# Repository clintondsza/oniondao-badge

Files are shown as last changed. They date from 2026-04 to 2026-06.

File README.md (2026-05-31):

# OnionDAO Badge

An open-source, hacker-conference-style electronic badge built around the
**ESP32-S3-WROOM-1-N8R8** (8 MB flash + 8 MB Octal PSRAM), with swappable
RF / audio / storage modules, an e-paper
(or TFT) display socket, a secure element, an I²C IO expander for the button
matrix, and dual side-mounted expansion ports for hardware mods.

Designed in **KiCad 9.0.3**. The hardware (schematics, PCB, BOM, fabrication
outputs, STEP model) lives in [`pcb/`](pcb). The software lives in
[`software/`](software) and is community-driven — PRs welcome.

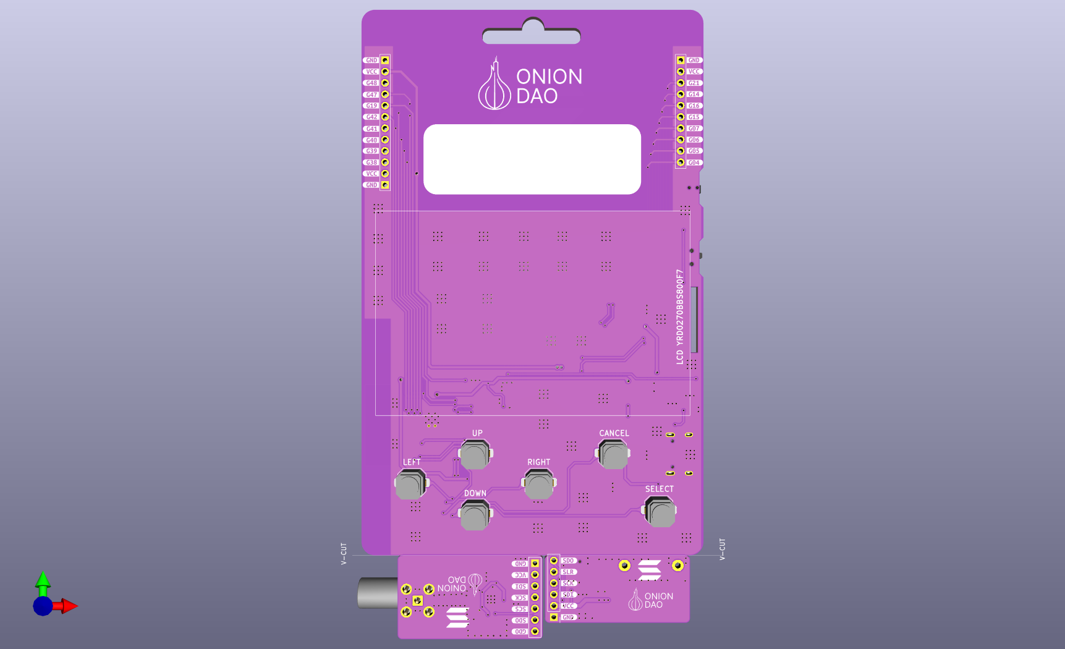
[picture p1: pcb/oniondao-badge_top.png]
Top

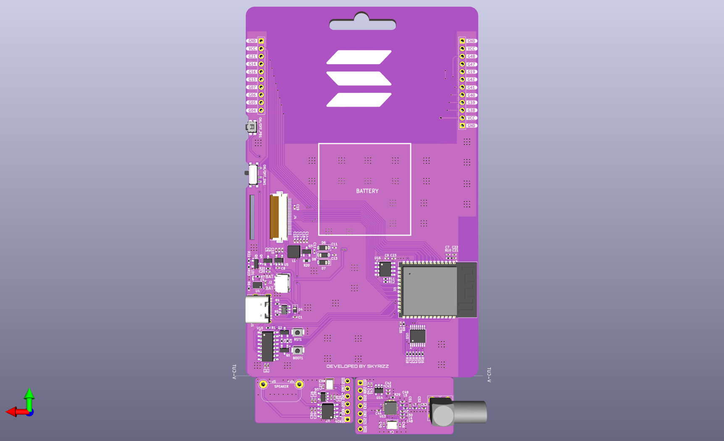
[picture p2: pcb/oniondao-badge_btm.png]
Bottom


---

## Table of Contents

- [At a Glance](#at-a-glance)
- [Block Diagram](#block-diagram)
- [Repository Layout](#repository-layout)
- [Hardware Documentation](#hardware-documentation)
- [Quick Start (Software)](#quick-start-software)
- [Pinout Cheat Sheet](#pinout-cheat-sheet)
- [Contributing Software Mods & Guides](#contributing-software-mods--guides)
- [License](#license)

---

## At a Glance

| | |
|---|---|
| **MCU** | Espressif **ESP32-S3-WROOM-1-N8R8** (Wi-Fi + BT 5.0 LE, dual-core Xtensa LX7) |
| **Memory** | 8 MB quad-SPI flash (`N8`) + 8 MB **Octal-SPI (OPI)** PSRAM (`R8`) |
| **USB / Serial** | WCH **CH340C** USB-UART bridge w/ DTR/RTS auto-reset |
| **Secure Element** | Microchip **ATECC608B-SSHDA** (I²C, power-gated) |
| **IO Expander** | TI **TCA9534** (I²C, addr `0x20`) driving the 6-button matrix (PB1–PB6) |
| **Display** | 24-pin socket (`J4`) — E-Ink / TFT SPI with `BUSY`, `RST`, `DC`, `CS`, `SCK`, `MOSI` |
| **Audio (mod)** | NS4168 I²S amplifier + SPH0641 PDM mic (Sound Module) |
| **Sub-GHz (mod)** | TI **CC1101** SPI radio (315/433/868/915 MHz) |
| **Expansion** | Left port `J8` (10 pin) + Right port `J10` (10 pin) — VCC / GND + GPIO |
| **GPIO Used** | 28 of the available ESP32-S3 GPIOs |
| **Power Gate** | Q5 (SS8050) on `GPIO18` enables the peripheral `PWR` rail |

## Block Diagram

```
                              ┌────────────────────────┐
        USB-C ── CH340C ──────│ UART0  GPIO43/44       │
                              │                        │
   ┌── BOOT btn ── GPIO0 ─────│ STRAP                  │
   │                          │                        │
   │   ATECC608B ──┬─ SCL G9 ─│ I²C0                   │
   │   TCA9534  ──┘  SDA G10  │   ◄── INT G1 (PBINT)   │
   │                          │                        │
   │   J4 Display ─SPI──── G11/12/13/14/17/21          │
   │                          │                        │
   │   J8 Left   ── G48/47/19/42/41/40                  │  ESP32-S3-WROOM-1
   │   J10 Right ── G38/39/16/15/7/6/5/4                │
   │                          │                        │
   │   GPIO18 ──── Q5 ────────│ PWR rail to gated peripherals
   │   GPIO8  ──── SE_EN  ────│ ATECC608B power gate
   │                          └────────────────────────┘
   │
   └── PB1..PB6 ── TCA9534 P0..P5 ──► INT line ── GPIO1
```

## Repository Layout

```
oniondao-badge/
├── README.md                   ← you are here
├── pcb/                        ← KiCad 9.0.3 hardware sources
│   ├── oniondao-badge.kicad_pro
│   ├── oniondao-badge.kicad_sch         (top-level schematic)
│   ├── oniondao-badge.kicad_pcb         (board layout)
│   ├── CC1101_MOD.kicad_sch              (Sub-GHz RF module)
│   ├── SOUND_MOD.kicad_sch               (I²S amp + PDM mic)
│   ├── oniondao-badge.step              (full 3D model)
│   ├── 3d/                               (additional STEP assets)
│   ├── production/                       (gerbers, BOMs, netlist)
│   ├── oniondao-badge_top.png           (board render — top)
│   ├── oniondao-badge_btm.png           (board render — bottom)
│   └── oniondao badge.html                   (interactive IO reference)
├── docs/
│   ├── HARDWARE.md             ← deep dive on every subsystem
│   ├── PINOUT.md               ← full GPIO ↔ net ↔ peripheral table
│   ├── MODULES.md              ← swappable modules & their pinmaps
│   └── CONTRIBUTING.md         ← how to PR a mod / guide / example
└── software/
    ├── README.md
    ├── examples/               ← minimal, single-feature firmware
    ├── guides/                 ← end-to-end how-tos
    └── mods/                   ← community firmware mods & forks
```

> **Tip:** open [`pcb/oniondao badge.html`](pcb/oniondao%20badge.html) in a browser for
> a colour-coded, searchable, filterable view of the IO table. It is the
> source of truth that [`docs/PINOUT.md`](docs/PINOUT.md) mirrors in markdown.

## Hardware Documentation

The docs are split so you can read just what you need:

- **[docs/HARDWARE.md](docs/HARDWARE.md)** — overview of every subsystem on
  the board: power, USB/UART, boot circuit, I²C bus, display socket, secure
  element, button matrix, expansion ports.
- **[docs/PINOUT.md](docs/PINOUT.md)** — the complete GPIO map: every used
  pin, its net, direction, interface, and the peripheral it connects to.
- **[docs/MODULES.md](docs/MODULES.md)** — the swappable modules
  (CC1101 / Sound) and the shared-GPIO assignments. Read
  this **first** if you are writing firmware that touches the side ports.

### Manufacturing

- Gerbers, drill files, and pick-and-place are zipped in
  [`pcb/production/oniondao-badge.zip`](pcb/production/oniondao-badge.zip).
- BOMs per variant: `bom-list_cc1101.xlsx`, `bom-list_sound.xlsx`,
  `bom-list_lanyard_new.xlsx`.
- IPC-D-356 netlist: `pcb/production/netlist.ipc`.

## Quick Start (Software)

The badge enumerates as a standard CH340 serial port, so any ESP32-S3 toolchain
works at the hardware level — **ESP-IDF**, **Arduino-ESP32**, **PlatformIO**,
**MicroPython**, **CircuitPython**.

> **Building the firmware in this repo?** The projects under `software/` are
> **ESP-IDF v5.5.x** projects (with the Arduino core as a component). Follow the
> step-by-step **[VS Code + ESP-IDF setup guide](software/guides/esp-idf-vscode-setup.md)**
> to install the toolchain and flash a badge.

### Memory configuration (N8R8)

The populated module is an **ESP32-S3-WROOM-1-N8R8**: 8 MB flash + 8 MB PSRAM
in **Octal (OPI)** mode. PSRAM will not initialise unless you select Octal
mode explicitly — quad-mode defaults silently disable it. Set per toolchain:

| Toolchain | Flash | PSRAM |
|---|---|---|
| **ESP-IDF** (`sdkconfig`) | `CONFIG_ESPTOOLPY_FLASHSIZE_8MB=y` | `CONFIG_SPIRAM=y`, `CONFIG_SPIRAM_MODE_OCT=y`, `CONFIG_SPIRAM_SPEED_80M=y` |
| **Arduino-ESP32** (boards menu) | `Flash Size = 8MB` | `PSRAM = OPI PSRAM` |
| **PlatformIO** | `board_build.flash_size = 8MB` | `board_build.arduino.memory_type = qio_opi` + `-DBOARD_HAS_PSRAM` |

The firmware projects under [`software/`](software) already carry these settings
in their `sdkconfig.defaults` — see the
[VS Code + ESP-IDF setup guide](software/guides/esp-idf-vscode-setup.md).

### Programming

1. Plug in USB-C. The CH340C + DTR/RTS auto-reset circuit (Q1/Q2 on
   `GPIO0`/`EN`) means **you do not need to hold BOOT** — the toolchain
   strobes it for you.
2. If auto-reset ever fails: hold **BOOT** (the SW button tied to `GPIO0`),
   tap **RESET**, release **BOOT**, then flash.

### Minimal Arduino example

```cpp
// Blink the peripheral power rail and read the BOOT button.
#define PWR_EN   18    // Q5 base — enables peripheral VCC
#define BOOT_BTN 0     // strapping pin, doubles as user button after boot

void setup() {
  Serial.begin(115200);          // CH340C on UART0 (GPIO43/44)
  pinMode(PWR_EN, OUTPUT);
  pinMode(BOOT_BTN, INPUT_PULLUP);
  digitalWrite(PWR_EN, HIGH);    // power-up peripherals
}

void loop() {
  Serial.printf("BOOT btn: %d\n", digitalRead(BOOT_BTN));
  delay(250);
}
```

### Reading the 6 user buttons

The PB1–PB6 buttons are wired to the **TCA9534** IO expander (I²C
addr `0x20`), not directly to the ESP32. A button press pulls `PBINT`
(`GPIO1`) low; read the expander register over I²C to find which one.

```cpp
#include <Wire.h>
#define SCL_PIN 9
#define SDA_PIN 10
#define PBINT   1
#define TCA9534 0x20

void buttonISR();

void setup() {
  Wire.begin(SDA_PIN, SCL_PIN, 400000);   // I²C Fast Mode
  pinMode(PBINT, INPUT_PULLUP);
  attachInterrupt(PBINT, buttonISR, FALLING);
}

void buttonISR() {
  Wire.beginTransmission(TCA9534);
  Wire.write(0x00);                       // Input port register
  Wire.endTransmission(false);
  Wire.requestFrom(TCA9534, 1);
  uint8_t state = Wire.read();            // bit N low = PB(N+1) pressed
  // ... dispatch on `state`
}
```

See [`software/examples/`](software/examples) for working firmware
covering display, audio, RF, and the secure element.

## Pinout Cheat Sheet

Source of truth: [`pcb/oniondao badge.html`](pcb/oniondao%20badge.html) — open it in
a browser for the filterable view. The markdown mirror is
[`docs/PINOUT.md`](docs/PINOUT.md).

### Core / UART / Boot

| GPIO | Net | Dir | Peripheral | Notes |
|---|-----|-----|---|---|
| `GPIO0`  | `IO0` | IN  | BOOT button + auto-reset Q1/Q2 | **Strapping** — LOW at power-on → download mode |
| `GPIO43` | `TX0` | OUT | CH340C RXD (via R1 220Ω) | UART0 TX |
| `GPIO44` | `RX0` | IN  | CH340C TXD | UART0 RX |
| `GPIO18` | `PWR` | OUT | Q5 SS8050 → peripheral VCC | HIGH = enable power gate |

### I²C Bus (Security Chip + IO Expander)

| GPIO | Net | Dir | Peripheral | Notes |
|---|-----|-----|---|---|
| `GPIO9`  | `SCL` | OUT | TCA9534 + ATECC608B | 400 kHz max (Fast Mode) |
| `GPIO10` | `SDA` | I/O | TCA9534 + ATECC608B | TCA9534 @ `0x20` |
| `GPIO1`  | `PBINT` | IN  | TCA9534 INT → PB1..PB6 | Active LOW, `attachInterrupt(FALLING)` |
| `GPIO8`  | `SE_EN` | OUT | ATECC608B enable | HIGH = active — power-gate when idle |

### Display Socket J4 (E-Ink / TFT SPI)

| GPIO | Net | Dir | J4 Pin | Function |
|---|-----|-----|---|---|
| `GPIO14` | `RS` | OUT | 3  | Display RESET — LOW ≥10 ms during init |
| `GPIO13` | `DC` | OUT | 11 | Data / Command select (HIGH = data) |
| `GPIO12` | `CS` | OUT | 12 | SPI Chip Select (active LOW) |
| `GPIO11` | `SCK`  | OUT | 13 | SPI Clock |
| `GPIO21` | `BUSY` | IN  | 9  | Busy — wait LOW before next refresh |
| `GPIO17` | `SDI`  | OUT | 23 | SPI MOSI |

### Expansion Ports

| Pin | Left (J8) | Right (J10) |
|-----|---|---|
| 1 | GND | GND |
| 2 | VCC | VCC |
| 3 | `GPIO48`  | `GPIO38` |
| 4 | `GPIO47`  | `GPIO39` |
| 5 | `GPIO19`  | `GPIO16` |
| 6 | `GPIO42`  | `GPIO15` |
| 7 | `GPIO41`  | `GPIO7`  |
| 8 | `GPIO40`  | `GPIO6`  |
| 9 | VCC | `GPIO5`  |
| 10  | GND | `GPIO4`  |

> **Heads-up:** the **Sound Module** and **CC1101 Module** both reuse the
> same set of side-port GPIOs. Only one module's firmware can drive those
> pins at a time. See [`docs/MODULES.md`](docs/MODULES.md) for the exact
> overlap and how to choose at compile time.

## Contributing Software Mods & Guides

We want this badge to be a **playground**. If you wrote a synth, a CC1101
replay tool, an OLED demo, a CTF challenge, a CircuitPython port — open a PR
into [`software/`](software).

1. Pick the right folder:
   - `software/examples/` — one feature, minimal code, no story.
   - `software/guides/` — step-by-step tutorials (markdown + code).
   - `software/mods/` — full firmware projects / forks / variants.
2. Add a folder named after your mod, with a `README.md` describing what it
   does, which GPIOs / modules it requires, and how to build & flash.
3. Open a PR. Use the template in `.github/PULL_REQUEST_TEMPLATE.md`.

Full guidelines: [`docs/CONTRIBUTING.md`](docs/CONTRIBUTING.md).

## License

Hardware sources (KiCad files under `pcb/`) are released under
**CERN-OHL-S v2** unless a file header states otherwise. Software in
`software/` defaults to **MIT** — individual mods may override in their own
folder's `LICENSE` file.

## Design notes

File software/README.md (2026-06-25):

# OnionDAO Badge — Pin Test 🔌

## What is this thing, in one sentence?

This is a little computer program that checks if someone **soldered the
metal pins on a circuit board correctly** — like a doctor giving a checkup
to a freshly-built electronic badge, before anything else gets plugged
into it.

## Wait, what's a "badge" and why does it need a checkup?

The [OnionDAO Badge](https://github.com/OnionDAO-git/oniondao-badge) is a
small electronic gadget (about the size of a name tag) built around a chip
called an **ESP32-S3** — basically a tiny computer brain. People build
these badges by hand, which means **soldering**: melting a bit of metal to
glue wires and pins onto the board so electricity can flow through them.

Soldering by hand is a bit like tying your shoelaces really, really
small — it's easy to do it slightly wrong without noticing. A "bad joint"
(a pin that isn't actually connected, or is touching its neighbor when it
shouldn't be) can make the whole badge act broken later, and it's hard to
tell *why* it's broken unless you check the soldering itself first.

So: **solder first → test with this project → THEN plug in the fun
add-on parts.** That way, if something doesn't work later, you already
know your soldering was fine, and the problem is somewhere else.

## A 30-second crash course on electricity (skip if you already get this)

- **Voltage** is basically "electrical pressure" — like water pressure in a
  pipe. This chip uses two voltage levels to mean something: **0 volts**
  means "off" / "logic 0", and **3.3 volts** means "on" / "logic 1". That's
  it — there's no in-between meaning, it's just a digital on/off switch
  made out of electricity instead of a mechanical lever.
- **GND** (ground) is the "0 volts" reference point that every other
  measurement compares against — like sea level on a map of mountain
  heights. You always put one multimeter probe on GND so the other probe's
  number means something.
- **A pin** is just one little metal leg of the chip (or the header it's
  soldered to) that can be told "be 3.3V" or "be 0V", or can be read to see
  which one it currently is.
- **GPIO** stands for "General Purpose Input/Output" — a fancy way of
  saying "a pin the program can freely turn on/off (output) or read
  (input)," as opposed to pins with one fixed special job.

## What does this program actually check? (3 tests)

Think of it like a 3-question quiz the badge has to pass:

### 1. "Can every pin turn on and off?" (the GPIO toggle test)
The badge has two little plastic connector strips called `J8` and `J10`
sticking out of its sides — each one has several metal pins. This test
makes the chip turn **each pin** on (3.3 volts of electricity) and off
(0 volts) three times in a row, one pin at a time, like flicking a light
switch on and off.

While it does that, **you** hold a multimeter (a tool that measures
electricity) against that same pin and watch the number jump between
`0V` and `3.3V`. If it jumps the way it's supposed to, that pin's solder
joint is good. If it's stuck, or doesn't move, that pin has a soldering
problem.

### 2. "Does the radio chip actually work?" (the CC1101 check)
A **CC1101** is a small radio chip — it can send and receive radio
signals, kind of like a tiny walkie-talkie part. If you've soldered one of
these onto the badge, this test talks to it over a digital connection
called **SPI** (think of SPI as a tiny, very fast, 4-wire conversation
between two chips: one wire to send data, one to receive data, one
"ticking" clock wire so both sides stay in sync, and one "are you
listening?" select wire) and asks it "what are you?" The chip answers back
with two ID numbers, called **PARTNUM** and **VERSION**.

Then, just to be extra sure, the program tells the chip "send me a
ticking clock signal" on one of its wires (called **GDO0**) and
**measures how fast it ticks** by counting how many times the wire
flips between 0V and 3.3V in a tiny 50-millisecond window. If the speed
matches what's expected (about 135,400 ticks per second — which comes
from the chip's internal crystal, divided by 192), that proves the wire
is connected correctly all the way from the chip to the badge — no
multimeter needed for this one, the program checks it automatically!

Why bother measuring a clock instead of just trusting the ID numbers?
Because, surprisingly, **a CC1101 reporting `VERSION = 0x00` is normal**
on plenty of genuine chips — so the ID alone can't tell you "good" from
"bad". A wire that's actually carrying a fast, correct-speed clock signal
is much harder to fake by accident, so it's the stronger proof.

### 3. "Can it actually make a sound?" (the speaker test)
If you've soldered on a **Sound module** (a tiny amplifier chip called an
**NS4168** paired with a microphone chip called an **SPH0641**), this test
sends digital audio data to it over a connection called **I2S** (a
standard way of streaming digital sound between chips — kind of like SPI,
but specialized for audio: it has a clock wire, a "left channel or right
channel right now?" wire, and a data wire) and plays a steady musical note
(440 Hz — the same note an orchestra tunes to before a concert) for
3 seconds.

There's no clever electronic way to "ask" a speaker if it's working — the
only test is **your own ears**. If you hear a clean, steady beep, it
passed. If you hear nothing, or something crackly, the wiring needs a
second look. (The microphone half of the module isn't tested here — only
the speaker/amplifier side.)

A small detail that trips people up: right after the tone finishes, the
program explicitly switches the audio channel off. Without that step, the
sound chip's hardware would keep looping its very last chunk of sound data
forever instead of going quiet — so a properly-finished test should end in
total silence, not a stuck buzzing noise.

### Bonus: it draws the results on the badge's little screen
The badge has a small black-and-white screen (an "e-paper" display — the
same kind of screen used in e-readers like a Kindle). E-paper is special
because, once it draws a picture, **it keeps showing that picture even
with zero power applied** — it only needs electricity for the brief
moment it's actually changing the image, not to keep displaying it. After
each test, the program writes the results right onto that screen, so you
don't even need a computer or Serial Monitor open to see how it went —
just look at the badge itself.

At the very end, the program tells the screen to "hibernate" (go into its
lowest power-use state) since there's nothing left to draw.

## What order does everything happen in? (the boot sequence)

When you plug the badge in and it powers up, here's exactly what happens,
in order — this matches the code in `firmware/main/main.cpp` top to
bottom:

1. **Serial port starts up** at 115200 baud (baud = "how many bits per
   second the text connection sends" — 115200 is just a commonly-used
   speed both sides agree on ahead of time) and waits 2 seconds so you
   have time to open the Serial Monitor before anything important prints.
2. **The screen turns on** and shows "Starting pin test... GPIO toggle
   pass running (watch multimeter now)" — your cue to grab the
   multimeter.
3. **The module power rail switches on** (`PIN_PWR_EN` goes HIGH). This
   badge deliberately routes power to the plug-in modules through a
   transistor controlled by one GPIO, instead of wiring them straight to
   the battery — that way the chip can cut power to modules it isn't
   using, to save battery. The program waits 5 milliseconds for the
   modules' own power supplies to settle before touching them.
4. **Test 1 runs**: all 14 candidate pins toggle HIGH/LOW/HIGH/LOW/HIGH/LOW
   (3 full cycles), one at a time, 1 second per half-cycle — this is your
   multimeter-watching window. The screen updates to "GPIO toggle: DONE".
5. **The CC1101 radio link is set up once** (SPI bus started) and
   **the Sound module is set up once** (I2S channel started, amplifier
   enabled) — both are initialized a single time here and reused, on
   purpose (see the pitfalls section below for why).
6. **Test 2 runs**: the CC1101 link check (ID registers + GDO0 clock
   frequency). Result goes to both the Serial Monitor and the screen.
7. **Test 3 runs**: the 3-second, 440 Hz tone plays through the Sound
   module. Result (well, the fact that it ran) goes to both Serial and
   the screen.
8. **A final summary screen** shows all three results at once, and the
   program settles into doing nothing forever (just an idle loop) — it
   will not repeat any test until you power-cycle or re-flash it.

All three tests run **once** per power-on, then the program just sits
there quietly — it won't keep re-triggering the tone or re-running the
SPI check on a loop.

## What's inside this folder? (a map)

```
oniondao-pin-test/
├── README.md                 ← you are here!
├── docs/
│   └── testing-guide.md      ← a full step-by-step guide, written for
│                                someone who has NEVER used a multimeter
│                                before. Start here if testing is new to you.
├── firmware/                  ← the "real" version of the program
│   ├── main/
│   │   └── main.cpp          ← all the actual test code lives here
│   ├── CMakeLists.txt        ← build instructions (tells the computer
│   │                            how to compile the program)
│   └── sdkconfig.defaults    ← chip configuration settings
├── arduino/
│   └── pin_test.ino          ← a simpler, beginner-friendly version of
│                                test #1 (the pin toggle test) only —
│                                no screen, no radio test, no sound test.
│                                Good if you just want to quickly check
│                                pins using the easier Arduino IDE.
└── components/                ← borrowed code other people wrote, that
                                  this project needs to draw on the
                                  e-paper screen. You don't need to read
                                  or touch these — they're just helper
                                  libraries, tucked in here so this project
                                  works completely on its own without
                                  needing the main badge repo too.
```

A bit more on that `components/` folder, since it's the biggest pile of
files in here and might look intimidating: it contains three popular,
open-source Arduino libraries, copied in as-is so the build doesn't have
to fetch them separately:

- **GxEPD2** — the library that actually knows how to talk to e-paper
  screens (there are hundreds of slightly different e-paper screen models
  in the world; this library supports a huge number of them, which is why
  there are so many similarly-named files in `components/GxEPD2/src/`).
  This badge only uses one of those screen drivers
  (`GxEPD2_270_GDEY027T91`), but the whole library comes along anyway.
- **Adafruit_GFX** — a generic "draw shapes and text" toolkit that GxEPD2
  builds on top of (so the same drawing code style works across all sorts
  of Adafruit displays, not just e-paper).
- **Adafruit_BusIO** — small helper code for talking over SPI/I2C, used
  internally by the other two libraries.

You will never need to edit anything inside `components/` — if you do
need to update one of these libraries, the normal way is to drop in a
newer copy of the whole library, not hand-edit files inside it.

## Which pins go where?

The badge's two connectors are wired to two add-on modules like this:

**CC1101 radio module → connector `J8`:**

| Radio module wire | Goes to badge pin | What it's for |
|---|---|---|
| SDI | G48 | data going INTO the radio chip |
| SCK | G47 | the shared clock "tick" wire |
| SCS | G19 | "are you listening?" select wire |
| SDO | G42 | data coming OUT of the radio chip |
| GDO | G41 | the chip's general-purpose signal pin (used here for the clock test) |

**Sound module → connector `J10`:**

| Sound module wire | Goes to badge pin | What it's for |
|---|---|---|
| SDI | G38 | data wire (despite the name, used as I2S clock input on this badge) |
| SCK | G39 | bit clock for the audio stream |
| SLR (WS) | G16 | word select — "is this sample for the left or right speaker?" |
| SDO | G15 | the actual digital audio data |
| CTR (CTRL) | G07 | turns the amplifier chip on/off |

(Plus a GND-to-GND wire and a VCC-to-VCC wire on each module, for power
and a shared ground reference.) If your own badge is wired differently,
you can change these pin numbers near the top of `firmware/main/main.cpp`.

Every pin the GPIO toggle test cycles through, in the exact order it runs,
straight from `firmware/main/main.cpp` (the Arduino sketch version checks
the same set, just labeled slightly differently since it has to cover
three possible wiring variants at once):

| Pin | Connector / slot | Used for |
|---|---|---|
| G48 | J8 pin 3 | CC1101 SDI |
| G47 | J8 pin 4 | CC1101 SCK |
| G19 | J8 pin 5 | CC1101 SCS |
| G42 | J8 pin 6 | CC1101 SDO |
| G41 | J8 pin 7 | CC1101 GDO |
| G40 | J8 pin 8 | spare (not used by this wiring) |
| G38 | J10 pin 3 | Sound SDI |
| G39 | J10 pin 4 | Sound SCK |
| G16 | J10 pin 5 | Sound SLR |
| G15 | J10 pin 6 | Sound SDO |
| G07 | J10 pin 7 | Sound CTR |
| G06 | J10 pin 8 | spare |
| G05 | J10 pin 9 | spare |
| G04 | J10 pin 10 | spare |

The "spare" pins still get toggled and tested even though no module wire
is currently planned for them — partly to check that header's solder
joint anyway, and partly so the same firmware keeps working if a future
module uses one of them.

There's also a separate set of pins, **not part of the toggle test**,
permanently wired to the badge's built-in e-paper screen (these don't
need testing the same way, since the screen either visibly works or it
visibly doesn't):

| Pin | Wire to the screen |
|---|---|
| G11 | SCK (clock) |
| G12 | CS (chip select) |
| G13 | DC (data/command select) |
| G14 | RST (reset) |
| G17 | MOSI (data) |
| G21 | BUSY (screen says "I'm still drawing, wait") |

And one more important pin: **G18** is `PIN_PWR_EN` — the single GPIO that
switches power to *both* plug-in modules on and off. If a module isn't
powering up at all, this is the first pin worth checking.

## How do I actually run it?

There are two ways, depending on how much you want to test:

### Option A — the full version (all 3 tests + screen)

This needs a tool called **ESP-IDF** (version 5.5.x) installed on your
computer — it's the official toolkit for programming ESP32 chips. Once
that's set up:

```powershell
cd firmware
idf.py set-target esp32s3
idf.py build
idf.py -p COM<N> flash monitor
```

(Swap `COM<N>` for whatever COM port your badge shows up as when you plug
it in via USB — on Windows you can find this in Device Manager.)

The first time you build, it automatically downloads one more helper
library (`arduino-esp32` — the Arduino-style programming layer for ESP32
chips, here used inside an ESP-IDF project) from the internet, based on
what's listed in `firmware/main/idf_component.yml`. Everything else
(the screen-drawing libraries) is already included in the `components/`
folder, so the project doesn't depend on anything outside this repo
except that one download.

A quick word on what each build-related file actually does, if you're
curious:
- `firmware/CMakeLists.txt` — the top-level "how to build this whole
  project" file. It also points the build at the `components/` folder so
  the vendored libraries get found.
- `firmware/main/CMakeLists.txt` — the same idea, scoped to just the
  `main` folder (the actual program code).
- `firmware/main/idf_component.yml` — a short list of which external
  libraries to automatically download (just `arduino-esp32` here) and
  which version to use.
- `firmware/sdkconfig.defaults` — chip-level settings (things like memory
  layout) that get baked in before the first build.

**Important version note:** this firmware is pinned to `arduino-esp32`
v3.3.8, which itself is built against ESP-IDF v5.5.4. If you have a
different ESP-IDF version installed (check with `idf.py --version`),
either switch to v5.5.x or expect possible build errors — these two
pieces need to stay in step with each other.

### Option B — the simple version (just the pin toggle test)

If you don't have ESP-IDF set up, or you just want the quickest possible
check of your soldering with no screen and no radio/sound checks, open
[`arduino/pin_test.ino`](arduino/pin_test.ino) in the **Arduino IDE**
instead. Pick "ESP32S3 Dev Module" as the board, upload it, and open the
Serial Monitor at 115200 baud. It covers every possible pin across all
the different wiring layouts, so it works no matter which exact module
wiring your badge uses.

## I don't even have a multimeter yet / I've never used one

No problem — that's exactly who [`docs/testing-guide.md`](docs/testing-guide.md)
was written for. It explains, completely from scratch:
- what a multimeter is and which buttons/dials to use,
- how to check your soldering is even connected at all, **before you ever
  turn the badge on** (this is called a "continuity test" and it can find
  a bad joint with no power needed),
- how to read the results from this program once the badge is powered on,
- a list of weird-looking readings that are actually totally normal
  (so you don't panic over nothing).

## Frequently asked questions

**Do I need both the CC1101 radio and the Sound module to use this?**
No. The GPIO toggle test (test 1) works on a bare board with nothing
plugged in. Tests 2 and 3 simply won't tell you anything useful about a
module you haven't soldered/wired yet — but they also won't crash or
break anything if you skip them.

**Can I test just one module and not the other?**
Yes — just don't wire up the one you're skipping, or ignore its result on
the screen. Each test is independent of the other two.

**What if my badge's wiring doesn't match the tables above?**
Edit the pin number constants near the top of `firmware/main/main.cpp`
(or `arduino/pin_test.ino` for the simple version) to match your actual
wiring, then rebuild and re-flash.

**Why does the program only run the tests once instead of looping?**
Because re-initializing SPI or I2S on every loop pass eventually starves
shared hardware resources (DMA channels / interrupts) and freezes the
next transfer — a real bug hit during development of this project. Doing
each setup step exactly once in `setup()` and reusing it avoids that
entirely.

**I plugged in the badge but see nothing on Serial / the screen — is it
broken?**
Give it the full 2-second startup delay, double-check the COM port and
baud rate (115200) in your Serial Monitor, and check the screen's own
wiring (G11/G12/G13/G14/G17/G21 above) — a screen wiring problem won't
stop the actual tests from running, it'll just stop you from seeing the
results that way (check the Serial Monitor instead in that case).

## Quick troubleshooting cheat-sheet

- **A pin's voltage doesn't move during the toggle test** → that pin's
  solder joint (or the wire to it) likely has a problem.
- **CC1101 `VERSION` reads as `0x00`** → that's actually fine, lots of
  real radio chips report that. Trust the GDO0 frequency check instead.
- **CC1101 readings are all `0xFF`** → that usually means nothing is
  responding at all (bad SDO wire, no power, or no chip).
- **No sound plays** → double check the speaker module's wiring and that
  its power is actually on.
- **A module's power pin reads 0 volts** → this badge deliberately turns
  module power on/off through software, so 0V is expected *before* the
  program tells it to turn on — not a fault by itself.

## Why was this built?

It came out of a real, hands-on soldering session for the OnionDAO
Badge — figuring out, in person, what actually goes wrong when an
ordinary person solders these tiny pins for the first time, and turning
those lessons into an automatic check anyone else can run.

## Glossary — every techy word in this README, explained simply

| Word | What it means here |
|---|---|
| **Solder / solder joint** | The blob of melted metal that physically and electrically connects a pin to the board. A "bad joint" means a weak, missing, or accidental connection. |
| **Firmware** | The program that runs directly on a chip (as opposed to an app on your phone or computer) — that's what everything in `firmware/` and `arduino/` is. |
| **GPIO** | A general-purpose pin the program can set to on/off or read from — see the crash-course section above. |
| **Voltage / Volts (V)** | "Electrical pressure." This chip uses 0V = off, 3.3V = on. |
| **GND (ground)** | The 0-volt reference point everything else is measured against. |
| **Multimeter** | A handheld tool for measuring voltage, continuity (is something connected?), and more. |
| **Continuity test** | Checking, with the power OFF, whether two points are physically connected through solder/wire — usually shown with a beep. |
| **SPI** | A fast 4-wire way for two chips to talk: data-out, data-in, clock, and select. Used here for the CC1101 radio. |
| **I2S** | A standard way to stream digital audio between chips. Used here for the Sound module. |
| **CC1101** | A specific brand/model of sub-GHz radio chip. |
| **NS4168 / SPH0641** | The specific amplifier chip and microphone chip that make up the "Sound module." |
| **GDO0** | One of the CC1101's general-purpose signal pins; this firmware uses it to output a test clock signal. |
| **PARTNUM / VERSION** | Two ID numbers a CC1101 chip reports back when asked "what are you?" |
| **e-paper / e-ink** | A type of screen that keeps showing its last image with no power, only using electricity while actually changing. |
| **Baud rate** | How fast a serial (text) connection sends data, measured in bits per second. This project uses 115200. |
| **Serial Monitor** | A window in your computer's IDE/tool that shows text the chip is printing over USB. |
| **ESP32-S3** | The specific computer chip this badge is built around. |
| **ESP-IDF** | Espressif's (the chip maker's) official software toolkit for programming ESP32 chips — the "full version" build path uses this. |
| **Arduino IDE** | A simpler, beginner-friendly programming tool that the "Option B" simple test uses instead of ESP-IDF. |
| **`idf.py`** | The command-line tool ESP-IDF gives you to build and flash (upload) firmware. |
| **Flash (verb)** | Uploading a compiled program onto the chip's permanent memory. |
| **DMA** | "Direct Memory Access" — a hardware shortcut that lets peripherals like SPI/I2S move data without constantly bothering the main chip; mentioned here because re-initializing it carelessly can freeze a transfer. |

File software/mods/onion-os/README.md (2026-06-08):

# Onion OS

Onion OS is the badge firmware target for linking a physical OnionDAO badge to
an attendee profile through the Onion server.

This is an ESP-IDF v5.5.x project with Arduino as a component, matching the
other badge firmware in this repo.

## Implemented

- Persistent per-badge hardware ID stored in NVS.
- Hardcoded WiFi for `CIC Guest` / `1nnovation`.
- Hardcoded Onion API server URL: `https://oniondao.dev`.
- Hardcoded MQTT broker URL: `mqtt://shortline.proxy.rlwy.net:20928`.
- Baked-in MQTT broker credentials for the `oniondao` user.
- HTTP badge handshake:
  - `POST /api/badge/handshake`
- MQTT badge bridge:
  - publishes `oniondao/badge/handshake`
  - subscribes to `oniondao/badge/{onionId}/handshake/accepted`
  - subscribes to `oniondao/badge/{onionId}/link/request`
  - subscribes to `oniondao/badge/{onionId}/transaction/request`
  - subscribes to `oniondao/badge/{onionId}/lua/request`
  - publishes link, transaction, and Lua responses.
- E-paper status and approval UI.
- Three-second boot splash generated from `main/logo.png`.
- Home menu showing linked username, Onion balance, script explorer, profile
  refresh, and settings actions.
- SELECT/CANCEL approval controls through the TCA9534 button expander.
- HTTP fallback for link and transaction responses.
- Script manifest download and SPIFFS storage.
- Lua script execution through Espressif's Lua component.
- Server-pushed Lua script approval popup, install, and run flow.
- Partial-refresh e-paper rendering: a retained `GFXcanvas1` framebuffer diffs
  against the previous frame and uses `setPartialWindow` for small changes
  (~300–500 ms, no flash) and `setFullWindow` only when >75 % of the panel
  changes or every 30 partial updates (ghost clearing). Lua canvas frames go
  through the same path via bit-invert copy.
- MQTT large-payload reassembly: fragmented payloads (e.g. large Lua scripts)
  are accumulated across `MQTT_EVENT_DATA` events before being parsed, fixing
  the "Bad MQTT JSON" error on server-pushed scripts.
- Badge-owned Solana Ed25519 wallet generation.
- ATECC608B-backed seed wrapping and approval attestation.
- Solana transaction signing for server-built burn/transfer transactions.
- PSRAM-backed Lua script loading (scripts up to 192 KB).
- Lua key/value store (NVS), SHA-256, and username APIs for script state and
  authenticated pairing.
- Per-peer ESP-NOW LMK encryption and a 128-deep RX queue for real-time
  streaming scripts.
- Lua WiFi disconnect/reconnect with the 802.11 LR PHY for fixed-channel
  ESP-NOW range.
- Streaming-capable Sound module APIs: deep mic DMA buffering, capture stats,
  startup-transient discard, and amp unmute/drain handling.

## Solana Key Custody

The badge signs Solana transactions with a software Ed25519 key because the
ATECC608B does not provide Ed25519 signing. The Ed25519 seed is generated on the
ESP32-S3 and is never stored plaintext. It is encrypted in NVS with
XChaCha20-Poly1305 using a wrapping key derived from an ATECC608B HMAC slot.

Production badges must provision `ATECC_HMAC_SLOT` (`10` in the firmware) with a
non-readable HMAC-capable secret. If that slot is empty, readable, locked with
incompatible config, or uses a different provisioning policy, wallet creation and
transaction approval will fail on the badge.

Link and transaction approvals include an `attestation` JSON object containing
the ATECC serial number, HMAC slot, purpose, nonce, subject, and HMAC. The
current `../landing-2026` server routes accept the extra fields but do not yet
verify them. Server-side verification needs the provisioning database or another
trusted record of the per-badge slot secret.

The CryptoAuthLib defaults are pinned for the badge hardware:

- SDA: GPIO 10
- SCL: GPIO 9
- ATECC address: `0xC0` 8-bit (`0x60` 7-bit)
- I2C speed: 100 kHz

## Updating Without Losing the Solana Key

The wrapped Solana wallet seed is stored in the `nvs` flash partition, not in
the Onion OS app partition. A normal firmware update preserves the key, cached
wallet address, hardware ID, link state, API key, MQTT settings, and script
manifest URL. A full flash erase deletes that state.

For normal updates, flash only the app:

```sh
idf.py -p /dev/cu.usbserial-10 flash
```

Or use the helper script, which does not erase flash:

```sh
scripts/build-flash.sh --port /dev/cu.usbserial-10
scripts/build-flash.sh --port /dev/cu.usbserial-10 --monitor
```

Do not run these commands on a badge whose wallet should be kept:

```sh
idf.py erase-flash
esptool.py erase_flash
```

Before a high-risk update, you can back up the NVS partition:

```sh
esptool.py --chip esp32s3 --port /dev/cu.usbserial-10 read_flash 0x9000 0x5000 onion-os-nvs-backup.bin
```

That backup is badge-specific because the wallet seed is wrapped with a key
derived from the badge's ATECC608B HMAC slot. Restoring it to another badge will
not make the wallet usable.

## Lua Scripts

The firmware downloads a JSON script manifest, stores scripts in SPIFFS, and can
execute Lua scripts through Espressif's `espressif/lua` ESP-IDF component.
The server can also push a registry script over MQTT on
`oniondao/badge/{onionId}/lua/request`; the badge shows an install approval
popup, stores approved code in SPIFFS, runs it, and responds on
`oniondao/badge/{onionId}/lua/response` plus the HTTP fallback
`POST /api/badge/lua-response`.

Installed scripts are stored as `/scripts_*.lua` and may be up to `192` KB;
they are loaded through a PSRAM buffer so large scripts do not depend on
contiguous internal heap. Downloaded image assets are
stored as `/images_*.pbm` or `/images_*.bmp`. The badge's home menu opens a
script explorer that lists both manifest-downloaded scripts and server-pushed
scripts from SPIFFS. In the script explorer, selecting `Update Scripts`
downloads the configured manifest; selecting a script runs it, `LEFT` deletes
the highlighted script from the badge, and `CANCEL` returns home.
Lua scripts and pushed Lua bundles may be up to 256 KB each. This is a firmware
guardrail for RAM during MQTT JSON parsing and Lua loading; total stored scripts
and assets are still limited by the 1.5 MB SPIFFS partition.

The handshake routes currently only return `onionId` and `status`. After a badge
is linked, the firmware refreshes its owner profile by Onion ID with
`GET /api/badge/profile/{onionId}` and falls back to the cached `username` with
`GET /api/public/profile/{username}` for `currentOnionPoints` or
`currentOnionTokens`. If the server has `BADGE_API_KEY` configured, provision the
same key on the badge with the serial command `api-key <badge_api_key>`.

Scripts receive a small global `onion` table:

- `onion.log(message)` writes to serial and the e-paper status line.
- `onion.hardware_id()` returns the badge hardware ID.
- `onion.onion_id()` returns the current Onion ID, or `0` before handshake.
- `onion.wallet()` returns the configured Solana public key, if any.
- `onion.username()` returns the linked profile username, or `""` before the
  badge is linked.
- `onion.secure_random(count)` returns `count` random bytes (binary string)
  from the ATECC608A hardware RNG. `count` is optional and defaults to `32`
  (max `256`). Returns `nil` plus an error string if the secure element is
  unavailable.
- `onion.sha256(data)` returns the 32-byte binary SHA-256 digest of `data`
  (binary-safe input).
- `onion.kv_set(key, value)` stores a binary-safe value (1-`240` bytes) in a
  script-shared NVS namespace separate from the protected badge config. Keys
  are 1-`15` chars. Passing `nil` as the value deletes the key. Returns `true`,
  or `nil` plus an error string.
- `onion.kv_get(key)` returns the stored value, or `nil` when missing.
- `onion.kv_del(key)` deletes the key and returns `true`, or `nil` plus an
  error string.
- `onion.display_size()` returns `{ width = 264, height = 176 }` for the badge
  e-paper panel in landscape orientation.
- `onion.clear_display()` clears the e-paper display with a full ghost-clearing
  refresh and leaves Lua in control of the screen until the next button press.
- `onion.release_display()` returns screen ownership to Onion OS after a Lua
  script has drawn to the display.
- `onion.display_text(text, x, y, clear_or_options, font)` draws one text line.
  `x` defaults to `6`, `y` defaults to `22`, and clear defaults to true.
- `onion.display_lines(lines, x, y, line_height, clear_or_options)` draws a
  Lua table or newline-delimited string in one e-paper refresh.
- `onion.display_line(x0, y0, x1, y1, clear_or_options)` draws a black or white
  line. Clear defaults to false.
- `onion.display_rect(x, y, w, h, clear_or_options)` draws a rectangle. Pass
  `{ fill = true }` to fill it. Clear defaults to false.
- `onion.display_bitmap(name, x, y, clear)` draws a downloaded PBM or BMP image
  asset. Pass `-1` for `x` or `y` to center that axis. `clear` defaults to true.
- `onion.display_buffer()` returns the current Lua canvas as a raw binary string
  (5808 bytes, 264×176 1-bpp bitmap, MSB first, bit=1=black). Use this to capture
  and upload the badge display state to a server after drawing with the display API.
- `onion.display_begin()` starts a deferred-flush frame. All subsequent
  `display_*` calls draw into the canvas but do **not** push to the e-paper panel.
- `onion.display_commit()` ends the deferred frame and pushes exactly one refresh
  (partial or full) to the panel. Use `display_begin` / `display_commit` to batch
  a whole screen into a single refresh, avoiding the per-call flash.
- `onion.display_flush()` pushes the current canvas without ending the deferred
  frame — useful for animation loops that keep redrawing the same open frame.
- `onion.display_circle(cx, cy, r, options)` draws or fills a circle. Options:
  `fill` (bool), `color` (`"black"`/`"white"`), `clear` (bool, default false).
- `onion.display_triangle(x0, y0, x1, y1, x2, y2, options)` draws or fills a
  triangle. Same options as `display_circle`.
- `onion.display_round_rect(x, y, w, h, r, options)` draws or fills a
  rounded rectangle with corner radius `r`. Same options.
- `onion.display_pixel(x, y, options)` sets a single pixel. Same options.
- `onion.kv_set(key, value)` stores a string value in persistent NVS (survives
  reboots and firmware updates). `key` must be ≤15 chars; `value` ≤1024 bytes.
  Returns `true`, or `nil` plus an error string.
- `onion.kv_get(key [, default])` retrieves a previously stored value. Returns
  the stored string, or `default` (or `nil`) if the key does not exist.
- `onion.kv_delete(key)` removes a key from persistent storage.
- `onion.kv_list()` returns a table of stored keys (debug helper).
- `onion.millis()` returns the badge uptime in milliseconds (wraps at ~49 days).
  Use this for reliable in-session timing without needing SNTP.
- `onion.time()` returns the current UNIX epoch in seconds (requires SNTP sync
  after WiFi connect). Returns `0` when the clock is not yet synced.
- `onion.time_synced()` returns `true` once SNTP has completed its first sync.
- `onion.images()` returns a table of downloaded PBM and BMP image asset names.
- `onion.buttons()` returns a table with the current badge button state:
  `left`, `down`, `up`, `right`, `select`, `cancel`, and integer `mask`.
- `onion.button_mask(name)` returns the integer mask for a badge button name.
- `onion.sleep(ms)` pauses the Lua script for up to 60 seconds.
- `onion.gpio_read(pin, mode)` reads an expansion GPIO and returns `0` or `1`.
- `onion.gpio_poll(pin, target, timeout_ms, interval_ms, mode)` polls an
  expansion GPIO until it equals `target`, returning `matched, value,
  elapsed_ms`.
- `onion.espnow_start(channel)` enables ESP-NOW. `channel` is optional; with
  WiFi connected, ESP-NOW uses the current AP channel.
- `onion.espnow_stop()` deinitializes ESP-NOW and clears queued packets.
- `onion.espnow_mac()` returns the badge WiFi station MAC address.
- `onion.espnow_info()` returns `{ started, mac, channel, sent, received,
  queued }`.
- `onion.espnow_send(payload, mac)` sends a 1-240 byte payload. `mac` is
  optional and defaults to broadcast (`ff:ff:ff:ff:ff:ff`).
- `onion.espnow_receive(timeout_ms)` returns a packet table or `nil` on
  timeout. Packet fields are `mac`, `payload`, `message`, `len`, `rssi`, and
  `received_at`. Up to `128` inbound packets are queued (oldest dropped on
  overflow), enough for a peer to keep streaming while this badge sits in an
  e-paper refresh.
- `onion.espnow_set_peer_key(mac, key)` enables radio-level AES-128 (LMK) for
  one unicast peer; `key` must be exactly `16` bytes, and `nil` reverts the
  peer to plaintext. Both sides must set the same key or unicast frames are
  silently dropped — confirm the encrypted path still answers and fall back if
  it goes quiet. Broadcast always stays plaintext. The firmware sets a fixed,
  public PMK so per-peer LMKs interoperate across badges; confidentiality
  rests entirely on the 16-byte LMK your script exchanges. Returns `true`, or
  `false` plus an error string.
- `onion.wifi_disconnect()` drops the AP association without turning the radio
  off (ESP-NOW keeps working) and switches the PHY to 802.11 LR for roughly
  2-4x badge-to-badge range. Use it before `espnow_start(channel)` to pin
  badges that roamed to different APs onto one agreed channel. Internet, MQTT,
  and script sync are unavailable until reconnect.
- `onion.wifi_reconnect()` restores the normal PHY and reconnects to the
  stored AP. The firmware also restores the PHY automatically on its own next
  connection attempt after the script exits.

### Room Check-ins

Onion OS listens for trusted room beacons while WiFi is connected. Beacons use
ESP-NOW on the room AP's channel and broadcast a compact `ONCHK1` advertisement
containing beacon ID, room, label, RSSI threshold, and nonce. When the received
RSSI is strong enough, the badge shows a native `CHECK IN?` prompt.

If the user presses SELECT, the badge sends an ESP-NOW approval packet back to
the beacon with hardware ID, Onion ID, username, wallet public key, RSSI, badge
MAC, and the advertisement nonce. The beacon relays that payload to
`POST /api/badge/checkin`; the server decides whether a workshop is active in
that room and awards attendance points idempotently. The beacon can send a
result packet back so the badge displays whether points were awarded.

Packet layout is shared with `software/mods/checkin-beacon`:

```c
magic = "ONCHK1", version = 1
type 1 advertise: header, beaconId[32], room[32], label[48], minRssi, nonce[8], sequence
type 2 approve:   header, beaconId[32], nonce[8], hardwareId[65], onionId,
                  username[32], wallet[48], rssi, approvedAt, badgeMac[6]
type 3 result:    header, beaconId[32], nonce[8], awarded, points, message[80]
```
- `onion.http_get(url, options)` performs an HTTPS GET (server certificates are
  verified against the bundled root CAs) and returns `{ status, body }`, or
  `nil` plus an error string. `options` is optional and may contain `headers`
  (a table of header name → value), `content_type`, and `timeout_ms` (default
  `10000`, max `30000`).
- `onion.http_post(url, body, options)` performs an HTTPS POST. `body` is the
  request body (defaults to `application/json`; override with
  `options.content_type`). Same return shape and `options` as `http_get`.
- `onion.mqtt_connected()` returns `true` when the badge's MQTT bridge is
  connected.
- `onion.mqtt_subscribe(topic, qos)` subscribes to a topic (with `+`/`#`
  wildcards) so matching messages are delivered to `mqtt_receive()`. `qos` is
  optional (default `1`). Returns `true`, or `nil` plus an error string.
  Subscriptions are cleared when the script finishes.
- `onion.mqtt_unsubscribe(topic)` removes a subscription.
- `onion.mqtt_publish(topic, payload, qos, retain)` publishes a message. `qos`
  (default `1`) and `retain` (default `false`) are optional. Returns `true`, or
  `nil` plus an error string.
- `onion.mqtt_receive(timeout_ms)` returns the next queued message table
  (`topic`, `payload`, `message`, `len`, `received_at`) or `nil` on timeout
  (max wait `30000` ms). Only messages matching an active `mqtt_subscribe()`
  filter are queued.
- `onion.mqtt_info()` returns `{ connected, uri, prefix, subscriptions,
  queued }`.

### Swappable modules (CC1101 Sub-GHz, Sound)

The badge has two side-port module slots (see
[`docs/MODULES.md`](../../../docs/MODULES.md)). The **CC1101 Sub-GHz radio** and
the **Sound module** (NS4168 amplifier + SPH0641 PDM mic) land on the same five
physical pins, so **only one may be active at a time** — call the matching
`*_end()` before starting another. Both modules are power-gated on `GPIO18`,
which `begin()` drives HIGH and `end()` releases.

The pins differ per board variant (**L1**, **L2**, **R** — they differ only in
which side port the module attaches to). Set the variant once over serial with
`module <L1|L2|R>` (stored in NVS, default `L1`); every `begin()` uses it as the
default. Individual pins can still be overridden in the `begin()` options table.

CC1101 Sub-GHz:

- `onion.subghz_begin(options)` powers and initialises the radio, returning
  `true` or `nil` plus an error string (it also fails detection if no CC1101 is
  present). `options` may set `freq` (MHz, default `433.92`), `modulation`
  (`"gfsk"` default, `"ook"`/`"ask"`, `"2fsk"`, `"msk"`), and pin overrides
  `sck`, `miso`, `mosi`, `cs`, `gdo0`, `power_pin`.
- `onion.subghz_transmit(payload)` sends a 1–61 byte packet. Returns `true` or
  `nil` plus an error string.
- `onion.subghz_receive(timeout_ms)` returns a packet table (`payload`,
  `message`, `len`, `rssi`, `rssi_dbm`) or `nil` on timeout (max `30000` ms).
- `onion.subghz_set_frequency(mhz)` retunes the radio while running.
- `onion.subghz_info()` returns `{ variant, active }`, plus `frequency`,
  `version`, and `partnum` when the radio is running.
- `onion.subghz_end()` powers the radio down.

Sound — speaker (NS4168) and mic (SPH0641) are also mutually exclusive:

- `onion.sound_speaker_begin(options)` starts I2S output. `options` may set
  `sample_rate` (default `44100`) and pin overrides `bclk`, `ws`, `dout`,
  `ctrl`, `power_pin`. The amp gets a ~`100` ms unmute soft-start and ~`31` ms
  of silence priming so the first real samples are not clipped.
- `onion.sound_play_tone(freq_hz, duration_ms, volume)` plays a sine tone.
  `duration_ms` defaults to `200` (max `10000`); `volume` is `0.0`–`1.0`
  (default `0.6`).
- `onion.sound_play(pcm)` plays raw signed 16-bit little-endian mono PCM (capped
  at 64 KB per call), blocking until written, and returns the number of bytes
  written.
- `onion.sound_speaker_end()` drains the pipeline (~`125` ms of silence so the
  tail plays out) and stops the amplifier.
- `onion.sound_mic_begin(options)` starts PDM capture. `options` may set
  `sample_rate` (default `16000`), `dma_desc`/`dma_frame` (max `64`/`2046`) to
  deepen the capture buffer (driver default is ~90 ms; streaming scripts that
  decode or encode between reads want e.g. `dma_desc = 16, dma_frame = 512` ≈
  512 ms at 16 kHz), `discard_ms` (default `0`, max `1000`) to drop the mic's
  startup transient, and pin overrides `clk`, `din`, `ws`, `ctrl`, `power_pin`.
- `onion.sound_mic_read(num_samples, timeout_ms)` returns up to `num_samples`
  (max `4096`) of raw signed 16-bit PCM as a binary string, plus a stats table
  (`samples`, `bytes`, `sample_rate`, `timeout`, `total_samples`,
  `total_bytes`, `timeouts`, `elapsed_ms`). `timeout_ms` is optional (default
  `1000`, max `5000`); a timed-out read still returns whatever arrived, with
  `timeout = true`.
- `onion.sound_mic_level(duration_ms)` samples for `duration_ms` (max `1000`)
  and returns `{ rms, peak, samples }` — handy for sound-activated scripts.
- `onion.sound_mic_end()` stops the microphone and returns `true` plus a
  totals table (`samples`, `bytes`, `duration_ms`, `timeouts`, `sample_rate`);
  the table is omitted if the mic was not running.

Modules left running are powered down automatically when the script finishes.

HTTP and MQTT both require WiFi; `http_get`/`http_post` connect automatically,
and the MQTT functions use the badge's shared MQTT bridge. Topics passed to the
`mqtt_*` functions are absolute — they are not prefixed with the badge topic
prefix. Queued MQTT payloads are capped at 512 bytes and topics at 128 bytes.

Display option tables support `clear`, `font`, `color`, and `background`.
Fonts are `"small"`, `"bold"`, and `"large"`. Colors are `"black"` and
`"white"`.

Lua draws go through the shared partial-refresh framebuffer: small changes (a
menu cursor) use a fast partial refresh of the dirty region, while the first
draw, large changes (>`75`% of the panel), and every 30th partial use a full
~`1.7` s ghost-clearing refresh. The panel is powered off after every partial
so the e-ink booster cannot glitch the Sound module's mic/speaker path.
`clear_display()` always does a full refresh.

GPIO `mode` is optional and may be `"input"`, `"floating"`, `"pullup"`, `"up"`,
`"pulldown"`, or `"down"`. Lua scripts can read the side-port GPIOs only:
`48, 47, 19, 42, 41, 40, 38, 39, 16, 15, 7, 6, 5, 4`.

ESP-NOW and the Onion OS WiFi/MQTT bridge share the ESP32-S3 station radio. If
the badge is already connected to WiFi, pass no channel to `espnow_start()` and
run nearby badges on the same AP channel. If WiFi is not connected, scripts may
pass a channel from `1` to `14`.

Expected manifest shape:

```json
{
  "scripts": [
    {
      "name": "hello.lua",
      "url": "https://example.com/hello.lua",
      "autorun": false
    }
  ],
  "images": [
    {
      "name": "poster.pbm",
      "url": "https://example.com/poster.pbm"
    },
    {
      "name": "sponsor.bmp",
      "url": "https://example.com/sponsor.bmp"
    }
  ]
}
```

Image assets should be sized for the 264x176 black-and-white e-paper panel.
PBM files may be binary `P4` or ascii `P1`; BMP files must be uncompressed
1/4/8/24/32-bit BMPs. Images larger than 192 KB or larger than the panel are
rejected.

Example Lua image script:

```lua
local ok, err = onion.display_bitmap("poster.pbm", -1, -1)
if not ok then onion.log(err) end
```

Example Lua e-paper script:

```lua
onion.display_lines({
  "Onion SDK",
  "E-paper ready",
  onion.espnow_mac()
}, 8, 28, 22, { font = "bold", clear = true })
onion.display_rect(4, 8, 256, 160, { clear = false })
```

Example Lua ESP-NOW script:

```lua
local ok, err = onion.espnow_start()
if not ok then
  onion.log(err)
  return
end

onion.espnow_send("hello from " .. onion.hardware_id())
local msg = onion.espnow_receive(5000)
if msg then
  onion.display_lines({
    "ESP-NOW RX",
    msg.mac,
    msg.message
  }, 8, 28, 20, true)
end
```

Local example scripts live in [`scripts/`](scripts/). `image-browser.lua`
enumerates downloaded PBM/BMP assets and lets the user move through them with
the badge buttons.

The inspected server currently does not expose a script manifest route, so set
the manifest URL explicitly.

## Configure

Optional compile-time defaults:

```sh
cp main/onion_config.h.example main/onion_config.h
```

Runtime serial commands are persisted in NVS:

```text
api-key <badge_api_key>
mqtt-auth [username] [password] [prefix]
scripts-url <manifest_url>
module <L1|L2|R>
wallet
keygen confirm
handshake
scripts
run <script_name.lua>
delete <script_name.lua>
state
help
```

Examples:

```text
api-key badge-api-secret
mqtt-auth badge badge-password oniondao
wallet
handshake
```

`keygen confirm` deletes any unlinked local wallet and creates a new wrapped key.
It refuses to rotate after the badge is linked, because the server may already
have migrated points to the previous Solana address.

## Build

From this directory:

```sh
idf.py set-target esp32s3
idf.py build
idf.py flash monitor
```

Or use the helper script to auto-detect the first attached ESP32-S3 badge:

```sh
scripts/build-flash.sh
scripts/build-flash.sh --monitor
```

Pass `--port /dev/cu.usbserial-10` if you want to flash a specific port.
The helper script refuses full flash erase so NVS-backed badge state is not
deleted accidentally.
Set `IDF_EXPORT=/path/to/esp-idf/export.sh` if your ESP-IDF install is not in a
common location.

To monitor logs without flashing, use the serial monitor helper. It scans common
USB serial ports, labels detected ESP board types, prompts for a device, and
then runs `idf.py monitor`:

```sh
scripts/monitor-serial.sh
scripts/monitor-serial.sh --port /dev/cu.usbserial-210
scripts/monitor-serial.sh --board any --list
```

The project uses the same 8 MB flash / OPI PSRAM defaults as the existing badge
mods.

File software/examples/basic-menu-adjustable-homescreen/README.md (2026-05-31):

# Basic Menu with Adjustable Homescreen

Ready-to-flash firmware for the OnionDAO badge. Flash it once and you get a navigable menu and a homescreen you can update from your computer anytime.

Built with [Claude Code](https://claude.ai/code). Use this as your base layer, then customize with your chosen AI.

---

> **Buttons will not respond on fresh hardware.** The badge ships without firmware — nothing happens when you press buttons until you complete Step 3.

---

## What You Need

- OnionDAO badge + USB-C cable
- LiPo battery *(optional — the badge runs on USB power alone)*
- **ESP-IDF v5.5.x** for building & flashing — see the
  [VS Code + ESP-IDF setup guide](../../guides/esp-idf-vscode-setup.md)
  (⚠️ use v5.5.x, *not* 6.0+)
- Python 3 + pip for the art tool

---

## Step 1 — Download

```bash
git clone https://github.com/OnionDAO-git/oniondao-badge.git
cd oniondao-badge/software/examples/basic-menu-adjustable-homescreen
```

No git? Download the ZIP from the repo page and extract it.

---

## Step 2 — Connect the Battery (optional)

Flip the board over. The LiPo connector is labeled **BAT / J2**.

- Plug the battery in for portable use — the badge also runs fine from USB alone
- Always unplug the battery before any soldering or rework
- Flip the **ON/OFF** slide switch on the back to power on

---

## Step 3 — Flash the Firmware

> First time? Install the toolchain via the
> [VS Code + ESP-IDF setup guide](../../guides/esp-idf-vscode-setup.md) — then
> you can just hit **Build, Flash and Monitor** (🔥) in VS Code instead of the
> commands below.

Connect the badge via USB-C, then, in an ESP-IDF terminal (VS Code
"ESP-IDF Terminal", or after `. $IDF_PATH/export.sh`):

```bash
cd firmware
idf.py build
idf.py -p /dev/tty.usbserial-10 flash monitor   # use your serial port
```

The S3 target, 8 MB flash and partition table are preconfigured in
`firmware/sdkconfig.defaults` — no `idf.py set-target` needed. The Arduino core
is fetched automatically on first build.

If the upload fails to connect:
1. Hold **BOOT** (back of board)
2. Press and release **RST**
3. Release **BOOT**
4. Run the upload command again

After a successful flash the screen flashes white and shows the home screen. **Buttons are now active.**

---

## Step 4 — Navigate the Menu

Press any button from the home screen to open the menu.

| Button | Action |
|---|---|
| UP / DOWN | Move the cursor |
| SELECT | Open the selected item |
| CANCEL | Go back |
| LEFT / RIGHT | Flip pages (inside guide screens) |

| # | Screen | What it shows |
|---|---|---|
| 1 | System Info | Chip model, clock speed, memory |
| 2 | Button Test | Watch button presses light up in real time |
| 3 | I2C Scanner | Every chip found on the internal bus |
| 4 | RNG / Crypto | 16 random bytes from the hardware crypto chip |
| 5 | Display Test | Four screen patterns to confirm the display works |
| 6 | Hardware Guide | 10 short lessons on the physical components |
| 7 | Software Guide | 10 short lessons on the C++ firmware |
| 8 | ESPNow Beacon | Send and receive badge-to-badge wireless messages |

After 60 seconds of no activity the badge sleeps automatically. The image stays on screen with no power — press any button to wake it.

---

## Step 5 — Set a Custom Homescreen

**Install dependencies (one time):**
```bash
pip install pillow pyserial
```

**Run the art tool:**
```bash
python3 badge-art/badge_art.py
```

- Draw with left-click, erase with right-click
- Import any photo or PNG with **Open Image** — auto-resized and converted
- Select the serial port and click **Send to Badge**

The image saves to internal flash and persists through sleep and power cycles.

> The badge must be awake to receive an image. If it slept, press any button first, then send within 60 seconds.

---

## ESPNow — Badge-to-Badge Wireless

Menu item 8 turns on ESPNow, Espressif's direct 2.4 GHz peer-to-peer protocol. No Wi-Fi router or access point required — badges talk directly to each other.

| Button | Action |
|---|---|
| SELECT | Broadcast a beacon (your MAC + a counter) to all nearby badges |
| CANCEL | Return to the menu |

The screen shows your own MAC address, how many beacons you have sent, and the name, MAC, and counter of the last badge that reached you. ESPNow only starts up when you enter this screen — it has no effect on boot time or battery when you are not using it.

Flash the same firmware to two badges and navigate both to **8. ESPNow Beacon** to see them communicate.

---

## Go Further

Drop `firmware/main/main.cpp` into your AI of choice and ask it to add new screens or menu items. This version was built using **[Claude Code](https://claude.ai/code)**.

| File | Purpose |
|---|---|
| `firmware/main/main.cpp` | All firmware — menus, buttons, image receiver |
| `firmware/main/badge_pins.h` | Every GPIO pin number in one place |
| `firmware/CMakeLists.txt` + `sdkconfig.defaults` | ESP-IDF build config (target, flash, PSRAM, partitions) |
| `firmware/main/idf_component.yml` | Arduino core + library dependencies |
| `badge-art/badge_art.py` | Art tool — draw, import, and send images |
| `docs/project.md` | Full firmware reference and extension patterns |
| `docs/guide.md` | Hardware and C++ concepts for beginners |
| `docs/hardware-reference.md` | Pinouts, connectors, soldering notes |

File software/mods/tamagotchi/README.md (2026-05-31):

# Tamagotchi

A virtual pet for the OnionDAO Badge. Keep your creature alive through five
evolution stages by feeding, playing, sleeping, and giving medicine.

**Module variant required:** None — base badge only (e-paper display + TCA9534
button expander). The ATECC608B and CC1101 are not used.

## Gameplay

| Stage  | Age (real time) | Notes |
|---|---|---|
| EGG | 0 – 1.5 h | Incubating; no interaction yet |
| BABY | 1.5 – 24 h | Basic needs |
| CHILD  | 1 – 3 days | Arms appear |
| TEEN | 3 – 7 days | Legs and more expression |
| ADULT  | 7 days+ | Confident stance, star eyes when happy |

**Stats** (all 0–10, shown as fill bars):

| Bar | Decays when … | Consequence of zero |
|-----|---|---|
| HUN (hunger) | Awake, every 30 min | Health −2 / tick |
| HAP (happiness) | Always, every 30 min | Health −1 / tick |
| NRG (energy) | Awake, every 30 min | — (pet just looks tired) |
| HLT (health) | Starvation / sadness / 5 % random sickness | Death at 0 |

**Actions** (navigate with LEFT / RIGHT or UP / DOWN, confirm with SELECT):

- **FEED** — hunger +4, happiness +1
- **PLAY** — happiness +4, hunger −1, energy −2
- **SLEEP** — starts sleep mode; badge deep-sleeps and restores energy over time (NRG +3 / 30 min). Press any button to wake early.
- **MED** — health +4, happiness −1

## Power / time model

The badge deep-sleeps between interactions. A 30-minute hardware timer
wakes it silently to tick stats, then it goes back to sleep — no display
refresh, minimal power draw. Button press wakes it for interaction.

If the pet dies, press SELECT to hatch a new egg.

## Build & flash

Built with **ESP-IDF v5.5.x** (using the Arduino core as a managed component).
**New to ESP-IDF?** Follow the
[VS Code + ESP-IDF setup guide](../../guides/esp-idf-vscode-setup.md) first to
install the toolchain. Then run these in an ESP-IDF terminal (VS Code
"ESP-IDF Terminal", or after `. $IDF_PATH/export.sh`):

```bash
cd software/mods/tamagotchi
idf.py build
idf.py -p /dev/tty.usbserial-10 flash monitor   # use your serial port
```

The S3 target, 8 MB flash, octal PSRAM and partition table are preconfigured in
`sdkconfig.defaults` + `partitions.csv` — no `idf.py set-target` needed. The
Arduino core (`arduino-esp32` 3.3.8) is fetched automatically on first build;
GxEPD2 / Adafruit GFX / BusIO live in `../../components/`.

Requires: ESP-IDF v5.5.x with the `esp32s3` toolchain installed.

## GPIOs used

| Signal | GPIO | Role |
|---|---|---|
| PWR | 18 | Peripheral power rail — held HIGH during setup, released on sleep |
| SCL | 9 | I²C clock (TCA9534 button expander @ 0x20) |
| SDA | 10 | I²C data |
| EPD_MOSI | 17 | E-paper SPI data |
| EPD_SCK | 11 | E-paper SPI clock |
| EPD_CS | 12 | E-paper chip select (active LOW) |
| EPD_DC | 13 | E-paper data/command |
| EPD_RST | 14 | E-paper reset (active LOW) |
| EPD_BUSY | 21 | E-paper busy flag |
| BTN_IRQ | 1 | Button interrupt (EXT0 wakeup source) |

Full reference: [`docs/PINOUT.md`](../../../../docs/PINOUT.md).

## Demo

The e-paper display shows an onion-shaped creature (onion bulb head with
sprouts) that evolves visually across five life stages. When actions are
confirmed the creature performs a 2-frame dancing animation using the SSD1680
partial-refresh window (~500 ms per frame, no full-panel flicker). Press the
CANCEL button at any time to advance the stage instantly for testing.

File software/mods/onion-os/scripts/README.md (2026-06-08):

# Onion OS Scripts

## Build and Flash Helper

`build-flash.sh` builds Onion OS and flashes the first attached ESP32-S3 board
it can find:

```sh
scripts/build-flash.sh
```

Run it from the Onion OS project directory. Use `--monitor` to open the serial
monitor after flashing, or `--port /dev/cu.usbserial-10` to choose a specific
serial port.

The helper auto-loads common ESP-IDF installs, including
`~/.espressif/v5.5.4/esp-idf/export.sh`. Set
`IDF_EXPORT=/path/to/esp-idf/export.sh` if your ESP-IDF install lives somewhere
else.

## Serial Monitor Helper

`monitor-serial.sh` searches common serial ports, detects ESP board types, lets
you select the matching device, and opens `idf.py monitor`:

```sh
scripts/monitor-serial.sh
```

It defaults to ESP32-S3 badges and 115200 baud. Use `--board any` to show every
connected serial port, `--list` to print detected ports without opening the
monitor, or `--port /dev/cu.usbserial-210` to skip selection. Press `Ctrl-C` to
stop the monitor and close any child monitor process.

## Lua Scripts

Example Lua scripts in this directory are meant to be copied into the Onion OS
script registry or served through the script manifest.

## E-paper Demo

`eink-demo.lua` exercises the Onion SDK e-paper helpers by drawing text, a
border, and a separator line.

## ESP-NOW Beacon

`espnow-beacon.lua` enables ESP-NOW, broadcasts a short badge identity packet,
and displays the first received packet if another badge replies.

## Check-In Range

`checkin-range.lua` listens for Onion check-in beacon advertise packets and
shows whether the current badge RSSI meets the beacon's advertised threshold.
This is useful for testing a tight beacon threshold, such as `-50 dBm`, before
using the normal check-in prompt. Press `CANCEL` to exit back to Onion OS.

## Tamagonion

`tamagonion.lua` is a Tamagotchi-style virtual pet that runs entirely as a Lua
script. The onion creature is drawn natively using `display_begin/commit` and the
vector drawing primitives (`display_circle`, `display_triangle`,
`display_round_rect`, `display_pixel`) — no sprite assets required.

The pet grows through five life stages (EGG → BABY → CHILD → TEEN → ADULT),
has hunger/happiness/energy/health stats that decay over time, can be fed, played
with, put to sleep, and medicated, and can get sick or die. State is saved to NVS
(survives reboots) via `onion.kv_set/kv_get`. Timing uses `onion.millis()` so
decay runs at a real rate regardless of SNTP availability.

Controls:

- `LEFT` / `RIGHT` (or `UP` / `DOWN`): cycle FEED / PLAY / SLEEP / MED action
- `SELECT`: perform the selected action
- `CANCEL`: save and return to Onion OS

On firmware without the vector-primitive additions, `tamagonion.lua` falls back
to a text-only ASCII-bar mode so the game logic still runs.

**Requires:** Path B firmware (`display_begin`, `display_commit`, `display_circle`,
`display_triangle`, `display_round_rect`, `display_pixel`, `kv_set`, `kv_get`,
`millis`). All additions are in `main/main.cpp` and documented in
`docs/03-api-improvement.md`.

## Image Browser

`image-browser.lua` browses every downloaded image stored in SPIFFS as
`/images_*.pbm` or `/images_*.bmp`.

Controls:

- `UP` / `LEFT`: previous image
- `DOWN` / `RIGHT`: next image
- `SELECT`: redraw current image
- `CANCEL`: return to Onion OS

To install it through a manifest, serve this script and the image assets:

```json
{
  "scripts": [
    {
      "name": "eink-demo.lua",
      "url": "https://example.com/eink-demo.lua"
    },
    {
      "name": "espnow-beacon.lua",
      "url": "https://example.com/espnow-beacon.lua"
    },
    {
      "name": "checkin-range.lua",
      "url": "https://example.com/checkin-range.lua"
    },
    {
      "name": "image-browser.lua",
      "url": "https://example.com/image-browser.lua"
    }
  ],
  "images": [
    {
      "name": "poster.pbm",
      "url": "https://example.com/poster.pbm"
    }
  ]
}
```

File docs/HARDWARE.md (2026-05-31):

# Hardware Overview

Deep dive on every subsystem on the OnionDAO Badge. Pair this with
[`PINOUT.md`](PINOUT.md) (where every GPIO lives) and
[`MODULES.md`](MODULES.md) (what the swappable RF / audio modules do).

---

## 1. Main MCU — ESP32-S3-WROOM-1-N8R8

- Espressif ESP32-S3 dual-core Xtensa LX7 @ up to 240 MHz
- 2.4 GHz Wi-Fi b/g/n + Bluetooth LE 5.0
- Native USB OTG (not exposed — USB-C goes through CH340C)
- Module integrates the PCB antenna, flash, and PSRAM
- **Memory:** `N8` = 8 MB quad-SPI flash, `R8` = 8 MB **Octal-SPI (OPI)** PSRAM

> **Firmware note:** the `R8` PSRAM is Octal, not quad. It stays disabled
> unless you select Octal mode explicitly — ESP-IDF `SPI RAM → Mode = Octal`
> (flash size 8 MB); Arduino-ESP32 `PSRAM = OPI PSRAM`; PlatformIO
> `board_build.arduino.memory_type = qio_opi` + `-DBOARD_HAS_PSRAM`. The
> KiCad schematic symbol value is the generic `ESP32-S3-WROOM-1`; the actual
> board is built with the N8R8 variant.

### Strapping pins to be careful with

| GPIO | Function | Notes |
|---|---|---|
| `GPIO0`  | BOOT mode select | LOW at power-on → download mode. Wired to the BOOT button + auto-reset transistor pair. |
| `GPIO3`  | JTAG signal source | not used on this board |
| `GPIO45` | VDD_SPI voltage | factory-set, do not drive |
| `GPIO46` | Boot ROM messages | factory-set, do not drive |

If you write firmware that reconfigures `GPIO0` as an output, **release it
to input before the next reset** or you'll brick the auto-flash workflow
until someone holds BOOT manually.

## 2. USB & Programming

The USB-C jack feeds a **WCH CH340C** USB ↔ UART bridge:

- `CH340C.RXD` ← `GPIO43` (`TX0`) via series resistor R1 = 220 Ω
- `CH340C.TXD` → `GPIO44` (`RX0`)
- `DTR` / `RTS` drive transistors **Q1** and **Q2** to toggle `EN` and
  `GPIO0` — this is the classic NodeMCU auto-reset circuit. esptool and
  Arduino-IDE handle this transparently.

If the host doesn't toggle DTR/RTS the way the chip expects (some USB
hubs, some serial monitors), the manual recipe is:

1. Hold **BOOT** (`GPIO0`)
2. Tap **RESET**
3. Release **BOOT**
4. Flash

## 3. Power

The board has two rails:

- **VCC** — always-on rail powering the ESP32 module and the CH340C.
- **PWR** — switched rail for peripherals (display, RF mod, audio mod,
  etc.) gated by **Q5 (SS8050)** driven through R22 = 1 kΩ from `GPIO18`.

`GPIO18` HIGH = peripherals on. Drop it LOW to deep-sleep-friendly states.
Always assert `GPIO18` HIGH **before** talking to power-gated peripherals,
and wait long enough for them to come up (most chips: a few milliseconds
plus their own POR delay).

## 4. I²C Bus

Single shared I²C bus at `GPIO9` (SCL) / `GPIO10` (SDA). External pull-ups
are on the board. Maximum advertised speed: **400 kHz** (Fast Mode).

Devices on the bus:

| Address | Chip | Purpose |
|---|---|---|
| `0x20`  | **TCA9534** | 8-bit IO expander — drives PB1..PB6 user buttons and exposes `INT` on `GPIO1` (`PBINT`). |
| (factory) | **ATECC608B-SSHDA** | Hardware secure element — ECC signing / key storage. Power-gated via `SE_EN` on `GPIO8`. The ATECC608B's I²C address is set in its config zone; default boards ship with `0xC0` (7-bit `0x60`). |

### TCA9534 register quick-ref

| Reg | Name | Notes |
|-----|---|---|
| `0x00` | Input port | Read to see current pin states. |
| `0x01` | Output port | Write to drive outputs. |
| `0x02` | Polarity inv. | Leave at `0x00` unless inverting reads. |
| `0x03` | Configuration | `1` = input, `0` = output. Buttons are inputs. |

### Recommended I²C pattern

```
Wire.begin(SDA=10, SCL=9, 400000);
pinMode(PBINT=1, INPUT_PULLUP);
attachInterrupt(PBINT, isr, FALLING);

// in isr() — read register 0x00, decode bits, clear by reading.
```

## 5. Boot / Reset Circuit

- **BOOT button** → `GPIO0` (strapping)
- **Auto-reset** Q1/Q2 → `EN` + `GPIO0`, driven by CH340C `DTR`/`RTS`

The same `GPIO0` button is reused as a **user button** once the firmware
is running. Don't drive `GPIO0` low from firmware at startup or you'll
trap yourself in bootloader mode after the next reset.

## 6. Display Socket — J4 (24-pin)

A 24-pin **Conn_01x24** socket for E-Ink or TFT display modules. Pinout
of the GPIO side:

| GPIO | Net | J4 Pin | Function |
|---|-----|---|---|
| `GPIO14` | `RS` | 3  | Display RESET (active LOW; pulse ≥ 10 ms during init) |
| `GPIO21` | `BUSY` | 9  | Display busy — HIGH while refreshing |
| `GPIO13` | `DC` | 11 | Data / Command (HIGH = data, LOW = command) |
| `GPIO12` | `CS` | 12 | SPI Chip Select (active LOW) |
| `GPIO11` | `SCK`  | 13 | SPI Clock |
| `GPIO17` | `SDI`  | 23 | SPI MOSI — data to display |

The remaining J4 pins carry VCC, GND, and module-specific signals (GDR,
RESE for e-paper booster, etc.) — see the schematic for the connector
breakout.

> For E-Ink modules, the typical flow is: pulse `RST` low → wait `BUSY`
> goes low → send command (DC=0) → send data bytes (DC=1) → trigger
> refresh → poll `BUSY` until it returns LOW.

## 7. Button Matrix — PB1..PB6

The six tactile buttons are **not** wired directly to the ESP32. They
sit on the TCA9534 IO expander's `P0..P5` and pull a shared `INT` line
that becomes `PBINT` on `GPIO1`.

Firmware pattern:

1. Configure TCA9534 reg `0x03` (config) so `P0..P5` are inputs.
2. Read reg `0x00` (input port) once at boot to clear any stale INT.
3. `attachInterrupt(PBINT, isr, FALLING)`.
4. Inside the ISR (or a deferred task), re-read reg `0x00` and decode.

## 8. Secure Element — ATECC608B

Microchip ECC-P256 chip. Useful for:

- Per-badge unique key pairs
- Signed-message attestations (CTF flags, identity proofs)
- Hardware RNG

The chip is **power-gated** by `GPIO8` (`SE_EN`). Drive HIGH, wait
≥ 1 ms (Tpu = power-up delay), then talk to it. Pull LOW when idle to
save current.

Use Microchip's CryptoAuthLib or the lightweight Arduino libraries.

## 9. Expansion Ports — J8 (Left), J10 (Right)

Two 10-pin headers along the sides of the board. Pin 1 of each is GND,
pin 2 is VCC, then GPIOs follow. These are how external modules,
lanyards, and the swappable RF / audio mods attach.

| Pin | J8 (Left) | J10 (Right) |
|-----|---|---|
| 1 | GND | GND |
| 2 | VCC | VCC |
| 3 | `GPIO48`  | `GPIO38` |
| 4 | `GPIO47`  | `GPIO39` |
| 5 | `GPIO19`  | `GPIO16` |
| 6 | `GPIO42`  | `GPIO15` |
| 7 | `GPIO41`  | `GPIO7`  |
| 8 | `GPIO40`  | `GPIO6`  |
| 9 | VCC | `GPIO5`  |
| 10  | GND | `GPIO4`  |

The **Sound Module** and the **CC1101 Module** both target this set of
pins. See [`MODULES.md`](MODULES.md) for the mapping and the rules about
mutual exclusion.

## 10. Mechanical / 3D

- Full board STEP: [`pcb/oniondao-badge.step`](../pcb/oniondao-badge.step)
- Lanyard / additional 3D assets: [`pcb/3d/`](../pcb/3d/)

## 11. Manufacturing Outputs

Already-generated fabrication outputs are in
[`pcb/production/`](../pcb/production/):

- `oniondao-badge.zip` — gerbers + drills + P&P
- `netlist.ipc` — IPC-D-356 netlist
- `bom-list_*.xlsx` — per-variant BOMs

To re-generate: open the `.kicad_pcb` in KiCad 9.0.3 → File → Fabrication
Outputs.

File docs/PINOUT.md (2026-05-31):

# Complete Pinout Reference

This is a markdown mirror of the interactive table in
[`pcb/oniondao badge.html`](../pcb/oniondao%20badge.html). Open the HTML in a
browser for filterable / searchable views — this document is here so PR
reviewers and search tools can read the pin map without rendering HTML.

**28 GPIO used** · **2 swappable modules** (see [`MODULES.md`](MODULES.md))

Legend: **IN** = input, **OUT** = output, **I/O** = bidirectional.

---

## Core · UART · Boot

CH340C USB-UART bridge, BOOT button, peripheral power gate.

| GPIO | Net | Dir | Interface | Peripheral | Notes |
|---|-----|-----|---|---|---|
| `GPIO0`  | `IO0` | IN  | BOOT | BOOT button (SW_Push) + auto-reset Q1/Q2 | **STRAPPING**. LOW @ power-on → download mode. HIGH → normal boot. |
| `GPIO43` | `TX0` | OUT | UART0 TX | U15 CH340C RXD (pin 6) | Debug / programming TX. Series R1 = 220 Ω. |
| `GPIO44` | `RX0` | IN  | UART0 RX | U15 CH340C TXD (pin 7) | Debug / programming RX. |
| `GPIO18` | `PWR` | OUT | GPIO | Q5 SS8050 (R22 1 kΩ) → peripheral VCC | HIGH = enable PWR rail. Assert before talking to gated peripherals. |

## I²C Bus — Security Chip + IO Expander

Single shared bus. Fast Mode (400 kHz) max.

| GPIO | Net | Dir | Interface | Peripheral | Notes |
|---|-----|-----|---|---|---|
| `GPIO9`  | `SCL` | OUT | I²C SCL | U10 TCA9534 pin 14 + U16 ATECC608B pin 6 | Clock. External pull-ups on board. |
| `GPIO10` | `SDA` | I/O | I²C SDA | U10 TCA9534 pin 13 + U16 ATECC608B pin 5 | Data. TCA9534 @ `0x20`. |
| `GPIO1`  | `PBINT` | IN  | GPIO IRQ | U10 TCA9534 INT → PB1..PB6 buttons | Active LOW. `attachInterrupt(FALLING)` then read TCA9534 reg `0x00`. |
| `GPIO8`  | `SE_EN` | OUT | GPIO | U16 ATECC608B-SSHDA enable | HIGH = active. Power-gate when idle for low-power modes. |

## Display SPI — J4 Socket (24-pin)

E-Ink or TFT display socket.

| GPIO | Net | Dir | Interface | J4 Pin | Notes |
|---|-----|-----|---|---|---|
| `GPIO14` | `RS` | OUT | DISP RST  | 3  | Hardware reset. Pulse LOW ≥ 10 ms during init. |
| `GPIO13` | `DC` | OUT | DISP D/C  | 11 | HIGH = Data, LOW = Command. Toggle per transfer. |
| `GPIO12` | `CS` | OUT | DISP CS | 12 | SPI Chip Select. Active LOW. |
| `GPIO11` | `SCK`  | OUT | DISP SCK  | 13 | SPI Clock. |
| `GPIO21` | `BUSY` | IN  | DISP BUSY | 9  | HIGH while refresh in flight. Poll or interrupt. |
| `GPIO17` | `SDI`  | OUT | DISP MOSI | 23 | SPI MOSI — data to display. |

J4 also carries VCC, GND, and module-specific lines (GDR booster
enable, RESE, etc.) — see the schematic for the full 24-pin breakout.

## Sound Module — PDM / I²S

`NS4168` Class-D amplifier + `SPH0641` PDM microphone. The Sound
Module shares its pins with the CC1101 Module — only one can be
active at a time. The three columns below are the alternative GPIO
selections depending on **which side port** the module is plugged
into / configured for.

| Signal | IO L1 | IO L2 | IO R | Dir | Interface | Notes |
|---|---|---|---|-----|---|---|
| Mic data | `G48` | `G40` | `G38` | IN  | PDM | SPH0641 DATA. |
| Bit clock | `G47` | `G41` | `G39` | OUT | I²S / PDM | BCLK to NS4168 + SPH0641. |
| Word select | `G19` | `G42` | `G16` | OUT | I²S WS/LR | LRCK to NS4168 + SPH0641 SELECT. |
| Audio data out | `G42` | `G19` | `G15` | OUT | I²S SDO | I²S data to NS4168 SD pin. |
| Control | `G41` | `G47` | `G07` | OUT | I²S CTRL  | NS4168 CTRL pin (mode / shutdown). |

## CC1101 Module — Sub-GHz SPI Radio

TI CC1101 (315 / 433 / 868 / 915 MHz ISM). Shares the same GPIOs as the
Sound Module above — pick one.

| Signal | IO L1 | IO L2 | IO R | Dir | Interface | Notes |
|---|---|---|---|-----|---|---|
| SPI MOSI | `G48` | `G40` | `G38` | I/O | SPI MOSI  | Data to CC1101. |
| SPI CLK | `G47` | `G41` | `G39` | OUT | SPI CLK | SPI clock. |
| SPI CS | `G19` | `G42` | `G16` | OUT | SPI CS | Active LOW. |
| SPI MISO | `G42` | `G19` | `G15` | OUT | SPI MISO  | CC1101 SO. |
| GDO0 IRQ | `G41` | `G47` | `G07` | IN  | GPIO IRQ  | CC1101 GDO0; behaviour set via register. |

## Expansion Ports

### Left Port — J8 (10-pin)

| Pin | Net  | GPIO |
|-----|---|---|
| 1 | GND  | — |
| 2 | VCC  | — |
| 3 | `G48` | `GPIO48` |
| 4 | `G47` | `GPIO47` |
| 5 | `G19` | `GPIO19` |
| 6 | `G42` | `GPIO42` |
| 7 | `G41` | `GPIO41` |
| 8 | `G40` | `GPIO40` |
| 9 | VCC  | — |
| 10  | GND  | — |

### Right Port — J10 (10-pin)

| Pin | Net  | GPIO |
|-----|---|---|
| 1 | GND  | — |
| 2 | VCC  | — |
| 3 | `G38` | `GPIO38` |
| 4 | `G39` | `GPIO39` |
| 5 | `G16` | `GPIO16` |
| 6 | `G15` | `GPIO15` |
| 7 | `G07` | `GPIO7`  |
| 8 | `G06` | `GPIO6`  |
| 9 | `G05` | `GPIO5`  |
| 10  | `G04` | `GPIO4`  |

---

## Cross-reference: GPIO → Function

Sorted by GPIO number. `*` = module-shared pin.

| GPIO | Primary use |
|---|---|
| 0 | BOOT / strapping / user button |
| 1 | TCA9534 INT (`PBINT`) |
| 4 | J10 right port |
| 5 | J10 right port |
| 6 | J10 right port |
| 7 | J10 right port (CC1101 GDO0 / I²S CTRL — variant R)* |
| 8 | ATECC608B enable (`SE_EN`) |
| 9 | I²C SCL |
| 10 | I²C SDA |
| 11 | Display SPI SCK |
| 12 | Display SPI CS |
| 13 | Display DC |
| 14 | Display RST |
| 15 | J10 right port (CC1101 MISO / I²S SDO — variant R)* |
| 16 | J10 right port (CC1101 CS / I²S WS — variant R)* |
| 17 | Display SPI MOSI (SDI) |
| 18 | Peripheral power-gate (`PWR` / Q5) |
| 19 | J8 left port (variant L1)* |
| 21 | Display BUSY |
| 38 | J10 right port (variant R)* |
| 39 | J10 right port (variant R)* |
| 40 | J8 left port (variant L2)* |
| 41 | J8 left port* |
| 42 | J8 left port* |
| 43 | UART0 TX (CH340C) |
| 44 | UART0 RX (CH340C) |
| 47 | J8 left port* |
| 48 | J8 left port* |

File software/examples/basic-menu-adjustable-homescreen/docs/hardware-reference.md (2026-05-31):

# OnionDAO Badge — Hardware Reference

Physical pin locations, connector pinouts, and component callouts captured
from the board photos. Use this as a soldering reference before any rework.

---

## Board Layout (Front)

```
┌─────────────────────────────────────────────────────────────────┐
│  [TOP GPIO HEADER]                                              │
│  GND VCC G38 G39 G16 G15 G07 G06 G05 G04                       │
│  ○   ○   ○   ○   ○   ○   ○   ○   ○   ○                         │
│                                                                 │
│  ┌──────────────────────┐    ┌────────────────┐  ┌──────────┐  │
│  │                      │    │   [SELECT]     │  │ CTR      │  │
│  │   2.7" E-PAPER       │    │   [CANCEL]     │  │ SDO      │  │
│  │   264 × 176 px       │    │   [RIGHT]      │  │ SLR      │  │
│  │   SSD1680            │    │   [UP] [DOWN]  │  │ SCK      │  │
│  │                      │    │   [LEFT]       │  │ SDL      │  │
│  └──────────────────────┘    └────────────────┘  │ VCC      │  │
│                                                  │ GND      │  │
│  ○   ○   ○   ○   ○   ○   ○   ○   ○   ○          ├──────────┤  │
│  [MODULE CONNECTOR — speaker / sub-GHz radio]   │ GND      │  │
│  (optional add-on modules attach here)           │ VCC      │  │
│                                                  │ TDD      │  │
│                                          [ANT]   │ SCK      │  │
│                                            ○     │ SCS      │  │
│                                                  │ SDO      │  │
│                                                  │ GDO      │  │
│                                                  └──────────┘  │
└─────────────────────────────────────────────────────────────────┘
```

---

## Board Layout (Back)

```
┌─────────────────────────────────────────────────────────────────┐
│  [ON/OFF_PB1]  [ON/OFF_SW1]   [Display FPC / J4]               │
│                                                                 │
│  ┌─────────────────┐    ┌────────────────────────┐             │
│  │                 │    │  ESP32-S3-WROOM-1  (U1)│             │
│  │   LiPo Battery  │    └────────────────────────┘             │
│  │   (BAT / J2)    │                                            │
│  │                 │         [RST1]  [BOOT1]                    │
│  └─────────────────┘                                            │
│         │                                                       │
│         └── Battery connector: BAT+/BAT-                        │
│                                                                 │
│                         [USB-C  J1]  ← programming + power     │
│                                                                 │
│                           "DEVELOPED BY SKYRIZZ"               │
└─────────────────────────────────────────────────────────────────┘
```

---

## GPIO Expansion Header

A single 10-pin header runs along the top edge of the front face. It exposes
unused ESP32-S3 GPIOs and is the primary solder point for adding new
peripherals. The connector along the bottom edge is a module port, not free
GPIO — see the next section.

### Top Header (10 pins, left → right)

| Pin | Label | Notes |
|-----|---|---|
| 1 | GND | Ground |
| 2 | VCC | 3.3 V rail |
| 3 | G38 | GPIO38 |
| 4 | G39 | GPIO39 |
| 5 | G16 | GPIO16 |
| 6 | G15 | GPIO15 |
| 7 | G07 | GPIO7 |
| 8 | G06 | GPIO6 |
| 9 | G05 | GPIO5 |
| 10 | G04 | GPIO4 |

### Bottom Connector — Optional Module Port

This is **not** a free GPIO header. It is the attachment point for optional
add-on modules that stack on top of the badge:

| Module | Schematic |
|---|---|
| CC1101 sub-GHz radio (433.92 MHz) | `pcb/CC1101_MOD.kicad_sch` |
| Speaker / audio mix | `pcb/SOUND_MOD.kicad_sch` |

Pin functions depend on which module is attached — refer to the relevant
KiCad schematic for the exact pinout. Without a module attached this
connector is unpopulated.

---

## Right-Side Expansion Connectors

Two 7-pin connectors on the right edge, used for plug-in modules
(CC1101 radio, LoRa, audio, SD card — schematics in `pcb/`).

### Top Connector (7 pins)

| Pin | Label | Likely function |
|-----|---|---|
| 1 | CTR | Control / chip enable |
| 2 | SDO | SPI MISO (data out from module) |
| 3 | SLR | SPI CLK |
| 4 | SCK | SPI SCK |
| 5 | SDL | SPI MOSI (data in to module) |
| 6 | VCC | 3.3 V |
| 7 | GND | Ground |

### Bottom Connector (7 pins)

| Pin | Label | Likely function |
|-----|---|---|
| 1 | GND | Ground |
| 2 | VCC | 3.3 V |
| 3 | TDD | Debug / JTAG TDI |
| 4 | SCK | SPI SCK |
| 5 | SCS | SPI CS (chip select) |
| 6 | SDO | SPI MISO |
| 7 | GDO | GDO (CC1101 interrupt / general data out) |

---

## Button Map

Physical silkscreen labels → firmware constants → TCA9534 bit positions.

| Silkscreen | Firmware constant | TCA9534 bit | PB number |
|---|---|---|---|
| SELECT | `BTN_SELECT` | bit 4 | PB5 |
| CANCEL | `BTN_CANCEL` | bit 5 | PB6 |
| RIGHT | `BTN_RIGHT` | bit 3 | PB4 |
| UP | `BTN_UP` | bit 2 | PB3 |
| DOWN | `BTN_DOWN` | bit 1 | PB2 |
| LEFT | `BTN_LEFT` | bit 0 | PB1 |

Physical layout (front face, right side):

```
        [SELECT]
        [CANCEL]
        [RIGHT]
  [UP]        [DOWN]
        [LEFT]
```

---

## Key Components (Back of Board)

| Ref | Part | Purpose |
|-----|---|---|
| U1 | ESP32-S3-WROOM-1-N8R8 | Main MCU — 240 MHz, 8 MB flash, 8 MB PSRAM |
| U5 | TCA9534 | I²C I/O expander — reads 6 buttons @ 0x20 |
| U15 | ATECC608B | Crypto secure element @ 0x60 |
| U16 | CH340C | USB-UART bridge — connects to `/dev/ttyUSB0` |
| J1 | USB-C | Programming port + power input |
| J2 | BAT | LiPo battery connector |
| J4 | FPC | E-paper display flat flex connector |
| RST1 | Tactile switch | Hard reset the ESP32 |
| BOOT1 | Tactile switch | Hold during reset to enter download mode |
| ON/OFF_PB1 | Push button | Power on/off |
| ON/OFF_SW1 | Slide switch | Power on/off (alternate) |
| Q5 | Transistor | GPIO18 HIGH = enables peripheral 3.3 V rail |
| ANT | SMA/U.FL | RF antenna connector for CC1101 radio |

---

## Soldering Notes

**Adding a peripheral to the GPIO header:**
- Use the top header GPIOs (G04–G38) — they are not assigned in the current
  firmware and are free to use
- The bottom connector is reserved for optional modules (speaker / CC1101) —
  do not treat it as free GPIO
- 3.3 V logic only — do not connect 5 V signals directly to any GPIO
- I²C peripherals: SCL = GPIO9, SDA = GPIO10 (already on the bus; just add
  your device with its own pull-up if the bus doesn't already have one)
- SPI peripherals: SCK = GPIO11, MOSI = GPIO17; pick any free GPIO for CS

**Attaching an optional module:**
- The CC1101 sub-GHz radio and speaker/audio modules plug into the bottom
  connector on the front face — they stack on top of the badge
- Schematics: `pcb/CC1101_MOD.kicad_sch`, `pcb/SOUND_MOD.kicad_sch`
- GDO pin on the CC1101 module wires to an ESP32 GPIO for interrupt-driven
  packet reception

**Before soldering:**
- Disconnect the LiPo battery (unplug J2)
- Double-check orientation on any IC — U5 (TCA9534) and U15 (ATECC608B)
  are small SMD packages; consult `pcb/oniondao-badge.kicad_sch` for
  pin 1 orientation
- The display FPC connector (J4) is ZIF (zero insertion force) — lift the
  locking tab before inserting or removing the ribbon cable

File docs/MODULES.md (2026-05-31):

# Swappable Modules

The OnionDAO Badge ships with **two flexible module slots** that share a
common set of GPIOs on the side expansion ports. The schematics for each
module live next to the main board:

| Module | Schematic | What it adds |
|---|---|---|
| **CC1101 Sub-GHz** | [`pcb/CC1101_MOD.kicad_sch`](../pcb/CC1101_MOD.kicad_sch) | 315 / 433 / 868 / 915 MHz SPI radio |
| **Sound (I²S + PDM)** | [`pcb/SOUND_MOD.kicad_sch`](../pcb/SOUND_MOD.kicad_sch) | NS4168 Class-D amp + SPH0641 PDM mic |

Per-variant BOMs are in [`pcb/production/`](../pcb/production/) (e.g.
`bom-list_cc1101.xlsx`, `bom-list_sound.xlsx`).

---

## Why mutual exclusion matters

The CC1101 and Sound modules **both** map their primary signals onto the
same physical pins on J8 / J10. The ESP32 cannot drive a single GPIO as
both an I²S BCLK and an SPI SCK simultaneously. So:

- Decide at build time (compile-time `#define`) or at boot (read a
  module-ID resistor, EEPROM tag, or NVS flag) which module is installed.
- Initialise **only** the matching peripheral.
- Leave the unused pins as inputs with no pull, or tri-state them, so
  the absent module doesn't fight the bus.

If you ship a single firmware image that supports both, gate the
initialisation behind a runtime detect — for example, attempt to read the
CC1101 `PARTNUM` register; if it returns `0x00` you're probably on the
Sound variant.

## Shared GPIO map

The "variants" column in [`PINOUT.md`](PINOUT.md) reflects the three
populations the schematic supports — **L1**, **L2**, and **R**. They
differ only in **which side port** the module physically attaches to.
Pick the column that matches the assembled board.

| Function on **CC1101** | Function on **Sound** | L1 GPIO | L2 GPIO | R GPIO |
|---|---|---|---|---|
| SPI MOSI | Mic PDM data | 48 | 40 | 38 |
| SPI CLK | I²S/PDM bit clock | 47 | 41 | 39 |
| SPI CS | I²S WS / LRCK | 19 | 42 | 16 |
| SPI MISO | I²S audio data out | 42 | 19 | 15 |
| GDO0 IRQ | I²S CTRL | 41 | 47 |  7 |

> Most production boards use the **L1** (left side, primary) wiring.
> Check your specific board's silkscreen or assembled module before
> picking a column.

## CC1101 — Sub-GHz SPI Radio

- ISM bands: 315 / 433 / 868 / 915 MHz (depends on installed matching
  network and antenna).
- Standard 4-wire SPI plus one IRQ line (GDO0).
- Power-gated via the main `PWR` rail — assert `GPIO18` HIGH before use.
- `CS` is active LOW. Hold it across whole register reads/writes.

Suggested libraries:
- C / Arduino: [`SmartRC-CC1101-Driver-Lib`](https://github.com/LSatan/SmartRC-CC1101-Driver-Lib)
- Rust: `cc1101`
- MicroPython: community `cc1101.py` ports

Example use cases: SubGHz scanning, ASK/OOK replay (with authorisation
on whatever you're testing — this is your responsibility), wireless
sensor links, low-power telemetry.

## Sound Module — NS4168 + SPH0641

- **NS4168** — I²S Class-D amplifier driving a small speaker pad on
  the board. Inputs: BCLK, LRCK, SD, CTRL (mode/shutdown).
- **SPH0641** — Knowles PDM digital microphone. Outputs PDM data
  clocked by BCLK; SELECT (= LRCK) picks left vs right channel.
- Same `PWR` rail gating via `GPIO18`.

Typical ESP32-S3 I²S configuration:

```cpp
i2s_chan_config_t chan_cfg = I2S_CHANNEL_DEFAULT_CONFIG(I2S_NUM_0,
                                                       I2S_ROLE_MASTER);
i2s_new_channel(&chan_cfg, &tx, &rx);

i2s_std_config_t std_cfg = {
  .clk_cfg  = I2S_STD_CLK_DEFAULT_CONFIG(44100),
  .slot_cfg = I2S_STD_PHILIPS_SLOT_DEFAULT_CONFIG(I2S_DATA_BIT_WIDTH_16BIT,
                                                  I2S_SLOT_MODE_STEREO),
  .gpio_cfg = {
    .mclk = I2S_GPIO_UNUSED,
    .bclk = GPIO_NUM_47,   // variant L1 — adjust per board
    .ws   = GPIO_NUM_19,
    .dout = GPIO_NUM_42,
    .din  = GPIO_NUM_48,
  },
};
```

For PDM-mic capture, swap the std_cfg for `i2s_pdm_rx_config_t`.

## Authoring a new module

Want to design your own (NFC reader, OLED, joystick, eInk variant)?

1. The mechanical / pin contract is the **J8 / J10 side port** —
   10 pins, GND/VCC on 1/2/9/10 (left) or 1/2 + GPIO (right). See
   [`HARDWARE.md`](HARDWARE.md) §9.
2. All your IO comes from the GPIO pins on that port. If you need more
   than one side, you'll consume both ports.
3. Avoid driving GPIOs that another (already-assembled) module might
   contend for. Document the conflict matrix in your module's README.
4. Open a PR with:
   - the new `*_MOD.kicad_sch` in `pcb/`,
   - a BOM under `pcb/production/`,
   - and a firmware example or guide under `software/`.

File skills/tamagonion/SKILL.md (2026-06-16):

---
name: tamagonion
description: Build, design, and flash a custom Tamagonion virtual pet for the OnionDAO badge
argument-hint: describe your pet — or "flash [file]" — or "char: description [in file]"
allowed-tools: [Read, Write, Edit, Bash, Glob]
version: 1.0.0
---

# Tamagonion

You are an expert developer for the OnionDAO badge. Your job is to build, modify, or flash a Tamagonion Lua script based on the user's request: **$ARGUMENTS**

## Decide what to do

- If `$ARGUMENTS` starts with `flash` → go to **[FLASH ONLY]**
- If `$ARGUMENTS` starts with `char:` → go to **[CHARACTER ONLY]**
- If `$ARGUMENTS` is a pet description (or empty) → go to **[NEW PET]** — if empty, ask the user what kind of pet they want before proceeding

---

# EMBEDDED KNOWLEDGE — Onion OS Lua API

Everything you need is in this section. Do not read any external files.

## Hardware

- **Display:** 264 × 176 px, 1-bit black-and-white e-ink
- **Full refresh:** ~1.5 s, solid black. Triggered by `clear_display()`.
- **Partial refresh:** ~0.5 s, only changed pixels. Used for action-bar-only updates.
- **Buttons:** `left`, `right`, `up`, `down`, `select`, `cancel`
- **MCU:** ESP32-S3, Lua 5.4, standard libs available (`math`, `string`, `table`, `os`)

## Screen layout constants

```lua
local W, H       = 264, 176   -- display size
local CHAR_W     = 11          -- FreeMono 9pt xAdvance (both "small" and "bold" fonts)
-- Zones:
-- Header:     y = 0..28      (black bg, white text)
-- Creature:   cx=132, cy=70  (spans roughly y=30..106)
-- HUN bar:    y = 108..117
-- HAP bar:    y = 119..128
-- NRG bar:    y = 130..139
-- HLT bar:    y = 141..150
-- Divider:    y = 153
-- Action bar: y = 154..175   (text baseline y=171)
local STATS_Y    = {108, 119, 130, 141}
local BAR_X      = 48
local BAR_W      = W - BAR_X - 8   -- 208 px
local BAR_H      = 10
local ACT_BY     = 154
local ACT_BH     = 22
local ACT_BW     = 66
local ACT_TEXT_Y = 171
```

## Drawing API

All drawing goes inside `display_begin()` / `display_commit()`. Nothing hits the screen until commit.

```lua
onion.display_begin()           -- start batch
onion.clear_display()           -- fill white + force full refresh on commit
onion.display_commit()          -- flush (one e-ink refresh)
onion.release_display()         -- return display to OS — call before script exits
onion.display_size()            -- returns {width=264, height=176}

-- Shapes — opts: {fill=true/false, color="black"/"white", clear=false}
onion.display_rect(x, y, w, h, opts)
onion.display_circle(cx, cy, r, opts)
onion.display_round_rect(x, y, w, h, radius, opts)
onion.display_triangle(x0,y0, x1,y1, x2,y2, opts)
onion.display_line(x0, y0, x1, y1)
onion.display_pixel(x, y, opts)

-- Text — baseline at y; color="black"/"white"; font="small"(default)/"bold"; clear=false
onion.display_text(str, x, baseline_y, opts)
onion.display_lines(tbl, x, y, line_height, opts)  -- tbl = array of strings

-- Bitmap from SPIFFS (optional, for sprite-based pets)
onion.display_bitmap(name, x, y, opts)
onion.images()   -- returns array of image filenames available in SPIFFS
```

**Centering text:**
```lua
local function cx_text(str, rx, rw)
    return rx + math.floor((rw - #str * CHAR_W) / 2)
end
```

## Input API

```lua
local btns = onion.buttons()
-- btns.left, btns.right, btns.up, btns.down, btns.select, btns.cancel  → boolean

onion.sleep(ms)       -- yield for ms milliseconds
onion.millis()        -- monotonic uptime in ms (integer)
onion.time()          -- SNTP wall clock seconds (0 if unsynced)
onion.time_synced()   -- true if SNTP succeeded
```

**Edge detection:**
```lua
local last = onion.buttons()
-- in loop:
local btns = onion.buttons()
if btns.left and not last.left then  -- fires once on press-down
    -- handle
end
last = btns
```

## Storage API (NVS)

```lua
onion.kv_set("key", "value")   -- key ≤ 15 chars, value = any string
onion.kv_get("key")            -- returns string or nil
onion.kv_del("key")            -- delete key
onion.kv_list()                -- returns array of key strings
```

## Badge identity

```lua
onion.hardware_id()   -- unique badge hardware ID string
onion.onion_id()      -- attendee Onion ID (0 if unlinked)
onion.wallet()        -- Solana wallet address
onion.username()      -- attendee username string
```

## Sound API

```lua
onion.sound_speaker_begin()
onion.sound_play_tone(hz, duration_ms, volume)  -- volume 0.0–1.0, blocks for duration
onion.sound_speaker_end()
```

## Network API

```lua
onion.http_get(url, headers)              -- returns {status=200, body="..."}
onion.http_post(url, body, headers)       -- returns {status=200, body="..."}
onion.mqtt_connected()                    -- bool
onion.mqtt_subscribe(topic)
onion.mqtt_publish(topic, payload, qos, retain)
onion.mqtt_receive(timeout_ms)            -- returns {topic, payload} or nil
onion.espnow_start(); onion.espnow_stop()
onion.espnow_send(mac, payload)
onion.espnow_receive(timeout_ms)          -- returns {mac, payload, rssi} or nil
```

## Misc

```lua
onion.log(msg)             -- print to serial monitor
onion.secure_random(n)     -- n cryptographic random bytes
onion.sha256(data)         -- hex SHA-256 string
onion.wifi_disconnect(); onion.wifi_reconnect()
```

---

## Game model

### Pet state

```lua
local MAX_STAT = 10
local pet = {
    hunger=MAX_STAT, happiness=MAX_STAT, energy=MAX_STAT, health=MAX_STAT,
    age_ticks=0, stage=0, alive=true, sleeping=false,
}
local function cstat(v) return math.max(0, math.min(MAX_STAT, v)) end
```

### Stage progression

```lua
local STAGE_TICKS = {[0]=0, [1]=3, [2]=20, [3]=60, [4]=120}  -- tune to taste
local function stage_for(t)
    for i = 4, 0, -1 do if t >= STAGE_TICKS[i] then return i end end
    return 0
end
```

### Tick logic

```lua
local TICK_MS = 120000   -- 2 real minutes per tick; use 10000 for fast testing

local function tick_stats()
    if not pet.alive then return pet.stage, pet.stage end
    local old = pet.stage
    pet.age_ticks = pet.age_ticks + 1
    pet.stage     = stage_for(pet.age_ticks)
    if old == 0 then return old, pet.stage end
    if pet.sleeping then
        pet.energy    = cstat(pet.energy + 3)
        pet.happiness = cstat(pet.happiness + 1)
        if pet.energy >= MAX_STAT then pet.sleeping = false end
    else
        pet.hunger = cstat(pet.hunger - 1)
        pet.energy = cstat(pet.energy - 1)
        if pet.age_ticks % 2 == 0 then pet.happiness = cstat(pet.happiness - 1) end
    end
    if pet.hunger    == 0 then pet.health = cstat(pet.health - 2) end
    if pet.happiness == 0 then pet.health = cstat(pet.health - 1) end
    if pet.hunger >= 7 and pet.happiness >= 5 and pet.energy >= 5 then
        pet.health = cstat(pet.health + 1)
    end
    if pet.health <= 6 and math.random(100) <= 2 then
        pet.health = cstat(pet.health - 1)
    end
    if pet.health == 0 then pet.alive = false end
    return old, pet.stage
end
```

### NVS save / load

```lua
local function save_pet()
    if not onion.kv_set then return end
    onion.kv_set("pet", string.format(
        '{"h":%d,"hp":%d,"e":%d,"hl":%d,"a":%d,"alive":%s,"sl":%s}',
        pet.hunger, pet.happiness, pet.energy, pet.health, pet.age_ticks,
        pet.alive and "true" or "false", pet.sleeping and "true" or "false"))
end

local function load_pet()
    if not onion.kv_get then return end
    local s = onion.kv_get("pet"); if not s or s == "" then return end
    local function n(k) return tonumber(s:match('"'..k..'":(%d+)')) end
    if n("h")  then pet.hunger    = cstat(n("h"))  end
    if n("hp") then pet.happiness = cstat(n("hp")) end
    if n("e")  then pet.energy    = cstat(n("e"))  end
    if n("hl") then pet.health    = cstat(n("hl")) end
    if n("a")  then pet.age_ticks = n("a")         end
    pet.alive    = (s:find('"alive":true') ~= nil)
    pet.sleeping = (s:find('"sl":true')    ~= nil)
    pet.stage    = stage_for(pet.age_ticks)
end
```

---

## Draw helpers (copy verbatim into every pet script)

```lua
local function draw_header(pet_name, stage_names)
    onion.display_rect(0, 0, W, 29, {fill=true, color="black"})
    onion.display_text(pet_name, 8, 21, {clear=false, color="white", font="bold"})
    onion.display_text(stage_names[pet.stage] or "?", 110, 21,
        {clear=false, color="white", font="bold"})
    local astr = "D" .. math.floor(pet.age_ticks / 12)
    onion.display_text(astr, W - 8 - #astr * CHAR_W, 21,
        {clear=false, color="white", font="bold"})
end

local function draw_stat_bar(label, y, val)
    onion.display_text(label, 8, y + BAR_H, {clear=false, color="black", font="small"})
    onion.display_rect(BAR_X, y, BAR_W, BAR_H, {clear=false, color="black"})
    local fill = math.floor(val * (BAR_W - 2) / MAX_STAT)
    if fill > 0 then
        onion.display_rect(BAR_X + 1, y + 1, fill, BAR_H - 2,
            {clear=false, fill=true, color="black"})
    end
end

local function draw_action_bar(sel, labels, feedback)
    if feedback and feedback ~= "" then
        onion.display_rect(0, ACT_BY, W, ACT_BH, {clear=false, fill=true, color="black"})
        onion.display_text(feedback, cx_text(feedback, 0, W), ACT_TEXT_Y,
            {clear=false, color="white", font="small"})
        return
    end
    for i = 0, 3 do
        local bx  = i * ACT_BW
        local lbl = labels[i]
        local lx  = bx + math.floor((ACT_BW - #lbl * CHAR_W) / 2)
        if i == sel then
            onion.display_rect(bx, ACT_BY, ACT_BW, ACT_BH, {clear=false, fill=true, color="black"})
            onion.display_text(lbl, lx, ACT_TEXT_Y, {clear=false, color="white", font="small"})
        else
            onion.display_rect(bx, ACT_BY, ACT_BW, ACT_BH, {clear=false, color="black"})
            onion.display_text(lbl, lx, ACT_TEXT_Y, {clear=false, color="black", font="small"})
        end
    end
end
```

---

## Character design guide

### Shapes approach

`draw_creature(stage, frame, happy, sick, sleeping)` centered at cx=132, cy=70.

- stage 0 (EGG): egg shape only, no face, `return` early
- stage 1–4: scale `r = 10 + stage * 4` → 14, 18, 22, 26
- frame 0 = idle, frame 1 = dance — only limb endpoints differ
- sick: X eyes; sleeping: line eyes + `"z"/"Z"` text; normal: filled circles
- happy mouth: upward V; sad: downward V
- `color="white"` fills to carve out shapes

```lua
local function draw_creature(stage, frame, happy, sick, sleeping)
    local cx, cy = 132, 70
    if stage == 0 then
        onion.display_round_rect(cx-14, cy-22, 28, 40, 12, {fill=true, color="black"})
        onion.display_round_rect(cx-11, cy-19, 22, 33,  9, {fill=true, color="white"})
        return
    end
    local r  = 10 + stage * 4
    local ey = cy - math.floor(r / 4)
    local ex = math.floor(r * 2 / 5)
    local my = cy + math.floor(r / 3)
    onion.display_circle(cx, cy, r+2, {fill=true, color="black"})
    onion.display_circle(cx, cy, r,   {fill=true, color="white"})
    if sick then
        onion.display_line(cx-ex-2,ey-2,cx-ex+2,ey+2); onion.display_line(cx-ex+2,ey-2,cx-ex-2,ey+2)
        onion.display_line(cx+ex-2,ey-2,cx+ex+2,ey+2); onion.display_line(cx+ex+2,ey-2,cx+ex-2,ey+2)
    elseif sleeping then
        onion.display_line(cx-ex-2,ey,cx-ex+2,ey); onion.display_line(cx+ex-2,ey,cx+ex+2,ey)
    else
        onion.display_circle(cx-ex,ey,2,{fill=true,color="black"})
        onion.display_circle(cx+ex,ey,2,{fill=true,color="black"})
    end
    if happy then
        onion.display_line(cx-4,my,cx,my+3); onion.display_line(cx,my+3,cx+4,my)
    else
        onion.display_line(cx-4,my+3,cx,my); onion.display_line(cx,my,cx+4,my+3)
    end
    if frame==0 then
        onion.display_line(cx-(r+2),cy+2,cx-(r+10),cy+8)
        onion.display_line(cx+(r+2),cy+2,cx+(r+10),cy+8)
    else
        onion.display_line(cx-(r+2),cy-2,cx-(r+10),cy-10)
        onion.display_line(cx+(r+2),cy-2,cx+(r+10),cy-10)
    end
    if sleeping then
        onion.display_text("z",cx+r+4, cy-8, {clear=false,font="small",color="black"})
        onion.display_text("Z",cx+r+10,cy-18,{clear=false,font="small",color="black"})
    end
end
```

### ASCII art approach

```lua
local ASCII = {
    idle  = {"  (o_o)  ","  [___]  ","  /| |\\  "},
    dance = {" \\(^_^)/ ","  [___]  ","   | |   "},
    sad   = {"  (;_;)  ","  [___]  ","  /| |\\  "},
    sick  = {"  (x_x)  ","  [___]  ","   | |   "},
    sleep = {"  (-_-)  ","  [___]  ","  /| |\\  "},
}
local function draw_creature(stage, frame, happy, sick, sleeping)
    local art = sick and ASCII.sick or sleeping and ASCII.sleep
        or (happy and (frame==1 and ASCII.dance or ASCII.idle) or ASCII.sad)
    onion.display_lines(art, 70+(4-stage)*2, 38, 16, {clear=false, font="small"})
end
```

### Play dance (partial update, creature zone only)

```lua
local function play_dance()
    if pet.stage == 0 then return end
    for _=1,4 do
        for f=0,1 do
            onion.display_begin()
            onion.display_rect(64,29,136,78,{fill=true,color="white"})
            draw_creature(pet.stage,f,true,false,false)
            onion.display_commit()
            onion.sleep(300)
        end
    end
end
```

---
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

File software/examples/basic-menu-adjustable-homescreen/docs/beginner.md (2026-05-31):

# OnionDAO Badge — Beginner Guide

No hardware experience needed. This guide gets you from box to badge in a few minutes.

---

## What is this?

The OnionDAO Badge is a wearable computer you can hold in your hand. It has a small
black-and-white screen, six buttons, and a chip that can store secret keys. You can
put your own artwork on the screen, navigate menus, and learn about the hardware and
code that makes it work — all from the badge itself.

---

## Powering on

1. Connect the USB-C cable to the badge and to your computer (or any USB power source).
2. Flip the **ON/OFF** slide switch on the back of the board to the ON position.
3. The screen will flash white, then show either your custom home image or the badge's
   name and chip specs.

If the badge goes dark after a minute, it went to sleep — press any button to wake it.

---

## The six buttons

                                             [ CANCEL ]
                             [ UP ]  
                    [ LEFT ]        [ RIGHT ]  
                            [ DOWN ]
                                                   [ SELECT ]
```

| Button | What it does |
|--------|-------------|
| UP / DOWN | Move the menu cursor up or down |
| SELECT | Open the highlighted menu item |
| CANCEL | Go back to the previous screen |
| LEFT / RIGHT | Flip pages in the Hardware or Software Guide |

---

## Navigating the menu

Press any button from the home screen to open the main menu. You will see seven items:

| Menu item | What it shows |
|-----------|---------------|
| 1. System Info | The chip model, clock speed, and memory |
| 2. Button Test | Watch which button you press light up in real time |
| 3. I2C Scanner | Lists every chip the badge found on its internal bus |
| 4. RNG / Crypto | 16 random bytes generated by the hardware crypto chip |
| 5. Display Test | Four graphics patterns to confirm the screen is working |
| 6. Hardware Guide | 10 short lessons about the physical components |
| 7. Software Guide | 10 short lessons about the C++ code that runs the badge |

Use UP / DOWN to move the cursor, SELECT to enter, and CANCEL to go back.

---

## Putting your own art on the badge

You will need Python 3 installed on your computer.

1. Install the dependencies (one time only):
   ```
   pip install pillow pyserial
   ```

2. Connect the badge via USB and make sure it is awake (press any button if the
   screen is dark).

3. Open the art tool:
   ```
   python3 badge-art/badge_art.py
   ```
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

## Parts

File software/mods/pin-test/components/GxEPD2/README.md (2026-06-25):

# GxEPD2
## Arduino Display Library for SPI E-Paper Displays

- With full Graphics and Text support using Adafruit_GFX

- For SPI e-paper displays from Dalian Good Display 
- and SPI e-paper boards from Waveshare

### important note:
- the display panels are for 3.3V supply and 3.3V data lines
- never connect data lines directly to 5V Arduino data pins, use e.g. 4k7/10k resistor divider
- series resistor only is not enough for reliable operation (back-feed effect through protection diodes)
- 4k7/10k resistor divider may not work with flat cable extensions or Waveshare 4.2 board, use level converter then
- do not forget to connect GND
- the actual Waveshare display boards now have level converters and series regulator, safe for 5V
- use 3k3 pull-down on SS for ESP8266 for boards with level converters
- note that 7.5" e-paper displays don't work reliable if fed from 3.3V Arduino pin
- note that Waveshare boards with "clever" reset circuit may need shortened reset pulse
- use `init(115200, true, 2, false)` for Waveshare boards with "clever" reset circuit
- note that Waveshare boards with "clever" reset circuit need 1k pull-up on RST on ESP8266, or different pin
- note that the new Waveshare Universal e-Paper Raw Panel Driver HAT Rev 2.3 needs PWR connected to VCC or driven HIGH
- see https://www.waveshare.com/wiki/E-Paper_Driver_HAT

### Paged Drawing, Picture Loop
 - This library uses paged drawing to limit RAM use and cope with missing single pixel update support
 - buffer size can be selected in the application by template parameter page_height, see GxEPD2_Example
 - Paged drawing is implemented as picture loop, like in U8G2 (Oliver Kraus)
 - see https://github.com/olikraus/u8glib/wiki/tpictureloop
 - Paged drawing is also available using drawPaged() and drawCallback(), like in GxEPD
- ` // GxEPD style paged drawing; drawCallback() is called as many times as needed `
- ` void drawPaged(void (*drawCallback)(const void*), const void* pv) `
- paged drawing is done using Adafruit_GFX methods inside picture loop or drawCallback

### Full Screen Buffer Support
 - full screen buffer is selected by setting template parameter page_height to display height
 - drawing to full screen buffer is done using Adafruit_GFX methods without picture loop or drawCallback
 - and then calling method display()

### Low Level Bitmap Drawing Support
 - bitmap drawing support to the controller memory and screen is available:
 - either through the template class instance methods that forward calls to the base display class
 - or directly using an instance of a base display class and calling its methods directly

### Supporting Arduino Forum Topics:

- Waveshare e-paper displays with SPI: http://forum.arduino.cc/index.php?topic=487007.0
- Good Display ePaper for Arduino : https://forum.arduino.cc/index.php?topic=436411.0
- Note that these topics are closed. Use only for reference.
- create a new topic for each question or issue in https://forum.arduino.cc/c/using-arduino/displays/23

### Note on documentation
- GxEPD2 uses Adafruit_GFX for Graphics and Text support, which is well documented there
- GxEPD2 uses meaningful method names, and has some comments in the header files
- consult the header files GxEPD2_BW.h, GxEPD2_3C.h and GxEPD2_GFX.h
- for the concept of paged drawing and picture loop see: 
- https://github.com/olikraus/u8glib/wiki/tpictureloop

### Note on issues and pull requests
- issues should be reported in the Arduino Forum Displays.
- issues on GitHub are disabled; there were too many false issues.
- pull requests are not welcome, will not be merged.
- pull requests can't be disabled, but will be closed.
- please place information about interesting fork additions in the Arduino Forum Displays.

### Supported SPI e-paper panels from Good Display:
- GDEW0102T4     1.02" b/w 80x128, UC8175
- DEPG0150BN     1.50" b/w 200x200, SSD1681, e.g. LILYGO® TTGO T5 V2.4.1 1.50 inch
- GDEP015OC1     1.54" b/w 200x200, IL3829, no longer available
- GDEH0154D67    1.54" b/w 200x200, SSD1681, replacement for GDEP015OC1
- GDEW0154T8     1.54" b/w 152x152, UC8151 (IL0373)
- GDEW0154M09    1.54" b/w 200x200, JD79653A
- GDEW0154M10    1.54" b/w 152x152, UC8151D, DES
- GDEY0154D67    1.54" b/w 200x200, SSD1681
- GDEW0154Z04    1.54" b/w/r 200x200, IL0376F, no longer available
- GDEH0154Z90    1.54" b/w/r 200x200, SSD1681, replacement for GDEW0154Z04
- GDE0213B1      2.13" b/w 122x250, IL3895, phased out
- GDEH0213B72    2.13" b/w 122x250, SSD1675A (IL3897), replacement for GDE0213B1
- GDEH0213B73    2.13" b/w 122x250, SSD1675B, new replacement for GDE0213B1, GDEH0213B72
- GDEM0213B74    2.13" b/w 122x250, SSD1680
- GDEW0213I5F    2.13" b/w 104x212, UC8151 (IL0373), flexible
- GDEW0213T5D    2.13" b/w 104x212, UC8151 (IL0373)
- GDEW0213M21    2.13" b/w 104x212, UC8151 (IL0373), DES
- GDEW0213Z16    2.13" b/w/r 104x212, UC8151 (IL0373)
- GDEW0213Z19    2.13" b/w/r 104x212, UC8151D
- GDEY0213Z98    2.13" b/w/r 122x250, SSD1680
- GDEY0213F51    2.13" 4-color 122x250, JD79661
- DEPG0213BN     2.13" b/w 122x250, SSD1680, e.g. LILYGO® TTGO T5 V2.3.1 2.13 inch
- GDEY0213B74    2.13" b/w 122x250, SSD1680
- GDEW026T0      2.6" b/w 152x296, UC8151 (IL0373)
- GDEW026M01     2.6" b/w 152x296, UC8151 (IL0373), DES
- DEPG0266BN     2.66" b/w 152x296, SSD1680, e.g. LILYGO® TTGO T5 2.66 inch
- GDEY0266Z90    2.66" b/w/r 152x296, SSD1680
- GDEY0266F51H   2.66" 4-color 184x460, JD79667
- GDEW027C44     2.7" b/w/r 176x264, IL91874
- GDEW027W3      2.7" b/w 176x264, EK79652 (IL91874)
- GDEY027T91     2.7" b/w 176x264, SSD1680
- GDEH029A1      2.9" b/w 128x296, SSD1608 (IL3820)
- GDEW029T5      2.9" b/w 128x296, UC8151 (IL0373)
- GDEW029T5D     2.9" b/w 128x296, UC8151D
- GDEW029I6FD    2.9" b/w 128x296, UC8151D, flexible
- GDEM029T94     2.9" b/w 128x296, SSD1680
- GDEW029M06     2.9" b/w 128x296, UC8151D, DES
- GDEW029Z10     2.9" b/w/r 128x296, UC8151 (IL0373)
- GDEH029Z13     2.9" b/w/r 128x296, UC8151D
- GDEM029C90     2.9" b/w/y 128x296, SSD1680
- DEPG0290BS     2.9" b/w 128x296, SSD1680, e.g. LILYGO® TTGO T5 V2.4.1 2.9"
- GDEY029T94     2.9" b/w 128x296, SSD1680
- GDEY029T71H    2.9" b/w 168x384, SSD1685
- GDEY029F51H    2.9" 4-color 168x384, JD79667
- Waveshare3inch4color 3.0" 4-color 168x400
- GDEQ031T10     3.1" b/w 240x320, UC8253
- ED037TC1       3.7" b/w 280x480, SSD1677, Waveshare 3.7"
- GDEW0371W7     3.7" b/w 240x416, UC8171 (IL0324)
- GDEW042T2      4.2" b/w 400x300, UC8176 (IL0398)
- GDEW042M01     4.2" b/w 400x300, UC8176 (IL0398), DES
- GDEW042Z15     4.2" b/w/r 400x300, UC8176 (IL0398)
- GDEQ042Z21     4.2" b/w/r 400x300, UC8276, (Waveshare V2)
- GDEY042Z98     4.2" b/w/r 400x300, SSD1683
- GDEY042T81     4.2" b/w 400x300, SSD1683
- GDEY0420F51    4.2" 4-color 400x300, HX8717
- GDEQ0426T82    4.26" b/w 800x480, SSD1677
- Waveshare437inch4color Waveshare 4.37" 4-color e-paper display 512x368 
- ACeP565        5.65" Waveshare 5.65" 7-color e-paper display 600x448
- GDEP0565D90    5.65" 7-color 600x448
- GDEY0579T93    5.79" b/w 792x272, SSD1683
- GDEY0579Z93    5.79" b/w/r 792x272, SSD1683
- GDEY0579F51    5.79" 4-color 792x272, HX8717
- GDEW0583T7     5.83" b/w 600x448, UC8159c (IL0371)
- GDEW0583T8     5.83" b/w 648x480, EK79655 (GD7965)
- GDEW0583Z83    5.83" b/w/r 648x480, EK79655 (GD7965)
- GDEQ0583T31    5.83" b/w 648x480, UC8179
- GDEQ0583Z31    5.83" b/w/r 648x480, UC8179C
- GDEY073D46     7.3" 800x480 7-color
- GDEP073E01     7.3" 800x480 7-color
- ACeP730        7.3" Waveshare 7-color e-paper display 800x480, PhotoPainter
- GDEW075T8      7.5" b/w 640x384, UC8159c (IL0371)
- GDEW075T7      7.5" b/w 800x480, EK79655 (GD7965)
- GDEY075T7      7.5" b/w 800x480, UC8179 (GD7965)
- GDEW075Z09     7.5" b/w/r 640x384, UC8159c (IL0371)
- GDEW075Z08     7.5" b/w/r 800x480, EK79655 (GD7965)
- GDEH075Z90     7.5" b/w/r 880x528, SSD1677
- GDEM102T91    10.2" b/w 960x640, SSD1677
- GDEM1085T51   10.85 b/w 1360x480, JD79686AB
- GDEH116T91    11.6" b/w 960x640, SSD1677
- GDEY116Z91    11.6" b/w/r 960x640, SSD1677
- GDEY116F51    11.6" 4-color 960x640, SSD2677
- GDEW1248T3    12.48" b/w 1304x984, UC8179
- GDEY1248Z51   12.48" b/w/r 1304x984, UC8179
- GDEM133T91    13.3" b/w 960x680, SSD1677
- GDEM133Z91    13.3" b/w/r 960x680, SSD1677
#### Supported SPI e-paper panels & boards from Waveshare: compare with Good Display, same panel
#### other supported panels
- GYE042A87     4.2" b/w 400x300, SSD1683 (HINK-E042-A07-FPC-A1)
- SE0420NQ04    4.2" b/w 400x300, UC8276C (OPM042A2_V1.0)
- ED060SCT        6" grey levels, on Waveshare e-Paper IT8951 Driver HAT
- ED060KC1        6" grey levels, 1448x1072, on Waveshare e-Paper IT8951 Driver HAT
- ED078KC2      7.8" grey levels, 1872x1404, on Waveshare e-Paper IT8951 Driver HAT
- ES103TC1     10.3" grey levels, 1872x1404, on Waveshare e-Paper IT8951 Driver HAT

### I can and will only support e-paper panels I have!
- I can accept panel donations to add support to GxEPD2.
- But only few panels at any time, and only panels from known sources. 
- Adding support will take as much time as needed.

### Version 1.5.9
- added Power Save command (PWS) to GDEY075T7 init (issue with dithered bitmaps)
- added support for GDEY0579T93 5.79" b/w 792x272, SSD1683
- added support for GDEY0579Z93 5.79" b/w/r 792x272, SSD1683
- added support for GDEY0579F51 5.79" 4-color 792x272, HX8717
- the GDEY0579F51 has partial window addressing capability, 
- but of little use, because the controller buffer is modified during refresh
- partial window refresh can't be used on GDEY0579F51, refresh is full screen
- added support for GDEY042Z98 4.2" b/w/r 400x300, SSD1683
- GDEY042Z98 has "fast" full refresh and supports fast b/w partial refresh
- added support for GDEP073E01 7.3" 800x480 7-color
#### Version 1.5.8
- added support for GDEP0565D90 5.65" 7-color 600x448
- added support for GDEY116F51 11.6"  4-color 960x640, SSD2677
- added support for GDEY029T71H 2.9" b/w 168x384, SSD1685
#### Version 1.5.7
- added support for GDEY0213F51 2.13" 4-color 122x250, JD79661
- added support for GDEM1085T51 10.85 b/w 1360x480, JD79686AB
#### Version 1.5.6
- version for ongoing fixes and additions
- added support for GYE042A87  4.2" b/w 400x300
- added support for SE0420NQ04 4.2" b/w 400x300
- added support for GDEQ0583Z31 5.83" b/w/r 648x480
- added support for GDEM102T91 10.2" b/w 960x640, SSD1677
- added support for GDEY116Z91 11.6" b/w/r 960x640, SSD1677
- added support for GDEM133T91 13.3" b/w 960x680, SSD1677
- added support for GDEM133Z91 13.3" b/w/r 960x680, SSD1677
- improved differential refresh for SE0420NQ04
- improved full refresh for SE0420NQ04
- fixed driver class GxEPD2_213.cpp
#### Version 1.5.5
- updated 7-color driver classes (design cleanup fixed)
- note: Waveshare PhotoPainter doesn't work with MBED Pico package
- note: use package https://github.com/earlephilhower/arduino-pico for PhotoPainter
#### Version 1.5.4
- added support for GDEQ031T10 3.1" b/w 240x320
- updated support for GDEY075T7 7.5" b/w 800x480
- renamed driver class GxEPD2_750_YT7 to GxEPD2_750_GDEY075T7
- the actual GDEY075T7 panels have fast full refresh capability
- added support for Waveshare 7.3" 7-color, driver class GxEPD2_730c_ACeP_730
- added support for Waveshare 7.3" 7-color PhotoPainter with RPi Pico RP2040
- updated b/w driver classes for SSD controllers
- updated 7-color driver classes (design cleanup)
#### Version 1.5.3
- added support for GDEQ0426T82 4.26" b/w 800x480
- added support for GDEY0266F51H 2.66" 4-color 184x460
- added support for GDEY029F51H 2.9" 4-color 168x384
- added support for GDEY0420F51 4.2" 4-color 400x300
- added support for Waveshare 3.00" 4-color e-paper display 168x400
- updated support for Waveshare 4.37" 4-color e-paper display 512x368
- the 4-color displays have partial window addressing and refresh
- renamed GDEY042T91 to its new official name GDEY042T81
#### Version 1.5.2
- added support for Waveshare 4.37" 4-color e-paper display 512x368
- fixed __has_include test (for packages that don't support __has_include)
- added WIDTH_VISIBLE for correct graphics width for 2.13" b/w 122x250
- added end() method, to release SPI and reset all pins to INPUT
#### Version 1.5.1
- added support for GDEY0154D67 1.54" b/w 200x200
- added support for GDEY0213B74 2.13" b/w 128x250
- updated support for GDEY027T91 2.7" b/w 176x264
- renamed driver class for GDEY027T91 to GxEPD2_270_GDEY027T91
- added support for GDEY029T94 2.9" b/w 128x296
- added support for GDEY042T91 4.2" b/w 400x300
- added support for GDEQ0583T31 5.83" b/w 648x480
- these panels have fast full refresh capability
- fast full refresh can be disabled in the class header for low temperature use
- added support for GDEY073D46 7.3" 800x480 7-color
- all these new panels have been donated by Good Display
- added __has_include test to GxEPD2_BW.h, GxEPD2_3C.h, GxEPD2_7C
- this allows to remove or put aside unused driver classes for faster compile
- several fixes and improvements
#### Version 1.5.0
- added support for GDEY075T7 7.5" b/w 800x480
- updated GxEPD2_Example, added HSPI use for Waveshare ESP32 Driver Board
- updated GxEPD2_SD_AVR_Example, fixes for BMP handling
- updated GxEPD2_SD_Example, fixes for BMP handling, added HSPI use for Waveshare ESP32 Driver Board
- updated GxEPD2_SerialFlash_Example, fixes for BMP handling
- updated GxEPD2_SerialFlash_Loader, updated https certificates and use
- updated GxEPD2_Spiffs_Example, fixes for BMP handling
- updated GxEPD2_Spiffs_Loader, updated https certificates and use
- added GxEPD2_WiFi_CertStore_Example, use of a BearSSL CertStore on ESP8266, like a browser
- added GxEPD2_WiFi_CertStore_Loader, download root certificates (from Mozilla) to ESP8266 flash
- updated GxEPD2_WiFi_Example, fixes for BMP handling, updated https certificates and use
- updated GxEPD2_WS_ESP32_Driver, added HSPI use for Waveshare ESP32 Driver Board
#### Version 1.4.9
- added missing constructor lines to GxEPD2_display_selection.h
- added panel details to comments in GxEPD2_display_selection.h
- added panel details to Supported SPI e-paper panels in README.md
#### Version 1.4.8
- added support for GDEY027T91 2.7" b/w 176x264
- added support for GDEY1248Z51 12.48" b/w/r 1304x984
- fixed name of panel DEPG0150BN
- updated certificate and fingerprint for GitHub download in GxEPD2_WiFi_Example
#### Version 1.4.7
- added support for DEPG0150BN 1.50" b/w 200x200, e.g. LILYGO® TTGO T5 V2.4.1 1.50 inch
- added support for DEPG0213BN 2.13" b/w 128x250, e.g. LILYGO® TTGO T5 V2.3.1 2.13 inch
- added support for DEPG0266BN 2.66" b/w 152x296, e.g. LILYGO® TTGO T5 2.66 inch
- added support for DEPG0290BS 2.9"  b/w 128x296, e.g. LILYGO® TTGO T5 V2.4.1 2.9"
- added support for ES103TC1 10.3" grey levels, 1872x1404, on Waveshare e-Paper IT8951 Driver HAT
#### Version 1.4.6
- added support for GDEY0266Z90 2.66" b/w/r 152x296
- added support for GDEW0583Z83 5.83" b/w/r 648x460
#### Version 1.4.5
- added support for GDEY0213Z98 2.13" b/w/r 122x250
- tested with LOLIN 2.13" Tri-Color eInk / ePaper 250x122 Display Shield
- https://www.aliexpress.com/item/1005003020667903.html
#### Version 1.4.4
- interim update to solve compiler warnings (ALL for GCC for AVR)
#### Version 1.4.3
- added option to select an alternate HW SPI channel and/or SPI settings
- by method selectSPI(SPIClass& spi, SPISettings spi_settings) of driver base class GxEPD2_EPD
- by calling selectSPI before calling init() of display class
- or by calling extended init() method that has these parameters added
- tested with RPi Pico RP2040 using Good Display DESPI-PICO connection shield
- updated GxEPD2_Example to show use with DESPI-PICO
- DESPI-PICO: see https://www.good-display.com/product/393.html
#### Version 1.4.2
- added support for Waveshare 3.7" b/w board and panel ED037TC1
- waveform tables for ED037TC1 are taken unmodified from Waveshare demo code
- refresh behavior with ED037TC1 with GxEPD2 is not perfect, could not be resolved
- ISSUE RESOLVED: RESE needs to be 3 ohms on DESPI-C02 for this panel, Waveshare schematics is wrong
- added differential refresh for GDEH116T91, waveform table taken from ED037TC1
- differential refresh for GDEH116T91 looks ok; can be disabled with hasFastPartialUpdate = false
- increased sustain phase for differential refresh on GDEW042T2
#### Version 1.4.1
- fix for Waveshare "clever" reset circuit: power controller before reset pulse
#### Version 1.4.0
- changed the default reset duration to 10ms instead of 20ms
- changed the delay after reset to 10ms or reset duration, whichever is higher, instead of 200ms
- added a busyCallback feature, to allow to service periodic actions during wait for BUSY termination
- ` // register a callback function to be called during _waitWhileBusy continuously. `
- ` void setBusyCallback(void (*busyCallback)(const void*), const void* busy_callback_parameter = 0); `
- added example GxEPD2_RotaryUsingBusyCallback.ino
#### Version 1.3.9
- fix for STM32 official package pin number range (int16_t)
- fix for refresh(int16_t x, int16_t y, int16_t w, int16_t h) methods screen intersection
#### Version 1.3.8
- added support for GDEQ042Z21 4.2" b/w/r 400x300 panel or Waveshare 4.2" V2 b/w/r board
- the Waveshare 4.2" V2 b/w/r board requires the shortened reset pulse
- added support for GDEW029I6FD 2.9" b/w 128x296 flexible board
- some fixes and improvement for the new style panel selection
#### Version 1.3.7
- added support for GDEW0102T4 1.02" b/w 80x128 panel or Waveshare 1.02" b/w board
- the GDEW0102T4 panel has a different connector than the other SPI panels
- the GDEW0102T4 panel can be used with the DESPI-C102 connection module
- https://buy-lcd.com/products/connection-board-demo-kit-for-102-inch-e-ink-display-despi-c102
- my test have been done with the Waveshare 1.02" b/w board
#### Version 1.3.6
- added support for Waveshare 2.9" b/w V2, driver class GxEPD2_290_T94_V2
- Waveshare 2.9" b/w V2 uses a GDEM029T94 variant without partial update wft in OTP
- driver class GxEPD2_290_T94_V2 uses partial update wft written to registers
- added NOTE for RST pull-up on ESP8266 with "clever" reset circuit, or alternate pin
#### Version 1.3.5
- added support for GDEM0213B74 122x250 b/w e-paper panel
- added support for ED078KC2, 7.8" grey levels, 1872x1404, on Waveshare e-Paper IT8951 Driver HAT
#### Version 1.3.4
- added support for GDEH116T91 960x640 b/w e-paper panel
- GDEH116T91 has only full screen refresh, no wavetable for differential refresh yet
- added support for processor Arduino Nano RP2040 Connect to the examples
- added general fast b/w refresh for capable 3-color displays GDEW0213Z19, GDEW029Z13
- added example GxEPD2x_FastBlackWhiteOnColor.ino for GDEW0213Z19, GDEW029Z13
- evaluation of other fast b/w capable 3-color panels may follow
#### Version 1.3.3
- added b/w differential refresh method to GDEW0213Z19
- added b/w differential refresh method to GDEW029Z13
- up to 100 b/w fast refreshes have been possible (resulting in slightly reddish background)
- added experimental example GxEPD2x_MixedTest for proof of concept
- GxEPD2x_MixedTest needs enough RAM for 2 GFXCanvas1 objects
- general 3-color mixed refresh in GxEPD2 is in evaluation, for capable panels
#### Version 1.3.2
- added support for GDEW0213T5D 104x212 b/w e-paper panel
- added support for GDEW029T5D  128x296 b/w e-paper panel
- added support for GDEW0213Z19 104x212 b/w/r e-paper panel
- added support for GDEW029Z13  128x296 b/w/r e-paper panel
- both GDEW0213Z19 and GDEW029Z13 support only full screen refresh (controller issue)
#### Version 1.3.1
- added support for GDEM029C90 128x296 b/w/y e-paper panel
- GDEM029C90 has a very long refresh time of about 27 seconds
- GDEM029C90 has partial update (window addressing) of controller memory
- GDEM029C90 supports only full refresh of screen
#### Version 1.3.0
- added support for GDEM029T94 128x296 b/w e-paper panel
- added support for GDEW026M01 152x296 b/w new DES e-paper panel
- the new GDEW026M01 DES b/w e-paper panel has higher contrast and wide temperature range
- differential refresh (fast partial update) is supported for normal temperature range
- disable differential refresh for extended temperatures by setting hasFastPartialUpdate = false;
- the differential waveform table for GDEW026M01 is experimental and may need improvement
- major update of display selection in the examples to make additions easier:
- old style selection is now in separate include files GxEPD2_display_selection.h 
- and GxEPD2_display_selection_added.h
- added new style display selection in include file GxEPD2_display_selection_new_style.h
- either selection style can be used. old style is intended for easy copying of constructor lines.
#### Version 1.2.16
- fix for GDEH0154D67, to work independent of OTP version (ping-pong issue)
#### Version 1.2.15
- added support for GDEW0213M21 2.13" 104x212 b/w new DES e-paper panel
- added support for GDEW029M06 2.9" 128x296 b/w new DES e-paper panel
- added support for GDEW042M01 4.2" 400x300 b/w new DES e-paper panel
- these new DES b/w e-paper panels have higher contrast and wide temperature range
- differential refresh (fast partial update) is supported for normal temperature range
- disable differential refresh for extended temperatures by setting hasFastPartialUpdate = false;
- the GDEW042M01 I have is a preliminary version, differential waveform may need update
#### Version 1.2.14
- added support for 6" 1448x1072 ED060KC1 on Waveshare e-Paper IT8951 Driver HAT
- fixed GxEPD2_WiFi_Example.ino: new GitHub fingerprint for ESP8266, certificate for ESP32
- fixed color discriminator for 7-color display in GxEPD2_7C.h
- added multicolor support for 7-color display in GxEPD2_WiFi_Example, GxEPD2_Spiffs_Example,
- and GxEPD2_SD_Example, GxEPD2_SerialFlash_Example
- fixed paged write to 7-color display controller (transaction and CS handling issue)
- some more fixes
#### Version 1.2.13
- added support for GDEH0154Z90 1.54" 200x200 b/w/r, replacement for GDEW0154Z04
- GDEH0154Z90 has partial window addressing, but no partial window refresh
- added some missing constructor examples, e.g. for IT8951 Driver HAT on Due
- cleaned-up wiring information in the examples
#### Version 1.2.12
- fixed GxEPD2_MinimumExample.ino to draw black on white (white on white was invisible)
- added example GxEPD2_HelloWorld.ino
- updated wiring info and constructor parameters for the actual Waveshare e-Paper ESP8266 Driver Board
- added some missing explicit initializers (nobody noticed as compilers usually initialize simple members)
#### Version 1.2.11
- added support for Waveshare 5.65" 7-color e-paper display 600x448
- the unknown controller of this display doesn't support partial update, as far as known
- 7-color graphics support is available with class GxEPD2_7C
- 7-color graphics support requires paging even on ESP32
- 7-color graphics support causes heavy paging on Arduino UNO, gets very slow
- refresh is quite fast for a color e-paper display: 12 seconds
#### Version 1.2.10
- added support for GDEH075Z90 7.5" b/w/r 880x528
- the controller of GDEH075Z90 supports partial update, but refesh is full screen
- the controller of GDEH075Z90 doesn't support differential update (not possible on 3-color anyway)
- note: the connector of  the GDEH075Z90 is mirrored; connects downward on DESPI-C02
- added optional init parameter "reset_duration" in ms, same default 20ms as before
- reset_duration = 2 may help with "clever" reset circuit of newer boards from Waveshare
#### Version 1.2.9
- added support for GDEW0154T8 1.54" b/w 152x152
- added support for GDEW0154M09 1.54" b/w 200x200
- added support for GDEW0154M10 1.54" b/w 152x152 DES
- added support for GDEW0583T8 5.83" b/w 648x460
- added option to use class GFX of library GFX_Root instead of Adafruit_GFX
- differential update on GDEW0154M10 is experimental, there is no partial update demo yet
#### Version 1.2.8
- improved transfer speed for the bigger displays (3.71" and up)
#### Version 1.2.7
- fix paged drawing of initial screen on GDEH029A1
- sometimes true is false, if applied the wrong way round
#### Version 1.2.6
- slightly improved differential refresh for GDEW1248T3
- minor fixes
#### Version 1.2.5
- added support for GDEW1248T3 12.84" b/w panel on Waveshare 12.48 e-paper display frame
- tested with Waveshare Epaper ESP32 Driver Board mounted on connection board
- tested with Arduino UNO mounted on connection board, is extremely slow
- doesn't work with Arduino MEGA on connection board with switch set to ICSP and pins bent out of way, reason unknown
- not tested with other processors
- caution: wiring connector is on 5V side of level converters!
#### Version 1.2.4
- added support for GDEH0154D67 1.54" b/w, replacement for GDEP015OC1
- added GxEPD2_SerialFlash_Loader, WiFi bitmap downloader for SPI-flash
- added GxEPD2_SerialFlash_Example, SPI-flash example, e.g. for Winbond 25Q16BVSIG
- minor fixes and comment cleanups
- fix refresh(false) in upper layer: add powerOff() after full refresh
#### Version 1.2.3
- fixed partial update for 2.13" 3-color and 2.9" 3-color e-paper
- partial update can be disabled with attribute usePartialUpdateWindow = false
- added GxEPD2_GFX_Example to show uses of GxEPD2_GFX base class
- replaced GxEPD2_MultiDisplayExample code, same code as GxEPD2_GFX_MultiDisplayExample
- added extras/examples/GxEPD2_T_MultiDisplayExample, alternate example using template functions
- major and minor fixes, such as typos that survived too long
#### Version 1.2.2
- fixed BMP handling, e.g. for BMPs created by ImageMagick
- see also Arduino Forum Topic https://forum.arduino.cc/index.php?topic=642343.0
#### Version 1.2.1
- added support for GDEW075T7 7.5" b/w 800x480
- GDEW075T7 has differential update (1.6s) using a charge balancing waveform
- added optional SW SPI support, see /extras/sw_spi/README
- added /extras/tests/GxEPD2_RefreshTests/GxEPD2_RefreshTests.ino, for waveform tuning
- minor fixes 
- note that 7.5" e-paper displays don't work reliable if fed from 3.3V Arduino pin
#### Version 1.2.0
- added "fast partial update" (differential update) for GDEW0371W7 3.7" b/w 240x416
- improved differential update waveform for GDEW026T0 2.6" b/w 152x256
- fixed init code & improved differential update for GDEW042T2 4.2" b/w 300x400
- note that all differential refresh waveforms are a compromise (ghosting, big font use)
- parameters for differential waveform for these display can easily be changed for experimenting
- GDEW042T2 would have greyed background without sustain phase
- GDEW042T2 needs multiple full refreshes after extended use of partial updates
#### Version 1.1.10
- added support for GDEH0213B73 2.13" b/w, replacement for GDE0213B1, GDEH0213B72
- added support for GDEW026T0 2.6" b/w 152x256
- added support for GDEW0371W7 3.7" b/w 240x416
- added support for GDEW075Z08 7.5" b/w/r 800x480
- GDEW075Z08 does allow (slow) partial update, set usePartialUpdate = false to disable for better image
- changed 4.2" b/w waveform table, for better result with actual panels
#### Version 1.1.9
- note for ESP8266 when using SS for CS: (wiring suggestion) 
- connect 4.7k pull-down from GPIO15 to GND if your board or shield has level converters
- fixes for large displays (use uint16_t for buffer index)
#### Version 1.1.8
- fix for incomplete download in GxEPD2_WiFi_Example
- added missing method displayWindow() to GxEPD2_GFX base class
- fix and clean up of initial refresh for panels with differential update
- initial refresh needs to be full update, not "fast partial update", for these panels,
- as the screen content may differ from the "previous buffer" content.
- add clean of controller buffer(s) on initial write to controller, for partial update.
#### Version 1.1.7
- enhanced support for full buffered, non-paged use, for processors with enough RAM
- use void display(bool partial_update_mode = false); corresponds to update() in  GxEPD
- use added void displayWindow(uint16_t x, uint16_t y, uint16_t w, uint16_t h);
- use added writeImagePart(...), drawImagePart(...), used by displayWindow()
- added example GxEPD2_NotPagedExample.ino
- several fixes, e.g. parameter range check in setPartialWindow()
#### Version 1.1.6
- added support for GDEH0213B72 2.13" b/w, replacement for GDE0213B1
- changed SPI speed for IT8951 Driver HAT to 24MHz for write, 10MHz for read
- minor fixes, e.g. centering of text bounding box in GxEPD2_Example
#### Version 1.1.5
- added support for 6" ED060SCT on Waveshare e-Paper IT8951 Driver HAT
- uses 3.3V data lines, but 5V supply (~80mA active, ~20mA stand-by, sleep doesn't work)
- note: 5V supply needs to be exact and strong; 5V over diode from USB (e.g. Wemos D1 mini) doesn't work!
- note that the IT8951 Driver HAT is panel specific, with flash parameterized by supplier
- this is an initial version
#### Version 1.1.4+
- added GxEPD2_WS_ESP32_Driver example for Waveshare ESP32 Driver Board
#### Version 1.1.4
- eliminated double refresh for "fast partial update"
- moved wavetables to the driver classes
- added one explicit drawImage(...) and writeImage(...) method (for removed default paramter values for 1.1.3)
- added init method with added parameter  initial, for re-init after processor deep sleep wakeup
- added init parameter pulldown_rst_mode, for special RST handling (not needed for waveshare shield)
#### Version 1.1.3
- fixed wavetables for GDEW029T5 and GDEW0213I5F
- fixed drawImage(...) overloaded methods signature matching ambiguity
#### Version 1.1.2
- added support for GDEW029T5
- fixed (added) clipping for partial window
- fixed (added) powerOff() after full update (partial update keeps power on)
- added hibernate() for minimum power use by displays that support it
#### Version 1.1.1
- 2.7" b/w GDEW027W3 with fast partial update support, based on new demo code wavetable
- mapping suggestion added for Arduino MEGA
- NOTE: use voltage divider resistors for 5V Arduinos, series resistor is not reliable enough
- ConnectingHardware.md updated
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

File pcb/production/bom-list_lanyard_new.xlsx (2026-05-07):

Id | Designator | Footprint | Quantity | Model | Value | Supplier and ref | Column1 | _1
1 | J8 | PinHeader_1x06_P2.54mm_Vertical | 1 |  | Conn_01x06_Pin
2 | PB3,PB5,PB2,PB1,PB4,PB6 | SW_Push_1TS009xxxx-xxxx-xxxx_6x6x5mm | 6 | TL9210AF180Q | SW_Push
3 | J3 | PinHeader_1x04_P2.54mm_Vertical | 1 |  | Conn_01x04_Pin
4 | R6,R3,R10,R13,R2,R15,R18,R16,R14,R17,R9 | R_0402_1005Metric | 11 | RC0402FR-0710KL | 10K
5 | C9,C6,C3,C16,C1,C11,C7,C15,C13,C12,C17,C14,C18,C19 | C_0402_1005Metric | 14 | CL05A105KP5NNNC | 1U
6 | R7,R22 | R_0402_1005Metric | 2 | 0402WGF1001TCE | 1K
7 | C23,C21,C10,C2,C35 | C_0402_1005Metric | 5 | CL05B104KO5NNNC | 100n
8 | C8,C4,C5 | C_0402_1005Metric | 3 | CL05A106MQ5NUNC | 10U
9 | ON/OFF_SW1 | SW_SPDT_PCM12 | 1 | SS-203-AGS7P-200 | SW_SPDT
10 | J2 | JST_GH_SM02B-GHS-TB_1x02-1MP_P1.25mm_Horizontal | 1 | S2B-PH-SM4-TB | Conn_01x02_Pin
11 | ON/OFF_PB1 | SW_SPST_EVQP7C | 1 | EVQP7C01P | SW_Push
12 | Q1,Q2,Q5 | SOT-23 | 3 | SS8050 | SS8050
13 | R1 | R_0402_1005Metric | 1 | 0402WGF2200TCE | 220
14 | J4 | Hirose_FH12A-24S-0.5SH_1x24-1MP_P0.50mm_Horizontal | 1 | FH12A-24S-0.5SH(55) | Conn_01x24_Socket
15 | RST1,BOOT1 | SW_SPST_B3U-1000P | 2 | HX-B3U-1000P-1.6N | SW_Push
16 | U4 | DFN-8-1EP_3x2mm_P0.5mm_EP1.7x1.4mm | 1 | MCP73831T-2ACI/MC | MCP73831-2-MC
17 | D4 | D_SOD-323 | 1 | BAT60A | BAT60A
18 | U1 | ESP32-S3-WROOM-1 | 1 | ESP32-S3-WROOM-1-N8R8 | ESP32-S3-WROOM-1
19 | U15 | SOIC-16_3.9x9.9mm_P1.27mm | 1 | CH340C | CH340C
20 | LD1 | LED_0402_1005Metric | 1 | RED | LED
21 | D6,D8,D7 | D_SOD-123 | 3 | MBR0540 | MBR0540
22 | L1 | L_APV_ANR4020 | 1 | FHD4020S-470MT | 47UH
23 | Q4 | Q_SOT-23 | 1 | AO3401A | AO3401A
24 | D1 | SOT-23-6_L2.9-W1.6-P0.95-LS2.8-BR | 1 | SRV05-4-P-T7 | SRV05-4-P-T7
25 | Q3 | SOT-23 | 1 | IRLML0030 | IRLML0030
26 | U16 | SOIC-8_3.9x4.9mm_P1.27mm | 1 | ATECC608B-SSHDA | ATECC608B-SSHDA
27 | R20 | R_0603_1608Metric | 1 | 0402WGF220KTCE | 2R2
28 | U10 | TSSOP-16_4.4x5mm_P0.65mm | 1 | TCA9534PWR | TCA9534
29 | C22,C20 | C_0402_1005Metric | 2 | CL05A225MQ5NSNC | 2U2
30 | R12,R11 | R_0402_1005Metric | 2 | 0402WGF2201TCE | 2K2
31 | R21,R23 | R_0402_1005Metric | 2 | 0402WGF2202TCE | 22K
32 | R4,R5 | R_0402_1005Metric | 2 | 0402WGF5101TCE | 5K1
33 | R8 | R_0402_1005Metric | 1 | 0402WGF5602TCE | 56K
34 | U5 | SOT-23-5 | 1 | ME6211C33M5G-N | ME6211C33M5
35 | J1 | USB_C_Receptacle_G-Switch_GT-USB-7010ASV | 1 | GT-USB-7010ASV | USB_C_Receptacle_USB2.0_16P
36 | J10 | PinHeader_1x10_P2.54mm_Vertical | 1 |  | Conn_01x10_Pin
37 | LCD |  | 1 | 2.7in | TWE0270NQ23-AO
38 | Battery |  | 1 | 50x30

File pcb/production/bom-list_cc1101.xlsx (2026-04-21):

Designator | Footprint | Quantity | Value | LCSC Part # | Model number | Manufacturer
C41, C43, C44 | 0402 | 3 | 100n |  | CL05B104KO5NNNC | SAMSUNG
C40, C42 | 0402 | 2 | 10U |  | CL05A106MQ5NUNC | SAMSUNG
C45, C46 | 0402 | 2 | 27p |  | CC0402FRNPO9BN270 | YAGEO
C48, C53 | 0402 | 2 | 220p |  | CC0402KRX7R9BB221 | YAGEO
C49, C50 | 0402 | 2 | 3.9p |  | CC0402CRNPO9BN3R9 | YAGEO
C51 | 0402 | 1 | 8.2p |  | 0402CG8R2C500NT | FH
C52 | 0402 | 1 | 5.6p |  | 0402CG5R6C500NT | FH
J11 | SMA_Amphenol_901-143_Horizontal | 1 | Conn_Coaxial_Small |  | 901-143 | Made in China
J12 | PinHeader_1x07_P2.54mm_Vertical | 1 | Conn_01x07_Pin |  | PZ254V-11-07P | XFCN | non soldered
L4 | 0402 | 1 | 22nH |  | LQG15HS22NJ02D | muRata
L5, L6, L7 | 0402 | 3 | 27nH |  | SDCL1005C27NJTDF | Sunlord
R29 | 0402 | 1 | 56K |  | 0402WGF5602TCE | UNI-ROYAL
U14 | SOT-23-5 | 1 | ME6211C33M5 |  | ME6211C33M5G-N | MICRONE(
U13 | QFN50P400X400X100-21N | 1 | CC1101RGP |  | CC1101RGPR | TI
Y2 | Crystal_SMD_3225-4Pin_3.2x2.5mm | 1 | 26Mhz |  | XL2EL89COI-111YLC-26M | YXC
Antenna |  | 1 | right angle antenna |  | 433mhz
 | pcb |  | FR-4 board, double-sided, 1.6mm thickness, green solder mask with white text, 1oz copper thickness, covered vias, lead-free spray tin
 | SMT Stenci

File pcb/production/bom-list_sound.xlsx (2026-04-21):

Designator | Footprint | Quantity | Value | LCSC Part # | Model number | Manufacturer
C24, C27, C28 | 0402 | 3 | 100n |  | CL05B104KO5NNNC | SAMSUNG
C25, C26, C30 | 0402 | 3 | 10U |  | CL05A106MQ5NUNC | SAMSUNG
C29 | 0402 | 1 | 22U |  | GRM155R60J226ME11D | muRata
J6 | PinHeader_1x06_P2.54mm_Vertical | 1 | Conn_01x07_Pin |  | PZ254V-11-07P | XFCN | non soldered
MK3 | InvenSense_ICS-43434-6_3.5x2.65mm | 1 | SPH0641LM4H-1 |  | SPH0641LM4H-1 | Knowles
R24 | 0402 | 1 | 1K |  | 0402WGF1001TCE | UNI-ROYAL
U6 | SOT-23-5 | 1 | ME6211C33M5 |  | ME6211C33M5G-N | MICRONE(
U7 | SOIC-8-1EP_3.9x4.9mm_P1.27mm_EP2.29x3mm | 1 | NS4168 |  | NS4168 | Nsiway
Speaker |  | 1 | 8ohm 1w |  | 1609
 | pcb |  | FR-4 board, double-sided, 1.6mm thickness, green solder mask with white text, 1oz copper thickness, covered vias, lead-free spray tin
 | SMT Stenci

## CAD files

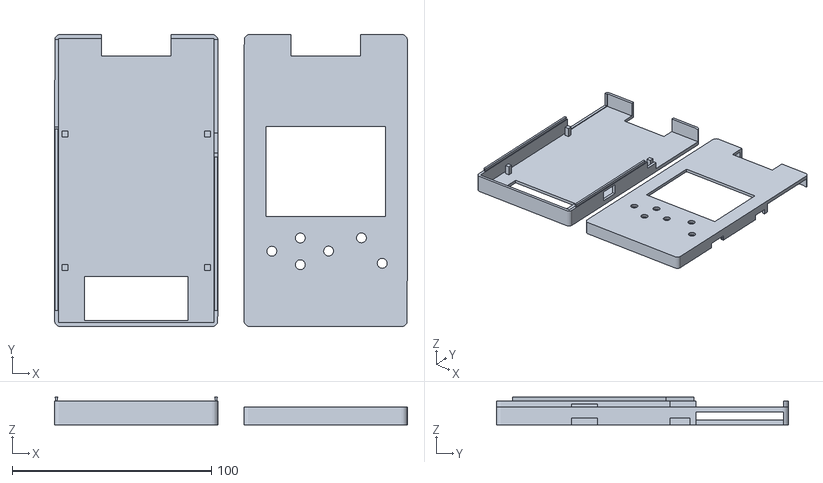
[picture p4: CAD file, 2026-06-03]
case/badge-v2.stl
177.0 x 146.5 x 14.0

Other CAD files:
case/badge-v2.skp
case/badge-v2~.skp

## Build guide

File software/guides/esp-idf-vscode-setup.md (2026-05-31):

# Setting Up VS Code + ESP-IDF to Build & Flash the Badge

This guide takes you from a fresh machine to flashing badge firmware over USB,
using **Visual Studio Code** and the official **ESP-IDF** extension. It applies
to every firmware project in this repo (`software/examples/…` and
`software/mods/…`).

> **At a glance**
> 1. Install VS Code + the **ESP-IDF** extension
> 2. Install the toolchain — **ESP-IDF v5.5.x** (⚠️ *not* 6.0 or newer)
> 3. Open a firmware **subfolder** (not the repo root)
> 4. Select your serial port → **Build → Flash → Monitor**

---

## ⚠️ Which version? ESP-IDF v5.5.x — not 6.0+

The firmware uses the Arduino core (GxEPD2 display library, etc.) compiled as an
ESP-IDF component. The Arduino core is **version-locked to the ESP-IDF it was
built against**:

| arduino-esp32 | requires ESP-IDF |
|---|---|
| **3.3.8** (used here) | **5.5.4** |
| 3.3.x | 5.5.x |

There is **no released Arduino core for ESP-IDF 6.0+**, so a 6.x toolchain will
fail to build this firmware. **Install ESP-IDF v5.5.4** (or the latest v5.5.x).
The Arduino core itself is downloaded automatically on the first build — you do
not install it separately.

---

## 1. Install VS Code and the ESP-IDF extension

1. Install [Visual Studio Code](https://code.visualstudio.com/).
2. Open the **Extensions** sidebar (`Cmd/Ctrl+Shift+X`), search for
   **`ESP-IDF`**, and install the one published by **Espressif Systems**
   (`espressif.esp-idf-extension`).

> **Drivers:** the badge talks to your computer through a **CH340** USB-serial
> chip. macOS 11+ and modern Linux include the driver; on Windows (or older
> macOS) install the [CH340 driver](https://www.wch-ic.com/products/CH340.html)
> if no serial port appears later. On Linux, add yourself to the `dialout`
> group so you can access the port without `sudo`:
> `sudo usermod -aG dialout $USER` (log out/in afterward).

---

## 2. Install the ESP-IDF toolchain (v5.5.x)

> **⚠️ macOS / Linux: install the QEMU runtime libraries *first*.** Before
> downloading v5.5.4, the installer checks for five QEMU dependency libraries.
> If even one is missing the whole install aborts — and on macOS the error is
> misleadingly shown as `Failed to check QEMU prerequisites: %{error}` (the real
> reason, e.g. *"libslirp not satisfied"*, is swallowed). Install all five up
> front so the check passes:
>
> **macOS (Homebrew):**
> ```bash
> brew install libgcrypt glib pixman sdl2 libslirp
> ```
>
> **Linux (Debian/Ubuntu):**
> ```bash
> sudo apt-get install -y libgcrypt20 libglib2.0-0 libpixman-1-0 libsdl2-2.0-0 libslirp0
> ```
>
> **Windows:** nothing to do — the installer handles its own dependencies.

1. Open the Command Palette (`Cmd/Ctrl+Shift+P`) → **`ESP-IDF: Configure ESP-IDF
   Extension`**.
2. Choose **EXPRESS** (the simplest path; it downloads ESP-IDF and all tools).
3. **Download server:** *GitHub* (or *Espressif* if GitHub is slow for you).
4. **ESP-IDF version:** select **`v5.5.4`** (or the newest `v5.5.x`).
   **Do not pick v6.0 or newer.**
5. Leave the install directories at their defaults
   (`~/.espressif` on macOS/Linux, `%USERPROFILE%\.espressif` on Windows).
6. Click **Install** and wait — it fetches the Xtensa toolchain and Python
   environment (a few minutes / ~1–2 GB). When it finishes you'll see
   *"All settings have been configured."*

> **Already have v5.5.x installed from the command line?** Choose **USE EXISTING
> SETUP** in the wizard instead and point it at your `…/esp-idf` folder
> (e.g. `~/.espressif/v5.5.4/esp-idf`).

---

## 3. Open a firmware project

> **Important:** open the **project subfolder**, *not* the repository root. The
> repo root has no `CMakeLists.txt`, so the extension will report
> *"CMakeLists.txt not found in project directory"* and target selection will
> fail. Each firmware app is its own ESP-IDF project.

**File → Open Folder…** and pick one of:

| Open this folder | Firmware |
|---|---|
| `software/examples/basic-menu-adjustable-homescreen/firmware` | Menu + adjustable homescreen |
| `software/mods/tamagotchi` | Virtual-pet mod |

Each project folder already contains `CMakeLists.txt`, `main/`,
`sdkconfig.defaults`, and `partitions.csv`.

### Target is preconfigured

The chip target (**ESP32-S3**), 8 MB flash, octal PSRAM (tamagotchi), and the
partition table are all set in `sdkconfig.defaults` — you **do not need to run
"Set Espressif device target."** If the extension ever prompts you, choose
**`esp32s3`**.

---

## 4. Connect the badge and select the serial port

1. Plug the badge into your computer with a **USB-C** cable and power it on.
2. Command Palette → **`ESP-IDF: Select port to use`** (or click the **plug**
   icon in the bottom status bar) and pick the badge's port:

   | OS | Looks like |
   |----|-----------|
   | macOS | `/dev/tty.usbserial-XXXX` (or `/dev/tty.wchusbserialXXXX`) |
   | Linux | `/dev/ttyUSB0` |
   | Windows | `COM3`, `COM4`, … |

   No port listed? Re-seat the cable (use a *data* cable, not charge-only) and
   confirm the CH340 driver is installed (see §1).

---

## 5. Build, Flash, and Monitor

All actions are on the **blue status bar** at the bottom of VS Code, and also in
the Command Palette. Left-to-right, the relevant status-bar icons are:

| Icon | Action | Command Palette equivalent |
|---|---|---|
| 🔌 plug | Select port | `ESP-IDF: Select port to use` |
| 🛠️ wrench/chip | Set target | `ESP-IDF: Set Espressif device target` |
| ⚙️ gear | SDK config editor (menuconfig) | `ESP-IDF: SDK Configuration Editor` |
| 🛢️ cylinder | **Build** | `ESP-IDF: Build your project` |
| ⚡ bolt | **Flash** | `ESP-IDF: Flash your project` |
| 🖥️ monitor | **Monitor** (serial output) | `ESP-IDF: Monitor your device` |
| 🔥 flame | **Build + Flash + Monitor** (do everything) | `ESP-IDF: Build, Flash and start a monitor` |

**Recommended first run:**

1. Click **Build** (🛢️). The **first build downloads the Arduino core**
   (`arduino-esp32`) and compiles it — this takes several minutes and a lot of
   output. Later builds are incremental and fast.
2. Make sure the **flash method** is **UART** (status-bar item; this badge
   flashes over the CH340 UART).
3. Click **Build, Flash and Monitor** (🔥). On success the badge reboots into
   the new firmware and the serial monitor shows its output.
   - *Exit the monitor* with `Ctrl+]`.

> **Auto-reset:** the badge's CH340 + DTR/RTS circuit puts the ESP32-S3 into
> download mode for you — you normally don't touch any buttons. If flashing
> can't connect, force download mode: **hold BOOT, tap RST, release BOOT**, then
> flash again.

---

## Command-line alternative

Prefer a terminal? Open the **ESP-IDF Terminal** (Command Palette →
`ESP-IDF: Open ESP-IDF Terminal`), which has the environment pre-loaded. Or load
it manually in any shell:

```bash
. $IDF_PATH/export.sh          # or run the alias the installer prints
cd software/mods/tamagotchi    # a project subfolder
idf.py build
idf.py -p /dev/tty.usbserial-10 flash monitor   # use your port
```

---

## Troubleshooting

| Symptom | Cause / Fix |
|---|---|
| **`Failed to check QEMU prerequisites: %{error}`** during v5.5.4 install (macOS/Linux) | A QEMU runtime lib is missing (often `libslirp`); `%{error}` hides the real one. Install all five prereqs (§2), then **Try Again**. |
| **`CMakeLists.txt not found in project directory`** / *Set target fails with exit code 2* | You opened the **repo root**. Open a firmware **subfolder** instead (§3). |
| Build fails with errors about **removed drivers** / Arduino core won't resolve | Wrong ESP-IDF version. You **must** use **v5.5.x**, not 6.0+ (see top). |
| First build hangs at "Solving dependencies" / downloading | It's fetching the Arduino core from the component registry. Needs internet; just wait. |
| No serial port in the list | Bad/charge-only cable, or missing **CH340 driver** (§1). Linux: join `dialout`. |
| `Failed to connect … No serial data received` while flashing | Force download mode: hold **BOOT**, tap **RST**, release **BOOT**, flash again. |
| PSRAM not detected (tamagotchi) | Already configured for **Octal (OPI)** mode in `sdkconfig.defaults`; ensure you didn't override it in the SDK config editor. |

---

*Once flashed, head back to the firmware's own README for what the app does and
how to use it.*

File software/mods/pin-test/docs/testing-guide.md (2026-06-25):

# Testing Guide — Verifying Solder Joints From Zero

This walks through the entire process used to verify hand-soldered header
pins on the OnionDAO Badge, written for someone who had never touched a
multimeter before. If you already know your way around a DMM, skip to
[Continuity test](#2-continuity-test-power-off) or
[GPIO toggle test](#3-powered-gpio-toggle-test).

## 0. Why test before wiring up modules

If you solder header pins to a board and then immediately wire jumpers to
a plug-in module, a bad joint (cold joint, solder bridge, missing
connection) shows up as a confusing module malfunction with no obvious
cause. Testing the bare board first isolates "is my soldering good" from
"does my module work" — two completely different failure domains.

## 1. Multimeter basics

**Parts of the meter:**
- **Screen** — shows the number.
- **Dial** — selects what you're measuring. Look for:
  - **Continuity mode** — a diode/sound-wave icon, beeps when connected.
    On meters with a shared dial position for resistance/continuity/diode
    (e.g. AstroAI AM33D), a yellow **SELECT** button cycles between them —
    press it until the screen shows the continuity icon, then confirm by
    touching the two probes together: you should hear a beep and see ~0.
  - **DC voltage (DCV)** — a `V` with a straight line (as opposed to `V`
    with a wavy line, which is AC). Auto-ranging meters need no further
    setup; manual-range meters need a range above 3.3V (e.g. "20V").
- **Probes** — black plugs into `COM`. Red plugs into `VΩ` (ignore any
  separate high-current `10A` jack — never needed for this).

**Taking a reading:** touch black probe to your reference point (usually
GND), red probe to the thing you're testing, read the screen (or listen
for the beep in continuity mode). That's the entire skill — everything
below is just "which two points, in which mode."

## 2. Continuity test (power OFF)

Unplug USB and any battery before this section — continuity testing
should always be done unpowered.

**Step 1 — visual check.** Magnifier + raking light. Look for solder
bridges between adjacent pins (the most common defect on small headers),
dull/cracked cold joints, and pins sitting crooked.

**Step 2 — GND-to-GND (expect a beep).** Touch black probe to one GND
pin, red probe to another GND pin (different header is fine — it's all
one ground plane). A beep confirms that joint has real continuity through
the board, not just looking soldered.

**Step 3 — adjacent-pin sweep (expect NO beep).** This is the one that
actually catches bridges. Walk down every header, checking each
*physically neighboring* pair of pins:

```
pin1 vs pin2, pin2 vs pin3, pin3 vs pin4, ... 
```

Any beep between two pins that shouldn't be connected means a solder
bridge — touch it up with the iron (don't just add more solder) and
re-test.

**Step 4 — repeat for every header** you soldered. On this project that
was 4 headers: the two side expansion ports (`J8`, `J10`) on the main
board, and the two module connectors (CC1101, Sound) on their own boards.

If you also have a VCC rail on the header, check it the same way — VCC
should NOT beep to GND or to neighboring signal pins, but two VCC pins on
the same header (e.g. both ends of a 10-pin header) SHOULD beep to each
other, confirming they're the same rail.

## 3. Powered GPIO toggle test

Continuity alone can miss a *cracked* joint that happens to still touch at
rest but opens under any flex. The fix: make the chip actually drive each
pin and watch it swing.

Flash the firmware in [`../firmware`](../firmware) (see the main
[README](../README.md) for build steps), then:

1. Multimeter on DC volts, black probe on any GND pin.
2. Open Serial Monitor (115200 baud) to see which pin is currently being
   driven.
3. Touch the red probe to that pin's solder joint.
4. Expect the reading to swing **0V → ~3.3V → 0V**, three times, in step
   with the printout.

A pin stuck at 0V, stuck at 3.3V, or not moving at all = bad joint, wrong
pin, or wrong wiring variant. A small flickering reading (e.g. 0.1–0.2V)
*after* a pin has been released back to floating/input is normal noise,
not a defect — floating pins always pick up tiny ambient noise.

## 4. Automated functional checks (after wiring up jumpers)

Once the bare board's GPIOs pass, wire the jumpers to your plug-in
modules and re-flash. The same firmware now runs two stronger,
fully-automated tests:

- **CC1101 link check** — reads the chip's `PARTNUM`/`VERSION` registers
  over real SPI, then forces a known clock frequency onto `GDO0` and
  measures it. A frequency match (within a few percent — software polling
  always undercounts a little) is a far stronger proof than continuity
  alone, because it requires the *entire* path (jumpers + solder + the
  actual silicon) to work correctly.
- **Sound module tone-out** — plays a tone over I2S. No chip ID exists to
  read back on a dumb amp/mic pair, so your ears are the test instrument
  here. Hearing a clean steady tone = pass.

Both results are also drawn to the badge's e-paper screen, so you don't
need to keep the Serial Monitor open.

## 5. Common pitfalls hit during this process

- **Re-initializing a peripheral (SPI/I2S) on every loop iteration**
  eventually starves a shared DMA/interrupt resource and hangs the next
  transfer, tripping the watchdog. Initialize once in `setup()`, reuse the
  handle.
- **I2S hardware keeps repeating its last DMA buffer** once you stop
  feeding it new data, instead of going silent — explicitly call
  `i2s_channel_disable()` when you're done playing audio.
- **A multimeter's continuity mode shows noisy fluctuating digits (not a
  beep) on an open/disconnected probe** — that's normal floating-pin
  noise, not a fault. No beep is the pass condition; ignore the wiggling
  number.
- **`VERSION=0x00` from a CC1101** is a known-normal reading on many real
  and clone chips — don't treat it alone as a failure. The frequency-match
  result on `GDO0` is the decisive test.
- **VCC on a module connector reads 0V even when wiring is correct** if
  it's fed from a switched/gated power rail (this badge gates peripheral
  power through a GPIO-controlled transistor) — 0V before firmware
  asserts that GPIO is expected, not a fault.

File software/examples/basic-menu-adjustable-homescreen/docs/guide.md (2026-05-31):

# Beginner's Guide — Hardware and C for the OnionDAO Badge

This guide explains what is actually happening when you build and run firmware
on the badge. No prior hardware or C experience assumed.

---

## 1. What Is a Microcontroller?

Your laptop runs an operating system (Linux), which manages memory, files,
networking, and hundreds of processes at once. It has gigabytes of RAM and a
CPU designed for general-purpose computing.

A **microcontroller** (MCU) is a completely different animal. It is a single
chip that contains a CPU, a small amount of RAM, and flash storage — all
integrated together, with no operating system. The ESP32-S3 on your badge has:

- **CPU:** two cores running at up to 240 MHz
- **RAM:** 512 KB on-chip + 8 MB external PSRAM
- **Flash:** 8 MB for storing your program
- **Peripherals:** SPI, I²C, UART, PWM, ADC — all built into the same chip

When the badge powers on, the CPU starts executing your program immediately
from address 0 in flash. There is no boot menu, no file system to load, no
kernel — just your code running directly on the hardware.

### Why C/C++ instead of Python?

MicroPython (which this badge started with) does run Python on the MCU, but
it has overhead: an interpreter, a garbage collector, and slower execution.

C and C++ compile directly to machine instructions. The resulting binary is
smaller, runs faster, and gives you precise control over every hardware
register. For a badge that needs to drive an e-paper display with specific
timing, talk to multiple SPI/I²C devices, and respond instantly to button
presses, C is the natural choice.

Arduino is not a language — it is a framework written in C++ that hides a lot
of the chip-specific setup (clock configuration, interrupt tables, peripheral
initialization) so you can focus on your application logic. The functions
`setup()` and `loop()` are Arduino conventions; the compiler wraps them in a
standard `main()` that the chip actually executes.

---

## 2. GPIO — General Purpose Input/Output

Every pin on the ESP32-S3 that isn't dedicated to power is a **GPIO pin**.
You control a GPIO pin entirely in software:

```cpp
// Set GPIO18 as an output, then drive it HIGH (3.3 V)
pinMode(18, OUTPUT);
digitalWrite(18, HIGH);

// Set GPIO21 as an input, then read its voltage
pinMode(21, INPUT);
int level = digitalRead(21);  // returns 0 or 1
```

On your badge, GPIO18 controls a transistor (Q5) that switches power to the
display and I²C devices. Before touching any peripheral, you must set GPIO18
HIGH — otherwise those circuits have no power and nothing responds.

### Voltage levels

The ESP32-S3 is a **3.3 V device**. HIGH = 3.3 V, LOW = 0 V. This is
important: connecting a 5 V signal directly to an ESP32 pin will damage it.
The CH340C USB chip on the badge handles the level translation between your
laptop's USB (5 V) and the ESP32 (3.3 V).

---

## 3. Communication Protocols — How Chips Talk to Each Other

A microcontroller rarely works alone. It needs to talk to sensors, displays,
and other ICs. Two protocols handle almost all of this on your badge: SPI and
I²C.

### SPI — Serial Peripheral Interface

SPI is fast. It uses four wires:

| Wire | Direction | Purpose |
|---|---|---|
| SCK | MCU → device | Clock — a square wave that times every bit |
| MOSI | MCU → device | Master Out Slave In — data going to the device |
| MISO | device → MCU | Master In Slave Out — data coming back (not used by display) |
| CS | MCU → device | Chip Select — pulled LOW to address this specific device |

Data is transferred one bit per clock pulse. At 4 MHz (the badge's SPI
speed), you can transfer 4 million bits per second. The 5808-byte display
image transfers in about 12 milliseconds.

The e-paper display uses SPI with an extra wire: **DC** (Data/Command).
When DC is LOW, the MCU is sending a command (an instruction like "start
a refresh"). When DC is HIGH, the MCU is sending data (pixel values).
The display controller uses this to know how to interpret each byte.

```
Sending the "write RAM" command (0x24), then pixel data:

CS  ────┐                         ┌────
        │_________________________│
DC  ────┐   ┌────────────────────────
        │___│
MOSI ═══╪═══╪════════════════════════
        0x24  0xFF 0xFF 0x00 0xFF ...
             (pixel data bytes)
```

### I²C — Inter-Integrated Circuit

I²C is slower than SPI but uses only **two wires** for potentially dozens of
devices:

| Wire | Purpose |
|---|---|
| SCL | Clock |
| SDA | Data (bidirectional) |

Every device on I²C has a 7-bit **address** baked into its silicon. The MCU
calls out an address at the start of every transaction, and only the device
with that address responds. Your badge has two I²C devices:

- **TCA9534** — 8-bit I/O expander for the 6 buttons, address `0x20`
- **ATECC608B** — cryptographic secure element, address `0x60`

```cpp
// Read one byte from the TCA9534 input register (register 0x00)
Wire.beginTransmission(0x20);   // address the TCA9534
Wire.write(0x00);               // tell it we want register 0x00
Wire.endTransmission();
Wire.requestFrom(0x20, 1);      // ask for 1 byte back
uint8_t buttons = Wire.read();  // that byte has one bit per button
```

The reason I²C runs at 100 kHz instead of the possible 400 kHz is the
ATECC608B — it requires the slower speed during its startup sequence.

---

## 4. How the Buttons Work

The six buttons (PB1–PB6) are not wired directly to GPIO pins. Instead they
connect to the TCA9534 I/O expander. This is common in hardware design to
save GPIO pins — one I²C device handles all six buttons using just SCL and
SDA.

Each button connects one TCA9534 pin to ground. The TCA9534 has internal
pull-up resistors that hold each pin at HIGH (1) when no button is pressed.
When you press a button, it pulls the pin to LOW (0).

This is called **active LOW**: the signal that means "button pressed" is a 0,
not a 1. The firmware inverts this:

```cpp
uint8_t raw = Wire.read();          // e.g. 0b11111011 = button 3 pressed
return (~raw) & 0x3F;               // invert + mask to 6 bits
                                    // result: 0b00000100 = bit 2 set = PB3
```

`~raw` flips all bits (1→0, 0→1). `& 0x3F` masks off the top two bits
since we only have 6 buttons. The result is a bitmask where a **1** means
"this button is pressed."

---

## 5. How E-Paper Displays Work

An e-paper (electronic paper) display is fundamentally different from an LCD
or OLED screen.

**LCD/OLED:** requires constant power to maintain the image. Turn off power,
image disappears immediately.

**E-paper:** tiny capsules of electrically charged black and white particles
are embedded in the display. An electric field pushes particles to the front
or back of each cell. Once positioned, the particles stay there with **zero
power**. The image persists indefinitely without electricity.

This is why your badge display kept showing its old image even after you
switched from MicroPython to Arduino — the physical particles were still in
position.

### The refresh process

Refreshing an e-paper display is slow (~1.5 seconds) and involves several
steps:

1. **Power on** the display's internal voltage booster
2. **Write pixel data** to the controller's RAM (the SSD1680 chip)
3. **Trigger a refresh** — the controller drives high-voltage waveforms through
   every row and column to move the particles
4. **Wait for BUSY** — GPIO21 stays HIGH while the refresh is happening;
   the firmware must wait until it goes LOW before sending more commands
5. **Power off** the voltage booster
6. **Hibernate** — the controller enters deep sleep, drawing microamps

The BUSY pin is critical. The SSD1680 is physically moving charged particles
through a viscous medium. If you send another command before it finishes,
you corrupt the display state and it may show garbage or nothing.

```cpp
// GxEPD2 handles all of this internally, but this is the concept:
display.firstPage();
do {
    display.fillScreen(GxEPD_WHITE);     // fill internal page buffer
    display.print("Hello");              // draw into buffer
} while (display.nextPage());            // triggers refresh, waits for BUSY
display.hibernate();                     // sleep
```

### Why 1 bit per pixel?

E-paper displays are black and white — each pixel is either fully black or
fully white (unlike a grey LCD). So each pixel needs only **1 bit** of
storage: 0 or 1. For a 264×176 display:

```
264 × 176 = 46,464 pixels
46,464 ÷ 8 = 5,808 bytes
```

5808 bytes is the exact size of the image the art tool sends. Each byte holds
8 pixels, packed MSB (most significant bit) first — the leftmost pixel is
stored in bit 7 of each byte.

---

## 6. C Fundamentals for This Firmware

### Variables and types

C requires you to declare the exact type of every variable. The types you
see most in embedded code:

```cpp
uint8_t   // unsigned 8-bit integer:  0 to 255
uint16_t  // unsigned 16-bit integer: 0 to 65535
uint32_t  // unsigned 32-bit integer: 0 to 4,294,967,295
int       // signed integer (size depends on platform, usually 32-bit)
bool      // true or false
```

The `uint` prefix means unsigned (no negative numbers). The number is the bit
width. On an MCU, you often care about exact sizes because you are mapping
values directly to hardware registers that are a specific number of bits wide.

### Pointers and arrays

A **pointer** is a variable that holds a memory address. In embedded code,
pointers let you pass large buffers around without copying them, and let you
work directly with hardware memory addresses.

```cpp
uint8_t img_buf[5808];          // array of 5808 bytes in RAM

// display.drawBitmap expects a pointer to the first byte
display.drawBitmap(0, 0, img_buf, 264, 176, GxEPD_BLACK, GxEPD_WHITE);
//                          ^^^^^
//                          img_buf decays to a pointer to its first element
```

When you write `img_buf` without brackets, C automatically treats it as a
pointer to the first element. This is called "array decay."

### Bit manipulation

The badge firmware uses bit operations constantly because hardware registers
are controlled bit by bit.

```cpp
uint8_t raw = 0b11111011;   // TCA9534 reading: button 3 pressed (bit 2 = 0)

// Test if bit 2 is set:
if (raw & (1 << 2)) { ... }     // (1 << 2) = 0b00000100

// Invert all bits:
uint8_t inverted = ~raw;        // 0b00000100 — now 1 means "pressed"

// Mask to the lower 6 bits:
uint8_t result = inverted & 0x3F;   // 0x3F = 0b00111111
```

`<<` shifts bits left. `1 << 2` shifts the value 1 two positions left,
producing a mask with only bit 2 set. `&` (AND) tests bits. `|` (OR) sets
bits. `~` inverts all bits.

### Static variables

In the firmware, `check_serial_image()` uses a `static` local variable:

```cpp
void check_serial_image() {
    static uint8_t hdr[4] = {0};
    ...
}
```

A normal local variable is destroyed when the function returns. A `static`
local variable persists between calls — the array keeps its value from one
call to the next. This is how the function remembers the last few bytes it
saw, so it can detect the `IMG:` magic header across multiple loop iterations.

### `#define` constants

```cpp
#define IMG_SIZE (264 * 176 / 8)   // 5808
```

`#define` is a **preprocessor directive** — before compilation, the
preprocessor replaces every occurrence of `IMG_SIZE` in the source with the
literal text `(264 * 176 / 8)`. The compiler then evaluates this as a
constant expression. No memory is used; it is purely a compile-time
substitution.

### NVS — Non-Volatile Storage

Flash memory is fast to read but designed to be written in large blocks (sectors
of 4096 bytes). Writing arbitrary key-value data directly to flash is tricky
and would wear out sectors quickly. ESP32 solves this with **NVS** (Non-Volatile
Storage): a driver that manages wear-levelling, atomic writes, and a simple
key-value API.

The Arduino wrapper is `Preferences`:

```cpp
#include <Preferences.h>

Preferences prefs;
prefs.begin("badge", false);              // open namespace "badge", read-write
prefs.putBytes("homescreen", buf, 5808);  // store 5808 bytes under key "homescreen"
prefs.end();

prefs.begin("badge", true);              // open read-only
size_t len = prefs.getBytesLength("homescreen");
prefs.getBytes("homescreen", buf, len);
prefs.end();
```

The badge uses NVS to persist the custom home screen image across power cycles.
The NVS partition lives in a dedicated area of flash and survives firmware
uploads (it is not erased by `idf.py flash`).

---

## 7. The Arduino Execution Model

Arduino firmware has two required functions:

```cpp
void setup() {
    // Runs once, at power-on or after reset.
    // Initialize everything here.
}

void loop() {
    // Runs repeatedly, forever, after setup() finishes.
    // This is your main program.
}
```

Under the hood, the Arduino framework generates a `main()` function that
looks like this:

```cpp
int main() {
    initArduino();    // chip-level setup (clocks, interrupts, etc.)
    setup();          // your setup
    while (true) {
        loop();       // your loop, called over and over
    }
}
```

There is no scheduler, no sleep between calls — `loop()` is called as fast as
the CPU can execute it. If `loop()` takes 2 seconds (e.g., waiting for a
display refresh), nothing else runs during those 2 seconds. This is called
**cooperative / bare-metal** execution, as opposed to an RTOS (real-time
operating system) where multiple tasks can run concurrently.

### Implications for the badge

In `loop()`, `check_serial_image()` runs first. When it receives an image,
it calls `display.firstPage()` / `nextPage()` which blocks for ~1.5 seconds.
During that time, `read_buttons()` does not run — button presses during a
display refresh are missed. For a badge application this is acceptable, but
in a more complex system you would use an RTOS or interrupts to handle this.

---

## 8. Libraries and Abstraction

Writing a display driver from scratch means reading a 100-page datasheet,
implementing every SPI command sequence, and getting the timing exactly right.
Libraries save this work.

**GxEPD2** is a C++ library written for Arduino that implements drivers for
dozens of e-paper panels. When you write:

```cpp
#include <GxEPD2_BW.h>
#include <gdey/GxEPD2_270_GDEY027T91.h>

GxEPD2_BW<GxEPD2_270_GDEY027T91, GxEPD2_270_GDEY027T91::HEIGHT> display(
    GxEPD2_270_GDEY027T91(PIN_EPD_CS, PIN_EPD_DC, PIN_EPD_RST, PIN_EPD_BUSY)
);
```

You are declaring a `display` object backed by the `GxEPD2_270_GDEY027T91`
driver. The `<...>` is C++ **template** syntax — it tells the compiler to
specialize the `GxEPD2_BW` class for this specific panel type, so the
internal page buffer is sized correctly at compile time without any runtime
overhead.

**Adafruit GFX** is the drawing layer. GxEPD2 inherits from it, giving you:

```cpp
display.fillScreen(GxEPD_WHITE);       // fill background
display.setFont(&FreeMonoBold9pt7b);   // choose a font
display.setCursor(8, 22);              // move text cursor (x, y in pixels)
display.print("ONIONDAO BADGE");      // draw text
display.drawFastHLine(0, 30, 264, GxEPD_BLACK);  // horizontal line
display.drawBitmap(0, 0, data, 264, 176, GxEPD_BLACK, GxEPD_WHITE);
```

These functions transform your drawing commands into SPI transfers to the
SSD1680's RAM, handling the rotation transform, page boundaries, and bit
packing internally.

---

## 9. What Happens When You Flash

`idf.py flash` does the following:

1. **Compiles** all `.cpp` files in `main/` and the libraries into object
   files (`.o`), then **links** them into a single ELF binary
2. **Packages** the binary into an ESP32 flash image (adding bootloader,
   partition table, and app segments at their correct flash addresses)
3. **Runs esptool** which connects to the CH340C over `/dev/ttyUSB0`,
   resets the ESP32 into download mode via the DTR/RTS pins, erases the
   relevant flash sectors, and writes the new image
4. **Hard resets** the ESP32 via RTS, which causes it to boot and run
   your new firmware

The partition table tells the bootloader where in flash your app lives.
The default 8 MB layout leaves room for OTA (over-the-air) updates,
non-volatile storage (NVS), and the app itself:

```
0x000000  Bootloader    (16 KB)
0x008000  Partition table
0x00E000  OTA data
0x010000  App partition  ← your firmware goes here
```

---

## 10. Where to Go Next

The current firmware already has several of these in place. Items marked ✓
are done; the rest are natural extensions.

**✓ Button-driven UI** — seven-item menu with UP/DOWN/SELECT/CANCEL navigation,
six sub-screens (system info, button test, I²C scanner, RNG, display test), and
pageable Hardware/Software guide lessons.

**✓ Deep sleep** — the badge enters deep sleep (< 10 µA) after 60 seconds of
inactivity, waking on a button press via GPIO1 edge wakeup. The e-paper holds
its image without power.

**✓ NVS — persistent custom home screen** — the art tool sends a 5808-byte
1-bit bitmap over serial; the badge saves it to flash using the ESP32
`Preferences` library. The image survives power cycles and deep sleep.

**Interrupt-driven buttons** — instead of polling TCA9534 every loop, wire
GPIO1 (the IRQ line) to an interrupt handler that fires only when a button
is pressed. This saves power and improves response time during display refreshes.

**CC1101 radio** — a CC1101 sub-GHz radio module attaches via the bottom
module connector on the front face, stacking on top of the badge. It operates
at 433.92 MHz. You can transmit and receive short packets between badges.

**Custom fonts** — Adafruit GFX supports fonts generated by
[fontconvert](https://github.com/adafruit/Adafruit-GFX-Library/tree/master/fontconvert).
You can convert any TTF font to a C header and use it with `setFont()`.

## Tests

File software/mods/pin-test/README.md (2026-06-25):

# Pin Test

Firmware mod for verifying hand-soldered header pins on the badge
**before** wiring up plug-in modules with jumper wires. Built out of a
real soldering session — see [`docs/testing-guide.md`](docs/testing-guide.md)
for a from-scratch multimeter walkthrough.

## 1. Functionality

On boot, the firmware runs three checks once, then goes idle:

1. **GPIO toggle pass** — cycles every signal pin on the two side
   expansion ports (`J8` left, `J10` right), driving each HIGH/LOW 3x so
   you can confirm the solder joint with a multimeter (DC volts, pin to
   GND — expect a clean 0V↔3.3V swing).
2. **CC1101 link check** — talks real SPI to a CC1101 sub-GHz radio
   module on `J8`, reads back its `PARTNUM`/`VERSION` ID registers, then
   forces a free-running test clock onto `GDO0` and measures its
   frequency. A match against the expected ~135.4 kHz (`crystal/192`)
   proves the entire path — solder joints, jumper wires, and the chip
   itself — end to end. No multimeter needed for this part.
3. **Sound module tone-out** — drives a Sound module (NS4168 amp +
   SPH0641 mic) on `J10` over I2S and plays a 3-second 440 Hz tone. No ID
   register exists on a dumb amp/mic pair, so hearing the tone is the
   pass condition.

Each phase's result is also drawn to the badge's e-paper display, so a
Serial Monitor isn't required to read results.

A simpler Arduino-IDE-only sketch ([`arduino/pin_test.ino`](arduino/pin_test.ino))
covers just the GPIO toggle test, with no display/CC1101/Sound checks —
useful before you know your module wiring variant, since it covers the
union of pins across all three wiring variants (L1/L2/R).

## 2. Module compatibility

- **CC1101** — yes, tested (SPI link + GDO0 clock check)
- **Sound (NS4168/SPH0641)** — yes, tested (I2S tone-out)
- Works with **no modules attached** too — the GPIO toggle pass needs
  only the bare board.

## 3. GPIO usage

| Pinout label | Used as |
|---|---|
| G48 | CC1101 SDI (J8) |
| G47 | CC1101 SCK (J8) |
| G19 | CC1101 SCS (J8) |
| G42 | CC1101 SDO (J8) |
| G41 | CC1101 GDO0 (J8) |
| G40 | J8 spare |
| G38 | Sound SDI (J10) |
| G39 | Sound SCK (J10) |
| G16 | Sound SLR/WS (J10) |
| G15 | Sound SDO (J10) |
| G07 | Sound CTR/CTRL (J10) |
| G06, G05, G04 | J10 spares |
| G18 | Module power rail enable (asserted HIGH in `setup()`) |
| G11, G12, G13, G14, G17, G21 | On-board e-paper SCK/CS/DC/RST/MOSI/BUSY (not part of the toggle test) |

All names match `docs/PINOUT.md`. If your wiring differs, edit the pin
constants at the top of `firmware/main/main.cpp` (or `arduino/pin_test.ino`).

**BOOT pin / power-management conventions followed:**
- No GPIO0 (BOOT) usage in this mod.
- GPIO18 is asserted HIGH during `setup()` to power the module rail,
  matching the documented convention; this mod doesn't implement deep
  sleep, so there's no corresponding drop.

## 4. Build & flash

Requires ESP-IDF **v5.5.x** (pins `arduino-esp32` v3.3.8, built against
v5.5.4 — keep these in lockstep).

```sh
cd firmware
idf.py set-target esp32s3
idf.py build
idf.py -p <PORT> flash monitor
```

First build fetches `arduino-esp32` from the ESP Component Registry
automatically. `GxEPD2`, `Adafruit_GFX`, and `Adafruit_BusIO` are
vendored locally under `components/` so this mod builds standalone.

**Arduino IDE alternative:** open [`arduino/pin_test.ino`](arduino/pin_test.ino),
board "ESP32S3 Dev Module", 115200 baud Serial Monitor. GPIO-toggle-only,
no extra dependencies.

## 5. Visual evidence

The e-paper display shows a live `PIN TEST` status screen at each phase
(toggle pass complete, CC1101 PARTNUM/VERSION + GDO0 Hz + PASS/FAIL, sound
tone played) — see [`docs/testing-guide.md`](docs/testing-guide.md) for
what a passing vs. failing reading looks like on both the display and a
multimeter.

## Continuity testing (before powering anything on)

The GPIO toggle test only catches problems once the board is powered. Do
a cold continuity sweep with a multimeter first — full procedure in
[`docs/testing-guide.md`](docs/testing-guide.md).

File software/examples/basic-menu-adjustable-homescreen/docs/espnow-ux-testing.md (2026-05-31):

# ESPNow UX Testing Guide — Two Badges

This document walks through every ESPNow feature with two badges and describes
exactly what you should see at each step. Use it to confirm a build is working
correctly before shipping or merging.

---

## Setup

- Two badges flashed with the same firmware
- Both powered on (USB or LiPo)
- Both showing the home screen or menu
- Badges placed within 1–2 metres of each other for initial testing

---

## 1. Entering ESPNow

**On both badges:**
1. Press any button from the home screen to open the menu
2. Navigate to **8. ESPNow Beacon** and press SELECT

**Expected:**
- Screen refreshes (~1.5s) and shows the BEACON tab
- The top line reads `Me: NCB-XXXXXX` where `XXXXXX` is the last 3 bytes of that badge's MAC address in hex
- The two badges show **different** callsigns — this confirms hardware-derived identity is working
- Below the callsign, the full MAC address is displayed (e.g. `34:CD:B0:0E:12:4C`)
- `Sent: 0    Peers: 0` is shown — no activity yet

---

## 2. Tab Navigation

**On either badge:**
1. Press RIGHT — screen switches to PEERS tab
2. Press RIGHT again — screen switches to INBOX tab
3. Press LEFT — returns to PEERS, then LEFT again to BEACON

**Expected:**
- The active tab label at the top is shown with a filled (inverted) background
- Inactive tabs have an outlined box
- PEERS shows "No peers seen yet."
- INBOX shows "No messages yet."
- Navigation is instant on button press (triggers a full e-paper refresh, ~1.5s)

---

## 3. Sending a Beacon

**On Badge A:**
1. Make sure you are on the BEACON tab
2. Press SELECT

**Expected on Badge A:**
- `Sent:` count increments by 1
- Serial monitor (if connected) prints: `[espnow] sent beacon #1 as NCB-XXXXXX`

**Expected on Badge B:**
- Switch to the PEERS tab — Badge A's callsign appears in the list with an RSSI bar and proximity tier
- Switch to the INBOX tab — a new entry appears: `From: NCB-XXXXXX #1` with `[beacon]` as the message
- Back on the BEACON tab, `Peers: 1` is now shown and "Last recv:" shows Badge A's name and MAC

**Repeat from Badge B:**
- Press SELECT on Badge B — Badge B's callsign now appears in Badge A's PEERS tab
- Both badges should show `Peers: 1` and see each other in INBOX

---

## 4. RSSI Proximity

**Prerequisites:** Both badges have exchanged at least one beacon (Peers list is populated)

**Test A — Close range:**
1. Hold both badges 2–3 cm apart
2. Press SELECT on either badge to send a beacon
3. Switch to the PEERS tab on the receiving badge

**Expected:**
- RSSI reading: approximately **−30 to −45 dBm**
- Signal bar: **6–8 blocks** filled
- Tier label: **CLOSE**

**Test B — Mid range:**
1. Place badges ~3 metres apart
2. Send a beacon and check PEERS tab

**Expected:**
- RSSI reading: approximately **−55 to −65 dBm**
- Signal bar: **3–5 blocks** filled
- Tier label: **NEAR**

**Test C — Far range:**
1. Place badges at opposite ends of a room (10+ metres)
2. Send a beacon and check PEERS tab

**Expected:**
- RSSI reading: approximately **−70 to −85 dBm**
- Signal bar: **0–2 blocks** filled
- Tier label: **FAR**

> **Note:** RSSI only refreshes when a new beacon is received. After moving
> the badges, press SELECT to send a fresh beacon before reading the new value.
> The reading will not change on its own between sends.

---

## 5. Callsign Editor

**On Badge A:**
1. From the BEACON tab, press UP
2. The EDIT CALLSIGN screen opens showing the current callsign character by character
3. Press UP/DOWN to scroll through characters (A–Z, 0–9, space, -)
4. Press RIGHT to move to the next character position
5. Press LEFT to move back
6. Press SELECT to save

**Expected during editing:**
- The current cursor position is highlighted
- The character above and below the current selection are shown as context
- Other characters in the callsign remain unchanged as you scroll

**Expected after saving:**
- Returns to BEACON tab
- The `Me:` line shows the new callsign immediately
- The next beacon sent from Badge A will show the new callsign on Badge B's PEERS and INBOX tabs
- Power-cycling Badge A and re-entering ESPNow shows the same callsign (NVS persistence confirmed)

**Cancel test:**
1. Open the editor, make a change
2. Press CANCEL instead of SELECT

**Expected:**
- Returns to BEACON tab with the original callsign unchanged

---

## 6. Ping and Round-Trip Time (RTT)

**Prerequisites:** Both badges are on the ESPNow screen and have exchanged at least one beacon

> **Important:** Both badges must be in the ESPNow screen before pinging.
> If Badge B is on a different screen or powered off, Badge A's ping will
> display "RTT: waiting..." indefinitely until Badge B enters ESPNow and
> its auto-reply fires.

**On Badge A:**
1. Navigate to the PEERS tab
2. Scroll to Badge B using UP/DOWN
3. Press SELECT — a targeting menu appears with two options: PING and MESSAGE
4. Navigate to PING and press SELECT

**Expected on Badge A:**
- Returns to BEACON tab
- Shows `RTT: waiting...`
- Within 1–2 seconds, updates to `RTT: N ms` (typically 10–50 ms)

**Expected on Badge B:**
- A new INBOX entry appears from Badge A (the ping is also logged)
- No action required — the pong reply is automatic

**Verify RTT is live:**
- Send a second ping — RTT should update with a fresh measurement each time

---

## 7. Direct Messaging

**Prerequisites:** Both badges are on the ESPNow screen and have exchanged at least one beacon

**On Badge A:**
1. Navigate to the PEERS tab
2. Select Badge B and press SELECT → choose MESSAGE
3. The message composer opens — use UP/DOWN to select characters, RIGHT to advance, SELECT to send

**Expected on Badge A:**
- Returns to BEACON tab after sending
- Serial monitor prints: `[espnow] sent beacon ... TEXT`

**Expected on Badge B:**
- INBOX tab shows a new entry with Badge A's callsign and the message text
- The message is distinct from `[beacon]` entries — it shows the typed text

---

## 8. Encryption Indicator

**Prerequisites:** A ping or message has been sent between the two badges (unicast link established)

**On the sending badge:**
1. Navigate to the PEERS tab

**Expected:**
- The target badge shows a `[E]` label on the right side of its row
- This confirms the unicast link was established with AES-128 encryption (LMK set)
- Broadcast beacons do **not** show `[E]` — encryption is only for unicast

> **Full encryption verification requires a third badge** flashed with a
> different PMK value. Change `"NullCity-Badge-1"` in the firmware to any
> other 16-character string, flash Badge C, and confirm that Badge C's INBOX
> does not receive unicast messages between Badges A and B. Broadcast beacons
> will still appear on Badge C since broadcasts are unencrypted.

---

## 9. Exiting ESPNow

**On either badge:**
1. Press CANCEL from any ESPNow tab

**Expected:**
- Returns to the main menu
- ESPNow radio shuts down immediately (`esp_now_deinit()` + `WiFi.mode(WIFI_OFF)`)
- Serial monitor prints: `[espnow] shut down`
- Re-entering menu item 8 starts fresh — peer table cleared, counts reset to 0
- No background radio activity while on other screens

---

## Quick Pass/Fail Checklist

| Feature | Pass condition |
|---|---|
| Hardware identity | Both badges show different `NCB-XXXXXX` callsigns |
| Tab navigation | LEFT/RIGHT cycles BEACON → PEERS → INBOX |
| Beacon exchange | Pressing SELECT populates the other badge's PEERS and INBOX |
| RSSI at 1 inch | −30 to −45 dBm, 6–8 bars, CLOSE |
| RSSI at 3 metres | −55 to −65 dBm, 3–5 bars, NEAR |
| Callsign edit | Full callsign saves correctly; change persists after power cycle |
| Callsign cancel | Original callsign unchanged after pressing CANCEL |
| Ping RTT | Numeric ms value appears within 2 seconds |
| RTT waiting | Ping shows "waiting..." if second badge is not on ESPNow screen |
| Messaging | Typed text appears in recipient's INBOX |
| Encryption `[E]` | Appears next to peer after first unicast exchange |
| Clean exit | CANCEL returns to menu; re-entry starts with zeroed state |

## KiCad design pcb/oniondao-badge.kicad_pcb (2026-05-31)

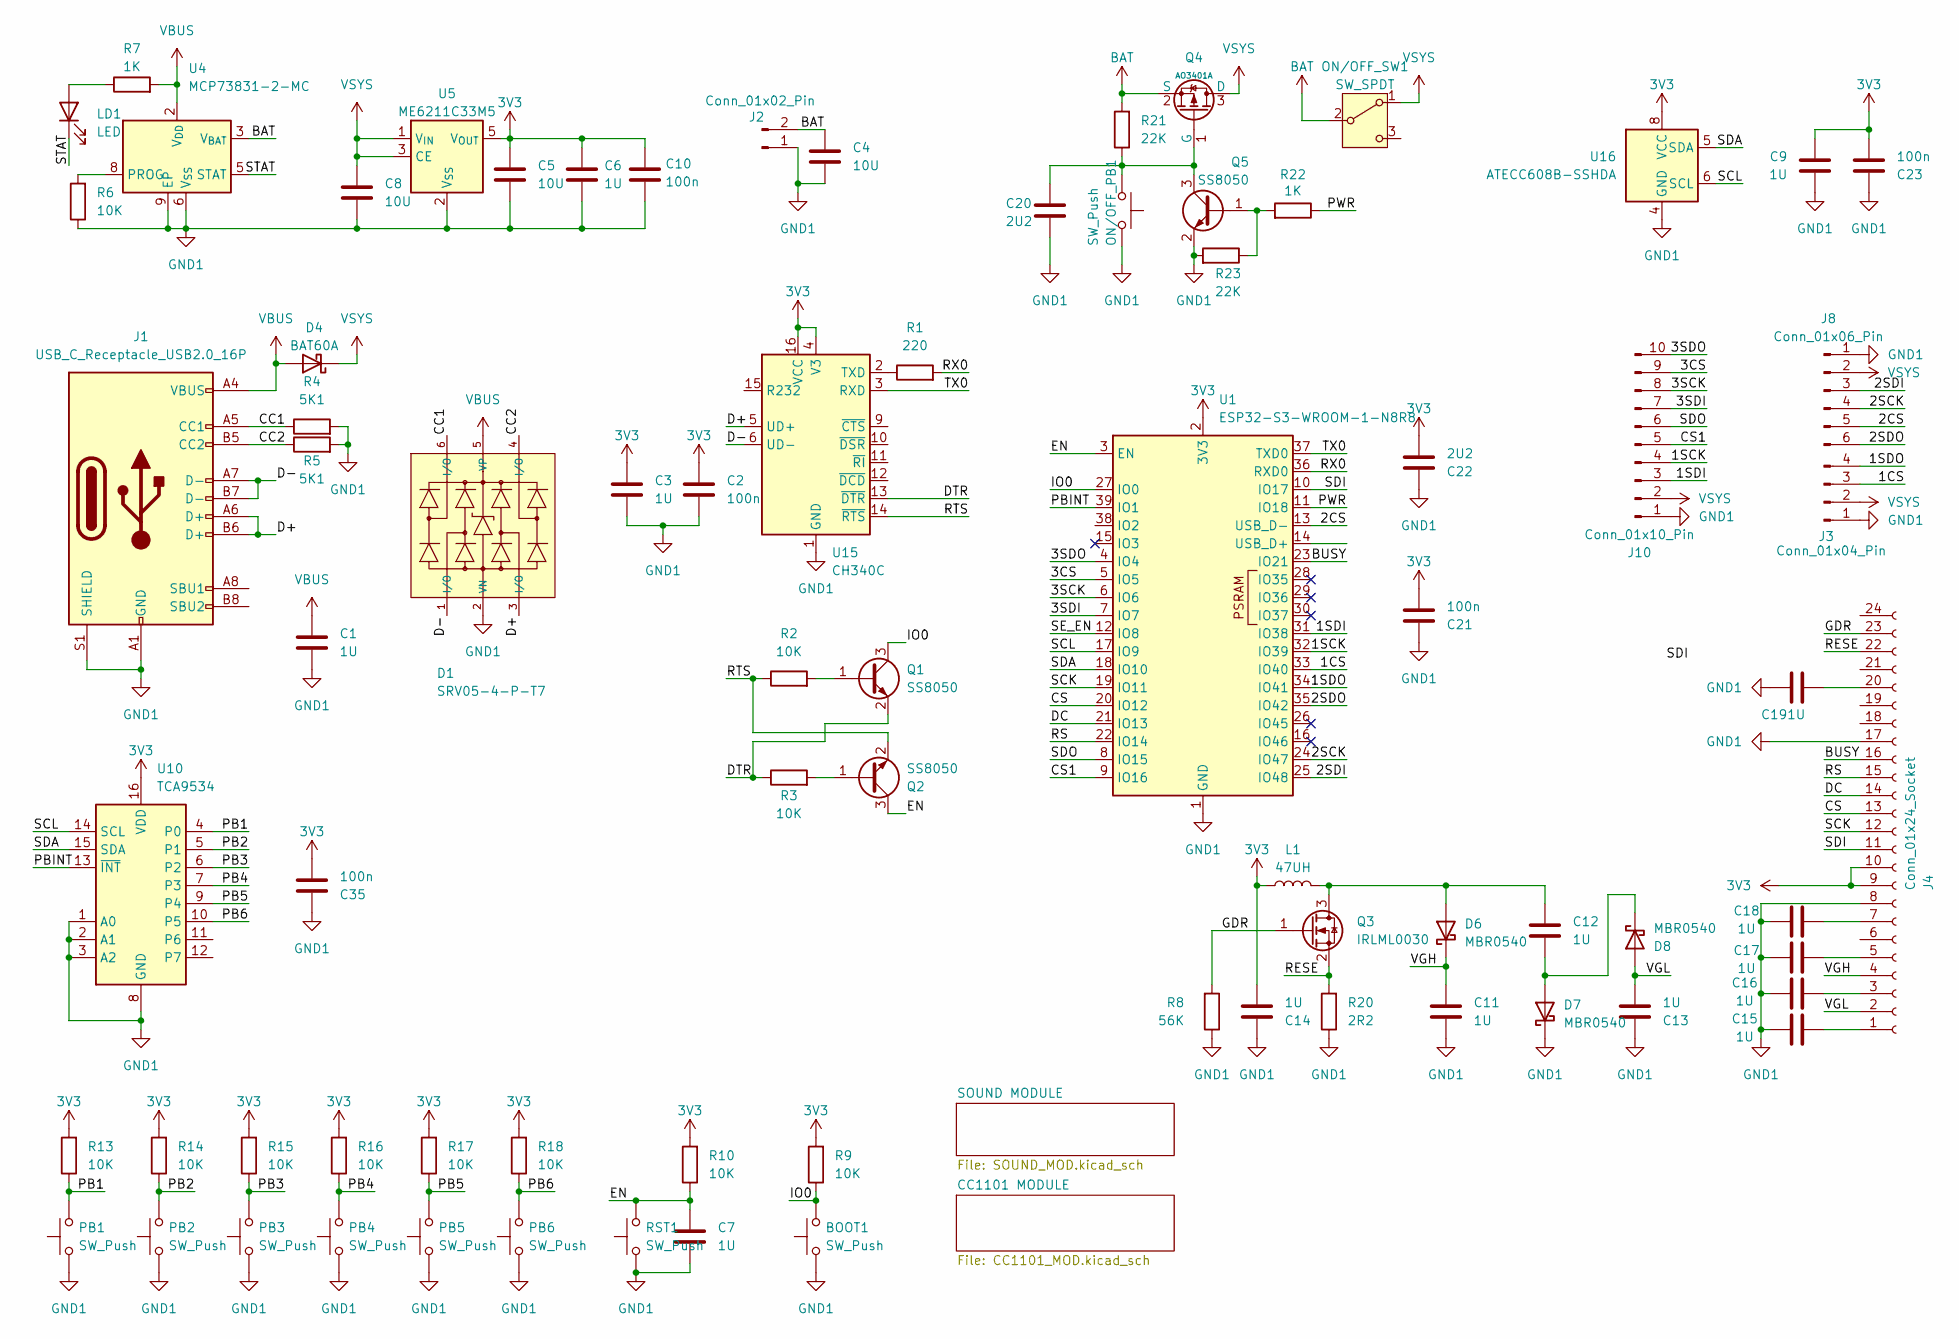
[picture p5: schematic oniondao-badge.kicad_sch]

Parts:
BOOT1: SW_Push; SW_SPST_B3U-1000P
C1, C3, C6, C7, C9, C11, C12, C13, C14, C15, C16, C17, C18, C19: 1U; C_0402_1005Metric
C2, C10, C21, C23, C35: 100n; C_0402_1005Metric
C4, C5, C8: 10U; C_0402_1005Metric
C20, C22: 2U2; C_0402_1005Metric
D1: SRV05-4-P-T7; SOT-23-6_L2.9-W1.6-P0.95-LS2.8-BR; Breakdown Voltage 6V; Part SRV05-4-P-T7; LCSC C85364
D4: BAT60A; D_SOD-323
D6, D7, D8: MBR0540; D_SOD-123
J1: USB_C_Receptacle_USB2.0_16P; USB_C_Receptacle_G-Switch_GT-USB-7010ASV
J2: Conn_01x02_Pin; JST_GH_SM02B-GHS-TB_1x02-1MP_P1.25mm_Horizontal
J3: Conn_01x04_Pin; PinHeader_1x04_P2.54mm_Vertical
J4: Conn_01x24_Socket; Hirose_FH12-24S-0.5SH_1x24-1MP_P0.50mm_Horizontal
J8: Conn_01x06_Pin; PinHeader_1x06_P2.54mm_Vertical
J10: Conn_01x10_Pin; PinHeader_1x10_P2.54mm_Vertical
L1: 47UH; L_APV_ANR4020
LD1: LED; LED_0402_1005Metric
ON/OFF_PB1: SW_Push; SW_SPST_EVQP7C
ON/OFF_SW1: SW_SPDT; SW_SPDT_PCM12
PB1, PB2, PB3, PB4, PB5, PB6: SW_Push; SW_Push_1TS009xxxx-xxxx-xxxx_6x6x5mm
Q1, Q2, Q5: SS8050; SOT-23
Q3: IRLML0030; SOT-23
Q4: AO3401A; Q_SOT-23; Part AO3401A; LCSC C15127
R1: 220; R_0402_1005Metric
R2, R3, R6, R9, R10, R13, R14, R15, R16, R17, R18: 10K; R_0402_1005Metric
R4, R5: 5K1; R_0402_1005Metric
R7, R22: 1K; R_0402_1005Metric
R8: 56K; R_0402_1005Metric
R20: 2R2; R_0603_1608Metric
R21, R23: 22K; R_0402_1005Metric
RST1: SW_Push; SW_SPST_B3U-1000P
U1: ESP32-S3-WROOM-1-N8R8; ESP32-S3-WROOM-1
U4: MCP73831-2-MC; DFN-8-1EP_3x2mm_P0.5mm_EP1.7x1.4mm
U5: ME6211C33M5; SOT-23-5
U10: TCA9534; TSSOP-16_4.4x5mm_P0.65mm
U15: CH340C; SOIC-16_3.9x9.9mm_P1.27mm
U16: ATECC608B-SSHDA; SOIC-8_3.9x4.9mm_P1.27mm

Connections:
3V3: C2.1, C3.1, C5.1, C6.1, C9.1, C10.1, C14.2, C21.2, C22.2, C23.2, C35.2, J4.9, J4.10, L1.1, R9.2, R10.2, R13.2, R14.2, R15.2, R16.2, R17.2, R18.2, U1.2 (3V3), U5.5 (V_{OUT}), U10.16 (VDD), U15.4 (V3), U15.16 (VCC), U16.8 (VCC)
/1CS: J3.3, U1.33 (IO40)
/1SCK: J10.4, U1.32 (IO39)
/1SDI: J10.3, U1.31 (IO38)
/1SDO: J3.4, U1.34 (IO41)
/2CS: J8.5, U1.13 (USB_D-)
/2SCK: J8.4, U1.24 (IO47)
/2SDI: J8.3, U1.25 (IO48)
/2SDO: J8.6, U1.35 (IO42)
/3CS: J10.9, U1.5 (IO5)
/3SCK: J10.8, U1.6 (IO6)
/3SDI: J10.7, U1.7 (IO7)
/3SDO: J10.10, U1.4 (IO4)
/BUSY: J4.16, U1.23 (IO21)
/CC1: D1.6 (I/O), J1.A5 (CC1), R4.1
/CC2: D1.4 (I/O), J1.B5 (CC2), R5.1
/CS: J4.13, U1.20 (IO12)
/CS1: J10.5, U1.9 (IO16)
/D+: D1.3 (I/O), J1.A6 (D+), J1.B6 (D+), U15.5 (UD+)
/D-: D1.1 (I/O), J1.A7 (D-), J1.B7 (D-), U15.6 (UD-)
/DC: J4.14, U1.21 (IO13)
/DTR: Q1.2 (E), R3.1, U15.13 (~DTR)
/EN: C7.1, Q2.3 (C), R10.1, RST1.2, U1.3 (EN)
/GDR: J4.23, Q3.1 (G), R8.2
/IO0: BOOT1.2, Q1.3 (C), R9.1, U1.27 (IO0)
/PB1: PB1.2, R13.1, U10.4 (P0)
/PB2: PB2.2, R14.1, U10.5 (P1)
/PB3: PB3.2, R15.1, U10.6 (P2)
/PB4: PB4.2, R16.1, U10.7 (P3)
/PB5: PB5.2, R17.1, U10.9 (P4)
/PB6: PB6.2, R18.1, U10.10 (P5)
/PBINT: U1.39 (IO1), U10.13 (~INT)
/PWR: R22.1, U1.11 (IO18)
/RESE: J4.22, Q3.2 (S), R20.2
/RS: J4.15, U1.22 (IO14)
/RTS: Q2.2 (E), R2.1, U15.14 (~RTS)
/RX0: R1.2, U1.36 (RXD0)
/SCK: J4.12, U1.19 (IO11)
/SCL: U1.17 (IO9), U10.14 (SCL), U16.6 (SCL)
/SDA: U1.18 (IO10), U10.15 (SDA), U16.5 (SDA)
/SDI: J4.11, U1.10 (IO17)
/SDO: J10.6, U1.8 (IO15)
/SE_EN: U1.12 (IO8)
/STAT: LD1.1 (K), U4.5 (STAT)
/TX0: U1.37 (TXD0), U15.3 (RXD)
/VGH: C11.1, D6.1 (K), J4.4
/VGL: C13.2, D8.2 (A), J4.2
BAT: C4.1, J2.2, ON/OFF_SW1.2 (B), Q4.2 (S), R21.2, U4.3 (V_{BAT}), U4.4 (V_{BAT})
GND1: BOOT1.1, C1.2, C2.2, C3.2, C4.2, C5.2, C6.2, C7.2, C8.2, C9.2, C10.2, C11.2, C13.1, C14.1, C15.1, C16.1, C17.1, C18.1, C19.1, C20.2, C21.1, C22.1, C23.1, C35.1, D1.2 (VN), D7.1 (K), J1.A1 (GND), J1.A12 (GND), J1.B1 (GND), J1.B12 (GND), J1.S1 (SHIELD), J2.1, J3.1, J4.8, J4.17, J8.1, J10.1, ON/OFF_PB1.2, PB1.1, PB2.1, PB3.1, PB4.1, PB5.1, PB6.1, Q5.2 (E), R4.2, R5.2, R6.1, R8.1, R20.1, R23.2, RST1.1, U1.1 (GND), U1.40 (GND), U1.41 (GND), U4.6 (V_{SS}), U4.9 (EP), U5.2 (V_{SS}), U10.1 (A0), U10.2 (A1), U10.3 (A2), U10.8 (GND), U15.1 (GND), U16.4 (GND)
unnamed: C12.1, D6.2 (A), L1.2, Q3.3 (D)
unnamed: C12.2, D7.2 (A), D8.1 (K)
unnamed: C15.2, J4.1
unnamed: C16.2, J4.3
unnamed: C17.2, J4.5
unnamed: C18.2, J4.7
unnamed: C19.2, J4.20
unnamed: LD1.2 (A), R7.1
unnamed: Q1.1 (B), R2.2
unnamed: Q2.1 (B), R3.2
unnamed: C20.1, ON/OFF_PB1.1, Q4.1 (G), Q5.3 (C), R21.1
unnamed: Q5.1 (B), R22.2, R23.1
unnamed: R6.2, U4.8 (PROG)
unnamed: R1.1, U15.2 (TXD)
VBUS: C1.1, D1.5 (VP), D4.2 (A), J1.A4 (VBUS), J1.A9 (VBUS), J1.B4 (VBUS), J1.B9 (VBUS), R7.2, U4.1 (V_{DD}), U4.2 (V_{DD})
VSYS: C8.1, D4.1 (K), J3.2, J8.2, J10.2, ON/OFF_SW1.1 (A), Q4.3 (D), U5.1 (V_{IN}), U5.3 (CE)

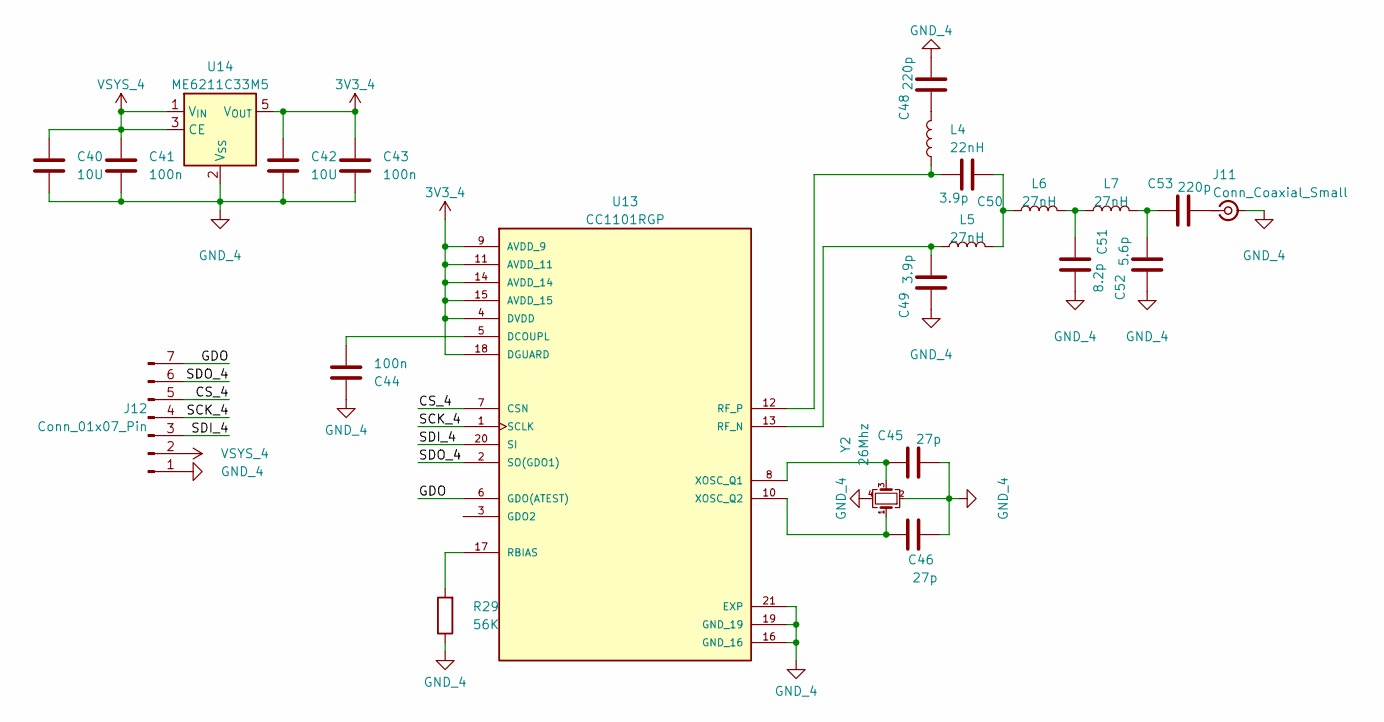
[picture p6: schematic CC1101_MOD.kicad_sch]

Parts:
C40, C42: 10U; C_0402_1005Metric
C41, C43, C44: 100n; C_0402_1005Metric
C45, C46: 27p; C_0402_1005Metric
C48, C53: 220p; C_0402_1005Metric
C49, C50: 3.9p; C_0402_1005Metric
C51: 8.2p; C_0402_1005Metric
C52: 5.6p; C_0402_1005Metric
J11: Conn_Coaxial_Small; SMA_Amphenol_901-143_Horizontal
J12: Conn_01x07_Pin; PinHeader_1x07_P2.54mm_Vertical
L4: 22nH; L_0402_1005Metric
L5, L6, L7: 27nH; L_0402_1005Metric
R29: 56K; R_0402_1005Metric
U13: CC1101RGP; QFN50P400X400X100-21N; PARTREV 6-May-2020
U14: ME6211C33M5; SOT-23-5
Y2: 26Mhz; Crystal_SMD_3225-4Pin_3.2x2.5mm

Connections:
3V3_4: C42.1, C43.1, U13.4 (DVDD), U13.9 (AVDD_9), U13.11 (AVDD_11), U13.14 (AVDD_14), U13.15 (AVDD_15), U13.18 (DGUARD), U14.5 (V_{OUT})
/CC1101 MODULE/CS_4: J12.5, U13.7 (CSN)
/CC1101 MODULE/GDO: J12.7, U13.6 (GDO(ATEST))
/CC1101 MODULE/SCK_4: J12.4, U13.1 (SCLK)
/CC1101 MODULE/SDI_4: J12.3, U13.20 (SI)
/CC1101 MODULE/SDO_4: J12.6, U13.2 (SO(GDO1))
GND_4: C40.2, C41.2, C42.2, C43.2, C44.1, C45.2, C46.2, C48.2, C49.1, C51.2, C52.1, J11.2 (Ext), J12.1, R29.1, U13.16 (GND_16), U13.19 (GND_19), U13.21 (EXP), U14.2 (V_{SS}), Y2.2, Y2.4
unnamed: C48.1, L4.2
unnamed: C50.1, L5.2, L6.1
unnamed: C51.1, L6.2, L7.1
unnamed: C52.2, C53.1, L7.2
unnamed: C53.2, J11.1 (In)
unnamed: C44.2, U13.5 (DCOUPL)
unnamed: R29.2, U13.17 (RBIAS)
unnamed: C49.2, L5.1, U13.13 (RF_N)
unnamed: C50.2, L4.1, U13.12 (RF_P)
unnamed: C45.1, U13.8 (XOSC_Q1), Y2.3
unnamed: C46.1, U13.10 (XOSC_Q2), Y2.1
VSYS_4: C40.1, C41.1, J12.2, U14.1 (V_{IN}), U14.3 (CE)

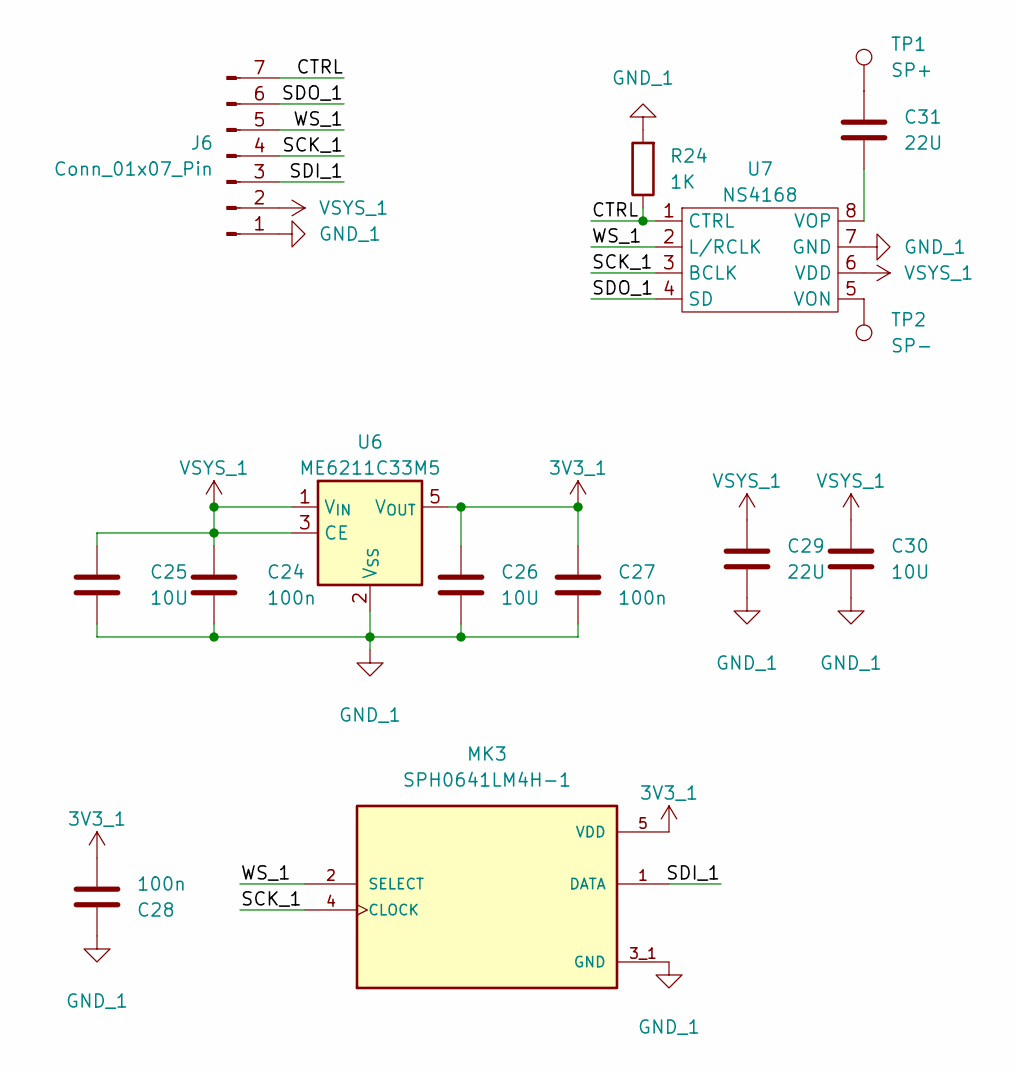
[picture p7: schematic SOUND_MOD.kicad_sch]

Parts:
C24, C27, C28: 100n; C_0402_1005Metric
C25, C26, C30: 10U; C_0402_1005Metric
C29, C31: 22U; C_0402_1005Metric
J6: Conn_01x07_Pin; PinHeader_1x07_P2.54mm_Vertical
MK3: SPH0641LM4H-1; MIC_SPH0641LM4H-1; PARTREV D
R24: 1K; R_0402_1005Metric
TP1: SP+; Pin_D1.3mm_L11.0mm
TP2: SP-; Pin_D1.3mm_L11.0mm
U6: ME6211C33M5; SOT-23-5
U7: NS4168; SOIC-8-1EP_3.9x4.9mm_P1.27mm_EP2.29x3mm

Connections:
3V3_1: C26.1, C27.1, C28.2, MK3.5 (VDD), U6.5 (V_{OUT})
/SOUND MODULE/CTRL: J6.7, R24.1, U7.1 (CTRL)
/SOUND MODULE/SCK_1: J6.4, MK3.4 (CLOCK), U7.3 (BCLK)
/SOUND MODULE/SDI_1: J6.3, MK3.1 (DATA)
/SOUND MODULE/SDO_1: J6.6, U7.4 (SD)
/SOUND MODULE/WS_1: J6.5, MK3.2 (SELECT), U7.2 (L/RCLK)
GND_1: C24.2, C25.2, C26.2, C27.2, C28.1, C29.2, C30.2, J6.1, MK3.3_1 (GND), MK3.3_2 (GND), R24.2, U6.2 (V_{SS}), U7.7 (GND), U7.9 (GND)
unnamed: C31.1, TP1.1
unnamed: TP2.1, U7.5 (VON)
unnamed: C31.2, U7.8 (VOP)
VSYS_1: C24.1, C25.1, C29.1, C30.1, J6.2, U6.1 (V_{IN}), U6.3 (CE), U7.6 (VDD)

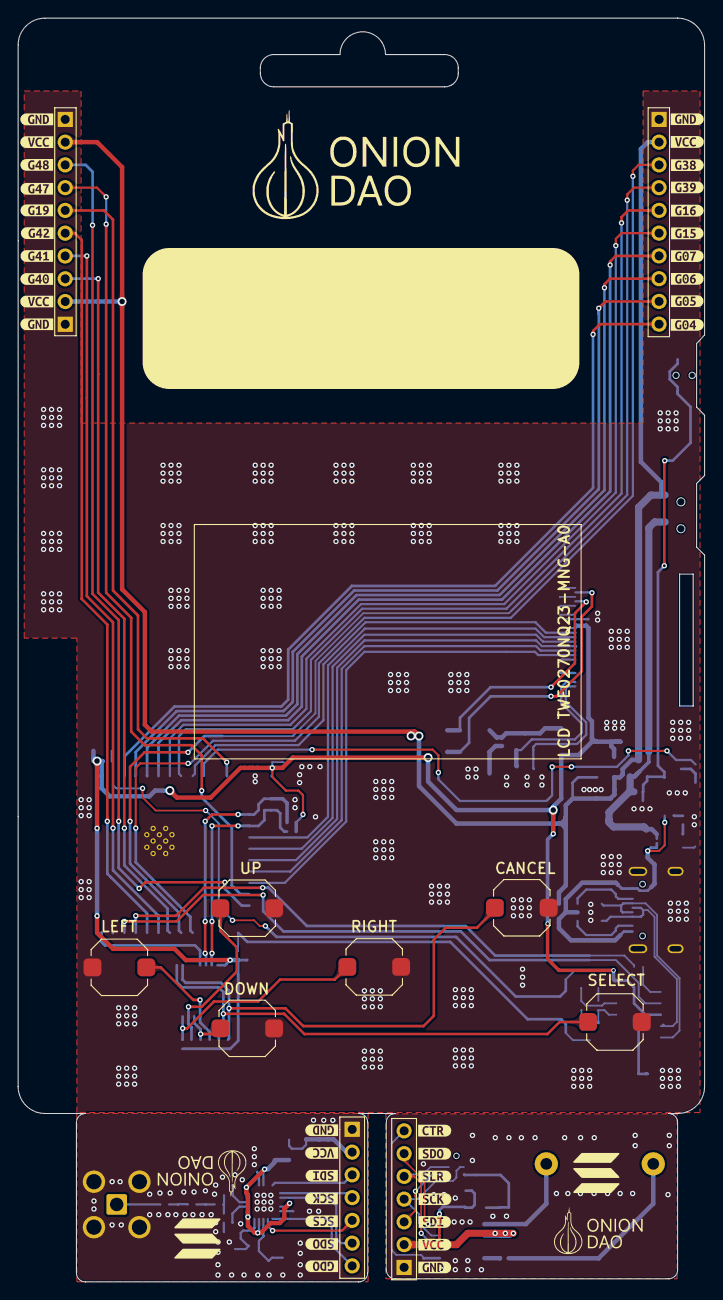
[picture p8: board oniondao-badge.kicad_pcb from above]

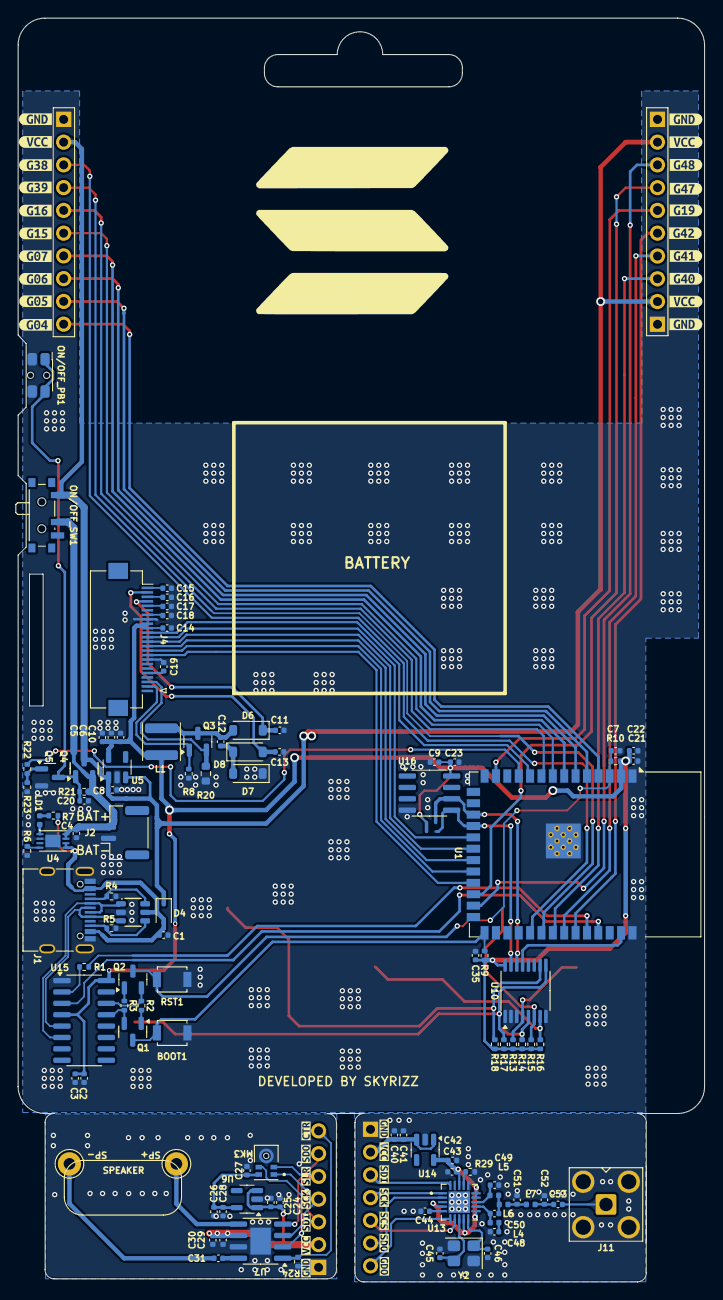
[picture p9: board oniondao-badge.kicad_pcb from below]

Board: 2 copper layers, 76.6 x 141.1 mm, 184 parts (140 on the bottom side), 94 nets.

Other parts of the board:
kibuzzard-69D7A2FA: G***; kibuzzard-69D7A2FA
kibuzzard-69D7A5EF: G***; kibuzzard-69D7A5EF
kibuzzard-69D7A5F4, kibuzzard-69D7A5F4#2: G***; kibuzzard-69D7A5F4
kibuzzard-69D7A28C, kibuzzard-69D7A28C#2: G***; kibuzzard-69D7A28C
kibuzzard-69D7A260, kibuzzard-69D7A260#2: G***; kibuzzard-69D7A260
kibuzzard-69D7A287, kibuzzard-69D7A287#2: G***; kibuzzard-69D7A287
kibuzzard-69D7A626, kibuzzard-69D7A626#2: G***; kibuzzard-69D7A626
kibuzzard-69D7A630, kibuzzard-69D7A630#2: G***; kibuzzard-69D7A630
kibuzzard-69D7A638, kibuzzard-69D7A638#2: G***; kibuzzard-69D7A638
kibuzzard-69D7A640, kibuzzard-69D7A640#2: G***; kibuzzard-69D7A640
kibuzzard-69D7D7AD: G***; kibuzzard-69D7D7AD
kibuzzard-69D7D7BC: G***; kibuzzard-69D7D7BC
kibuzzard-69D7D86C: G***; kibuzzard-69D7D86C
kibuzzard-69D7D873: G***; kibuzzard-69D7D873
kibuzzard-69D663AD: G***; kibuzzard-69D663AD
kibuzzard-69D663C6, kibuzzard-69D663C6#2, kibuzzard-69D663C6#3, kibuzzard-69D663C6#4, kibuzzard-69D663C6#5: G***; kibuzzard-69D663C6
kibuzzard-69D665BB: G***; kibuzzard-69D665BB
kibuzzard-69D665D2: G***; kibuzzard-69D665D2
kibuzzard-69D665E3: G***; kibuzzard-69D665E3
kibuzzard-69D665EF: G***; kibuzzard-69D665EF
kibuzzard-69D665FA: G***; kibuzzard-69D665FA
kibuzzard-69D673B2: G***; kibuzzard-69D673B2
kibuzzard-69D673C1: G***; kibuzzard-69D673C1
kibuzzard-69D673C9: G***; kibuzzard-69D673C9
kibuzzard-69D673D2: G***; kibuzzard-69D673D2
kibuzzard-69D6643F: G***; kibuzzard-69D6643F
kibuzzard-69D6645F: G***; kibuzzard-69D6645F
kibuzzard-69D7012B: G***; kibuzzard-69D7012B
kibuzzard-69D66402: G***; kibuzzard-69D66402
kibuzzard-69D66408: G***; kibuzzard-69D66408
kibuzzard-69D66453: G***; kibuzzard-69D66453
kibuzzard-69D66465: G***; kibuzzard-69D66465
kibuzzard-69D66565, kibuzzard-69D66565#2, kibuzzard-69D66565#3: G***; kibuzzard-69D66565
kibuzzard-69D66580, kibuzzard-69D66580#2, kibuzzard-69D66580#3: G***; kibuzzard-69D66580
kibuzzard-69D66624: G***; kibuzzard-69D66624
kibuzzard-69D70112, kibuzzard-69D70112#2, kibuzzard-69D70112#3: G***; kibuzzard-69D70112
kibuzzard-69D70126: G***; kibuzzard-69D70126
kibuzzard-69D70130: G***; kibuzzard-69D70130
kibuzzard-69D70134: G***; kibuzzard-69D70134
kibuzzard-69D70186: G***; kibuzzard-69D70186
kibuzzard-69E6D5DE: G***; kibuzzard-69E6D5DE
kibuzzard-69E6D5FA: G***; kibuzzard-69E6D5FA
kibuzzard-69E6D61C: G***; kibuzzard-69E6D61C
kibuzzard-69E6D63B: G***; kibuzzard-69E6D63B
kibuzzard-69E6D601: G***; kibuzzard-69E6D601
kibuzzard-69E6D610: G***; kibuzzard-69E6D610
kibuzzard-69E6D626: G***; kibuzzard-69E6D626
kibuzzard-69E6D641: G***; kibuzzard-69E6D641
kibuzzard-69E6DA12: G***; kibuzzard-69E6DA12
kibuzzard-69E6DA18: G***; kibuzzard-69E6DA18

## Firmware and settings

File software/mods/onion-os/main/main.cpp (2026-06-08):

#include <Arduino.h>
#include <SPI.h>
#include <SPIFFS.h>
#include <Preferences.h>
#include <WiFi.h>
#include <Wire.h>
#include <esp_now.h>
#include <esp_crt_bundle.h>
#include <esp_http_client.h>
#include <esp_heap_caps.h>
#include <esp_random.h>
#include <esp_wifi.h>
#include <esp_sntp.h>
#include <mqtt_client.h>
#include <driver/i2s_std.h>
#include <driver/i2s_pdm.h>
#include <cJSON.h>
#include <mbedtls/base64.h>
#include <sodium.h>

extern "C" {
#include "cryptoauthlib.h"
#include "lua.h"
#include "lauxlib.h"
#include "lualib.h"
}

#include <GxEPD2_BW.h>
#include <gdey/GxEPD2_270_GDEY027T91.h>
#include <Fonts/FreeMono9pt7b.h>
#include <Fonts/FreeMonoBold9pt7b.h>
#include <Fonts/FreeMonoBold18pt7b.h>

#include <algorithm>
#include <atomic>
#include <cmath>
#include <cstdlib>
#include <cstring>
#include <string>
#include <vector>

#if __has_include("onion_config.generated.h")
#include "onion_config.generated.h"
#elif __has_include("onion_config.h")
#include "onion_config.h"
#else
#define ONION_DEFAULT_WIFI_SSID ""
#define ONION_DEFAULT_WIFI_PASSWORD ""
#define ONION_DEFAULT_SERVER_BASE_URL "https://oniondao.dev"
#define ONION_DEFAULT_BADGE_API_KEY ""
#define ONION_DEFAULT_MQTT_URI ""
#define ONION_DEFAULT_MQTT_USERNAME "oniondao"
#define ONION_DEFAULT_MQTT_PASSWORD "02eb3d5e04fd2dc9cbb6f3f5c6c9d89d9c96acd987cc24ddf9f717f9480e8786"
#define ONION_DEFAULT_MQTT_TOPIC_PREFIX "oniondao"
#define ONION_DEFAULT_SCRIPT_MANIFEST_URL ""
#endif

#include "badge_pins.h"
#include "logo_bitmap.h"

#ifndef ONION_HARDCODED_WIFI_SSID
#define ONION_HARDCODED_WIFI_SSID "CIC Guest"
#endif
#ifndef ONION_HARDCODED_WIFI_PASSWORD
#define ONION_HARDCODED_WIFI_PASSWORD "1nnovation"
#endif
#ifndef ONION_HARDCODED_SERVER_BASE_URL
#define ONION_HARDCODED_SERVER_BASE_URL "https://oniondao.dev"
#endif
#ifndef ONION_HARDCODED_MQTT_URI
#define ONION_HARDCODED_MQTT_URI "mqtt://shortline.proxy.rlwy.net:20928"
#endif
#ifndef ONION_HARDCODED_MQTT_USERNAME
#define ONION_HARDCODED_MQTT_USERNAME "oniondao"
#endif
#ifndef ONION_HARDCODED_MQTT_PASSWORD
#define ONION_HARDCODED_MQTT_PASSWORD "02eb3d5e04fd2dc9cbb6f3f5c6c9d89d9c96acd987cc24ddf9f717f9480e8786"
#endif

#define TCA9534_ADDR   0x20
#define TCA9534_INPUT  0x00
#define TCA9534_CONFIG 0x03

#define BTN_LEFT   (1 << 0)
#define BTN_DOWN   (1 << 1)
#define BTN_UP     (1 << 2)
#define BTN_RIGHT  (1 << 3)
#define BTN_SELECT (1 << 4)
#define BTN_CANCEL (1 << 5)

#define SERIAL_BAUD 115200
#define WIFI_CONNECT_TIMEOUT_MS 15000
#define HANDSHAKE_INTERVAL_MS 30000
#define PROFILE_REFRESH_INTERVAL_MS 60000
#define MQTT_RECONNECT_INTERVAL_MS 5000
#define MQTT_HANDSHAKE_ACCEPT_WINDOW_MS 10000
#define BOOT_SPLASH_MS 3000
// Lua allocates from PSRAM where available; scripts can be large enough for
// pushed apps and streaming voice helpers without relying on fragmented RAM.
#define MAX_SCRIPT_BYTES (256 * 1024)
#define MQTT_CLIENT_BUFFER_BYTES (32 * 1024)
#define MQTT_CLIENT_OUT_BUFFER_BYTES 4096
#define MQTT_RX_MAX_BYTES (MAX_SCRIPT_BYTES * 2 + 4096)
#define MQTT_RX_TEMP_JSON_PATH "/mqtt_lua_push.json"
#define LUA_PUSH_TEMP_PATH "/scripts_push_tmp.lua"
#define MAX_IMAGE_BYTES (192 * 1024)
#define ATECC_HMAC_SLOT 10
#define ATECC_I2C_ADDRESS_8BIT 0xC0
#define ATECC_SERIAL_LEN 9
#define SOLANA_PUBKEY_LEN 32
#define SOLANA_SIGNATURE_LEN 64
#define SOLANA_SECRET_KEY_LEN 64
#define SOLANA_SEED_LEN 32
#define SOLANA_KEY_NONCE_LEN crypto_aead_xchacha20poly1305_ietf_NPUBBYTES
#define SOLANA_KEY_MAC_LEN crypto_aead_xchacha20poly1305_ietf_ABYTES
#define LUA_GPIO_POLL_MAX_MS 30000
#define LUA_SLEEP_MAX_MS 60000
#define LUA_ESPNOW_RECV_MAX_MS 30000
#define ONION_ESPNOW_MAX_PAYLOAD 240
#define LUA_KV_MAX_VALUE 240          // kv values mirror the ESP-NOW payload cap
// Static internal RAM (~32 KB); the queue is filled from the WiFi task
// callback, so it must not live in PSRAM. Sized so a receiver can sit inside
// a full e-ink refresh (~1.7 s) while a peer streams 240-byte voice frames at
// ~66 frames/s (~112 frames) without dropping any.
#define ONION_ESPNOW_QUEUE_LEN 128
#define LUA_HTTP_MAX_TIMEOUT_MS 30000
#define LUA_HTTP_DEFAULT_TIMEOUT_MS 10000
#define LUA_MQTT_RECV_MAX_MS 30000
#define ONION_LUA_MQTT_MAX_TOPIC 128
#define ONION_LUA_MQTT_MAX_PAYLOAD 512
#define ONION_LUA_MQTT_QUEUE_LEN 8
#define ONION_LUA_MQTT_MAX_SUBS 8
#define ONION_CHECKIN_SCAN_INTERVAL_MS 5000
#define ONION_CHECKIN_PROMPT_COOLDOWN_MS 300000
#define ONION_CHECKIN_RESULT_MS 15000
#define ONION_CHECKIN_DEFAULT_MIN_RSSI -62
// Swappable side-port modules (see docs/MODULES.md). CC1101 and the Sound
// module share the same physical pins, so only one may be active at a time.
#define CC1101_XOSC_MHZ 26.0
#define CC1101_SPI_HZ 4000000
#define SUBGHZ_MAX_PACKET 61
#define SUBGHZ_RX_MAX_MS 30000
#define SOUND_SPK_SAMPLE_RATE 44100
#define SOUND_MIC_SAMPLE_RATE 16000
#define SOUND_TONE_MAX_MS 10000
#define SOUND_PLAY_MAX_BYTES 65536
#define SOUND_MIC_MAX_SAMPLES 4096
#define SOUND_MIC_READ_MAX_TIMEOUT_MS 5000
#define SOUND_MIC_MAX_DISCARD_MS 1000
#define SOUND_AMP_UNMUTE_MS 100
#define ONION_DISPLAY_WIDTH 264
#define ONION_DISPLAY_HEIGHT 176
#ifndef PIN_BATTERY_ADC
#define PIN_BATTERY_ADC -1
#endif
#ifndef BATTERY_ADC_DIVIDER_RATIO
#define BATTERY_ADC_DIVIDER_RATIO 2.0f
#endif
#ifndef BATTERY_ADC_OFFSET_MV
#define BATTERY_ADC_OFFSET_MV 0
#endif
#define BATTERY_SAMPLE_INTERVAL_MS 60000
#define BATTERY_REDRAW_PERCENT_STEP 5

GxEPD2_BW<GxEPD2_270_GDEY027T91, GxEPD2_270_GDEY027T91::HEIGHT> display(
    GxEPD2_270_GDEY027T91(PIN_EPD_CS, PIN_EPD_DC, PIN_EPD_RST, PIN_EPD_BUSY)
);
static GFXcanvas1 g_luaCanvas(ONION_DISPLAY_WIDTH, ONION_DISPLAY_HEIGHT);

// UI framebuffer — all screen draw functions render here; flushFrame() decides
// whether to push a partial or full refresh to the e-ink panel.
static GFXcanvas1 g_frame(ONION_DISPLAY_WIDTH, ONION_DISPLAY_HEIGHT);
static const int FRAME_BPR   = (ONION_DISPLAY_WIDTH + 7) / 8;   // bytes per row = 33
static const int FRAME_BYTES = FRAME_BPR * ONION_DISPLAY_HEIGHT; // 5808
static uint8_t   g_prevFrame[FRAME_BPR * ONION_DISPLAY_HEIGHT];  // last flushed snapshot
static uint16_t  g_partialCount    = 0;
static bool      g_forceFullRefresh = true;   // first flush is always full
static bool      g_luaDeferFlush    = false;  // true between display_begin/commit
static bool      g_luaFramePending  = false;  // draw happened since last deferred flush

enum Screen : uint8_t {
    SCREEN_BOOT_SPLASH,
    SCREEN_STATUS,
    SCREEN_SCRIPT_EXPLORER,
    SCREEN_LINK_PROMPT,
    SCREEN_TX_PROMPT,
    SCREEN_LUA_PROMPT,
    SCREEN_CHECKIN_PROMPT,
    SCREEN_CHECKIN_RESULT,
    SCREEN_LOG,
    SCREEN_SETTINGS,
    SCREEN_WIFI_OVERVIEW,
    SCREEN_WIFI_SCANNING,
    SCREEN_WIFI_LIST,
    SCREEN_WIFI_PASSWORD,
    SCREEN_WIFI_CONNECTING,
    SCREEN_WIFI_RESULT,
    SCREEN_DELETE_CONFIRM,
};

enum HomeItem : int {
    HOME_ITEM_SCRIPTS,
    HOME_ITEM_REFRESH,
    HOME_ITEM_SETTINGS,
    HOME_ITEM_COUNT,
};

struct RuntimeConfig {
    String wifiSsid;
    String wifiPassword;
    String serverBaseUrl;
    String badgeApiKey;
    String mqttUri;
    String mqttUsername;
    String mqttPassword;
    String mqttTopicPrefix;
    String scriptManifestUrl;
    String moduleVariant;
};

struct BadgeIdentity {
    String hardwareId;
    uint64_t onionId = 0;
    String status = "booting";
    String username;
    String onionCount = "0";
    String solanaPublicKey;
    bool linked = false;
};

struct LinkPrompt {
    String requestId;
    String username;
    bool active = false;
};

struct TransactionPrompt {
    String operationId;
    String requestId;
    String type;
    int amount = 0;
    String transactionBase64;
    bool active = false;
};

struct LuaScriptPrompt {
    String requestId;
    String scriptId;
    String title;
    String fileName;
    String description;
    String authorUsername;
    String downloadUrl;
    String code;
    String codePath;
    int sizeBytes = 0;
    bool active = false;
};

struct CheckInPrompt {
    String beaconId;
    String room;
    String label;
    uint8_t beaconMac[6] = {};
    uint8_t nonce[8] = {};
    int8_t rssi = 0;
    int8_t minRssi = ONION_CHECKIN_DEFAULT_MIN_RSSI;
    bool active = false;
};

struct CheckInResult {
    String beaconId;
    String message;
    int points = 0;
    bool awarded = false;
    uint32_t shownAt = 0;
};

static RuntimeConfig g_config;
static BadgeIdentity g_identity;
static LinkPrompt g_linkPrompt;
static TransactionPrompt g_txPrompt;
static LuaScriptPrompt g_luaPrompt;
static CheckInPrompt g_checkinPrompt;
static CheckInResult g_checkinResult;
static Preferences g_prefs;
static esp_mqtt_client_handle_t g_mqtt = nullptr;
static bool g_mqttConnected = false;
static Screen g_screen     = SCREEN_BOOT_SPLASH;
static Screen g_lastScreen = SCREEN_BOOT_SPLASH; // last screen rendered; drives full-refresh on change
static bool g_needsRedraw = true;
static uint8_t g_lastButtons = 0;
static uint32_t g_lastButtonPoll = 0;
static uint32_t g_lastHandshake = 0;
static uint32_t g_lastProfileRefresh = 0;
static uint32_t g_lastMqttAttempt = 0;
static uint32_t g_lastWifiAttempt = 0;
static uint32_t g_lastCheckInScan = 0;
static uint32_t g_lastCheckInPromptAt = 0;
static uint32_t g_mqttHandshakeSentAt = 0;
static bool g_mqttHandshakePending = false;
static String g_log = "Booting";
static String g_lastLuaError;
static int g_homeSelection = 0;
static int g_scriptSelection = 0;
static std::vector<String> g_scripts;
static String g_pendingDeletePath;
static bool   g_deleteChoice = false; // false=CANCEL, true=DELETE
static bool g_luaDisplayActive = false;
static bool g_ateccReady = false;
static uint8_t g_ateccSerial[ATECC_SERIAL_LEN] = {};
#if PIN_BATTERY_ADC >= 0
static int g_batteryPercent = -1;
static int g_batteryVoltageMv = 0;
static int g_batteryDisplayedPercent = -1;
static uint32_t g_lastBatterySample = 0;
#endif

// ── WiFi setup state ─────────────────────────────────────────────────────────
struct WifiNetwork {
    char ssid[33];
    int8_t rssi;
    bool secured;
};
static std::vector<WifiNetwork> g_wifiNetworks;
static int g_wifiListSel = 0;
static String g_wifiConnectSsid;
static char g_wifiPassBuf[65] = {};
static int g_wifiPassLen = 0;
static int g_settingsSel = 0;
static int g_wifiOverviewSel = 0;
static String g_wifiResultMsg;

#define WIFI_WORKER_IDLE    0
#define WIFI_WORKER_RUNNING 1
#define WIFI_WORKER_DONE    2
#define WIFI_WORKER_FAILED  3
static std::atomic<int> g_wifiWorkerResult(WIFI_WORKER_IDLE);

// Full QWERTY keyboard: 5 char rows + 1 control row (row 5)
static const char* kKbNormal[5] = {
    "1234567890",
    "qwertyuiop",
    "asdfghjkl",
    "zxcvbnm",
    "!@#$%&*-_=+.",
};
static const char* kKbCaps[5] = {
    "1234567890",
    "QWERTYUIOP",
    "ASDFGHJKL",
    "ZXCVBNM",
    "!@#$%&*-_=+.",
};
static const int kKbTotalRows = 6; // 5 char rows + 1 control row
static int g_kbRow = 0;
static int g_kbCol = 0;
static bool g_kbCaps = false;

struct WifiConnectArgs {
    char ssid[33];
    char pass[65];
};
static WifiConnectArgs g_wifiConnectArgs;
// ─────────────────────────────────────────────────────────────────────────────

static const int kLuaReadableGpios[] = {48, 47, 19, 42, 41, 40, 38, 39, 16, 15, 7, 6, 5, 4};

struct LuaButton {
    const char* name;
    uint8_t mask;
};

struct EspNowQueuedMessage {
    uint8_t mac[6] = {};
    uint8_t len = 0;
    char payload[ONION_ESPNOW_MAX_PAYLOAD + 1] = {};
    int8_t rssi = 0;
    uint32_t receivedAt = 0;
};

static const LuaButton kLuaButtons[] = {
    {"left", BTN_LEFT},
    {"down", BTN_DOWN},
    {"up", BTN_UP},
    {"right", BTN_RIGHT},
    {"select", BTN_SELECT},
    {"cancel", BTN_CANCEL},
};

static const uint8_t kEspNowBroadcastMac[6] = {0xff, 0xff, 0xff, 0xff, 0xff, 0xff};

enum CheckInPacketType : uint8_t {
    CHECKIN_PACKET_ADVERTISE = 1,
    CHECKIN_PACKET_APPROVE = 2,
    CHECKIN_PACKET_RESULT = 3,
};

static const char kCheckInMagic[6] = {'O', 'N', 'C', 'H', 'K', '1'};
static const uint8_t kCheckInVersion = 1;

struct __attribute__((packed)) CheckInPacketHeader {
    char magic[6];
    uint8_t version;
    uint8_t type;
};

struct __attribute__((packed)) CheckInAdvertisePacket {
    CheckInPacketHeader header;
    char beaconId[32];
    char room[32];
    char label[48];
    int8_t minRssi;
    uint8_t nonce[8];
    uint32_t sequence;
};

struct __attribute__((packed)) CheckInApprovePacket {
    CheckInPacketHeader header;
    char beaconId[32];
    uint8_t nonce[8];
    char hardwareId[65];
    uint64_t onionId;
    char username[32];
    char wallet[48];
    int8_t rssi;
    uint32_t approvedAt;
    uint8_t badgeMac[6];
};

struct __attribute__((packed)) CheckInResultPacket {
    CheckInPacketHeader header;
    char beaconId[32];
    uint8_t nonce[8];
    uint8_t awarded;
    uint16_t points;
    char message[80];
};

struct CheckInPendingOffer {
    uint8_t beaconMac[6] = {};
    char beaconId[33] = {};
    char room[33] = {};
    char label[49] = {};
    uint8_t nonce[8] = {};
    int8_t rssi = 0;
    int8_t minRssi = ONION_CHECKIN_DEFAULT_MIN_RSSI;
    uint32_t seenAt = 0;
};

struct CheckInPendingResult {
    char beaconId[33] = {};
    uint8_t nonce[8] = {};
    bool awarded = false;
    uint16_t points = 0;
    char message[81] = {};
};

static bool g_espnowStarted = false;
static uint32_t g_espnowSent = 0;
static uint32_t g_espnowReceived = 0;
static portMUX_TYPE g_espnowMux = portMUX_INITIALIZER_UNLOCKED;
static EspNowQueuedMessage g_espnowQueue[ONION_ESPNOW_QUEUE_LEN];
static uint8_t g_espnowQueueHead = 0;
static uint8_t g_espnowQueueCount = 0;
static portMUX_TYPE g_checkinMux = portMUX_INITIALIZER_UNLOCKED;
static CheckInPendingOffer g_checkinPendingOffer;
static CheckInPendingResult g_checkinPendingResult;
static bool g_checkinOfferPending = false;
static bool g_checkinResultPending = false;
static String g_lastCheckInBeaconId;

static bool refreshPublicProfile(bool quiet);

struct MqttQueuedMessage {
    char topic[ONION_LUA_MQTT_MAX_TOPIC + 1] = {};
    char payload[ONION_LUA_MQTT_MAX_PAYLOAD + 1] = {};
    uint16_t topicLen = 0;
    uint16_t payloadLen = 0;
    uint32_t receivedAt = 0;
};

// Topics a Lua script asked to receive, plus a ring buffer the MQTT task fills
// and onion.mqtt_receive() drains. Guarded by g_luaMqttMux because the MQTT
// client event handler runs on its own task.
static portMUX_TYPE g_luaMqttMux = portMUX_INITIALIZER_UNLOCKED;
static char g_luaMqttSubs[ONION_LUA_MQTT_MAX_SUBS][ONION_LUA_MQTT_MAX_TOPIC + 1];
static uint8_t g_luaMqttSubCount = 0;
static MqttQueuedMessage g_luaMqttQueue[ONION_LUA_MQTT_QUEUE_LEN];
static uint8_t g_luaMqttQueueHead = 0;
static uint8_t g_luaMqttQueueCount = 0;
static String g_mqttRxTopic;
static uint8_t* g_mqttRxPresent = nullptr;
static File g_mqttRxFile;
static int g_mqttRxExpectedLen = 0;
static int g_mqttRxReceivedLen = 0;
static size_t g_mqttRxPresentBytes = 0;
static int g_mqttRxMsgId = 0;

static String prefString(const char* key, const char* fallback) {
    String value = g_prefs.getString(key, "");
    return value.length() ? value : String(fallback);
}

static void saveConfigValue(const char* key, const String& value) {
    g_prefs.putString(key, value);
}

static void setLog(const String& message) {
    bool changed = g_log != message;
    g_log = message;
    Serial.printf("[onion-os] %s\n", message.c_str());
    if (changed && !g_luaDisplayActive) g_needsRedraw = true;
}

static String generateHardwareId() {
    char buf[65];
    for (int i = 0; i < 32; i += 4) {
        uint32_t r = esp_random();
        snprintf(buf + (i * 2), 9, "%08lx", (unsigned long)r);
    }
    buf[64] = '\0';
    return String(buf);
}

static void loadConfig() {
    g_prefs.begin("onion-os", false);
    g_config.wifiSsid = prefString("wifi_ssid", ONION_HARDCODED_WIFI_SSID);
    g_config.wifiPassword = prefString("wifi_pass", ONION_HARDCODED_WIFI_PASSWORD);
    g_config.serverBaseUrl = ONION_HARDCODED_SERVER_BASE_URL;
    g_config.badgeApiKey = prefString("api_key", ONION_DEFAULT_BADGE_API_KEY);
    g_config.mqttUri = ONION_HARDCODED_MQTT_URI;
    g_config.mqttUsername = ONION_HARDCODED_MQTT_USERNAME;
    g_config.mqttPassword = ONION_HARDCODED_MQTT_PASSWORD;
    g_config.mqttTopicPrefix = prefString("mqtt_prefix", ONION_DEFAULT_MQTT_TOPIC_PREFIX);
    g_config.scriptManifestUrl = prefString("script_url", ONION_DEFAULT_SCRIPT_MANIFEST_URL);
    g_config.moduleVariant = prefString("mod_variant", "L1");
    g_identity.hardwareId = prefString("hw_id", "");
    if (!g_identity.hardwareId.length()) {
        g_identity.hardwareId = generateHardwareId();
        g_prefs.putString("hw_id", g_identity.hardwareId);
    }
    g_identity.onionId = g_prefs.getULong64("onion_id", 0);
    g_identity.status = prefString("status", "new");
    g_identity.username = prefString("username", "");
    g_identity.onionCount = prefString("onions", "0");
    g_identity.solanaPublicKey = prefString("sol_pub", "");
    g_identity.linked = g_prefs.getBool("linked", false);
}

static String bytesToHex(const uint8_t* data, size_t len) {
    static const char* hex = "0123456789abcdef";
    String out;
    out.reserve(len * 2);
    for (size_t i = 0; i < len; ++i) {
        out += hex[data[i] >> 4];
        out += hex[data[i] & 0x0F];
    }
    return out;
}

static bool prefsGetBytes(const char* key, uint8_t* out, size_t len) {
    if (!g_prefs.isKey(key)) return false;
    return g_prefs.getBytesLength(key) == len && g_prefs.getBytes(key, out, len) == len;
}

static String jsonEscape(const String& value) {
    String out;
    out.reserve(value.length() + 8);
    for (size_t i = 0; i < value.length(); ++i) {
        char ch = value[i];
        if (ch == '"' || ch == '\\') {
            out += '\\';
            out += ch;
        } else if (ch == '\n') {
            out += "\\n";
        } else if (ch == '\r') {
            out += "\\r";
        } else if (ch == '\t') {
            out += "\\t";
        } else {
            out += ch;
        }
    }
    return out;
}

static bool base64Decode(const String& input, std::vector<uint8_t>& out) {
    size_t olen = 0;
    int rc = mbedtls_base64_decode(nullptr, 0, &olen,
        reinterpret_cast<const unsigned char*>(input.c_str()), input.length());
    if (rc != MBEDTLS_ERR_BASE64_BUFFER_TOO_SMALL && rc != 0) return false;
    out.assign(olen, 0);
    rc = mbedtls_base64_decode(out.data(), out.size(), &olen,
        reinterpret_cast<const unsigned char*>(input.c_str()), input.length());
    if (rc != 0) return false;
    out.resize(olen);
    return true;
}

static String base64Encode(const uint8_t* data, size_t len) {
    size_t olen = 0;
    mbedtls_base64_encode(nullptr, 0, &olen, data, len);
    std::vector<uint8_t> out(olen + 1, 0);
    if (mbedtls_base64_encode(out.data(), out.size(), &olen, data, len) != 0) return String();
    return String(reinterpret_cast<const char*>(out.data())).substring(0, olen);
}
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
void loop() {
    handleSerial();
    handleButtons();
    sampleBattery();

    // Handle WiFi worker state transitions
    int wr = g_wifiWorkerResult.load();
    if (g_screen == SCREEN_WIFI_SCANNING) {
        if (wr == WIFI_WORKER_DONE) {
            g_wifiWorkerResult.store(WIFI_WORKER_IDLE);
            g_wifiListSel = 0;
            g_screen = SCREEN_WIFI_LIST;
            g_needsRedraw = true;
        } else if (wr == WIFI_WORKER_FAILED) {
            g_wifiWorkerResult.store(WIFI_WORKER_IDLE);
            g_wifiResultMsg = "Scan failed";
            g_screen = SCREEN_WIFI_RESULT;
            g_needsRedraw = true;
        }
    } else if (g_screen == SCREEN_WIFI_CONNECTING) {
        if (wr == WIFI_WORKER_DONE) {
            g_wifiWorkerResult.store(WIFI_WORKER_IDLE);
            g_prefs.putString("wifi_ssid", g_wifiConnectSsid.c_str());
            g_prefs.putString("wifi_pass", g_wifiPassBuf);
            g_config.wifiSsid = g_wifiConnectSsid;
            g_config.wifiPassword = String(g_wifiPassBuf);
            setLog("WiFi connected");
            g_wifiResultMsg = "Connected!";
            g_screen = SCREEN_WIFI_RESULT;
            g_needsRedraw = true;
        } else if (wr == WIFI_WORKER_FAILED) {
            g_wifiWorkerResult.store(WIFI_WORKER_IDLE);
            g_wifiResultMsg = "Connect failed";
            g_screen = SCREEN_WIFI_RESULT;
            g_needsRedraw = true;
        }
    }

    if (WiFi.status() != WL_CONNECTED && millis() - g_lastWifiAttempt > 30000) {
        g_lastWifiAttempt = millis();
        triggerWifiReconnect();
    }
    ensureMqtt();
    processCheckInService();

    if (millis() - g_lastHandshake > HANDSHAKE_INTERVAL_MS) {
        g_lastHandshake = millis();
        if (g_mqttConnected) doMqttHandshake();
    }

    // Periodic Onion-balance refresh. Handshakes only carry onionId/status, so
    // without this the displayed balance only updates on a manual "Refresh
    // Profile" or a fresh link — it goes stale as soon as the server total
    // changes. Quiet so an idle badge stays silent; skipped while offline or a
    // WiFi worker is busy so it never blocks the UI.
    if (WiFi.status() == WL_CONNECTED &&
        g_wifiWorkerResult.load() != WIFI_WORKER_RUNNING &&
        millis() - g_lastProfileRefresh > PROFILE_REFRESH_INTERVAL_MS) {
        g_lastProfileRefresh = millis();
        refreshPublicProfile(true);
    }

    redraw();
    delay(20);
}

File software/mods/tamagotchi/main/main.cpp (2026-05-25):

#include <Arduino.h>
#include <Wire.h>
#include <SPI.h>
#include <Preferences.h>
#include <esp_sleep.h>
#include <GxEPD2_BW.h>
#include <gdey/GxEPD2_270_GDEY027T91.h>
#include <Fonts/FreeMonoBold9pt7b.h>
#include <Fonts/FreeMonoBold24pt7b.h>
#include <Fonts/FreeMono9pt7b.h>

#include "badge_pins.h"

// ── I²C / buttons ─────────────────────────────────────────────────────────────
#define TCA9534_ADDR   0x20
#define TCA9534_INPUT  0x00
#define TCA9534_CONFIG 0x03

#define BTN_LEFT   (1 << 0)
#define BTN_DOWN   (1 << 1)
#define BTN_UP     (1 << 2)
#define BTN_RIGHT  (1 << 3)
#define BTN_SELECT (1 << 4)
#define BTN_CANCEL (1 << 5)

// ── Display ───────────────────────────────────────────────────────────────────
GxEPD2_BW<GxEPD2_270_GDEY027T91, GxEPD2_270_GDEY027T91::HEIGHT> display(
    GxEPD2_270_GDEY027T91(PIN_EPD_CS, PIN_EPD_DC, PIN_EPD_RST, PIN_EPD_BUSY));

// ── Pet constants ─────────────────────────────────────────────────────────────
#define MAX_STAT        10
#define TICK_US         (30ULL * 60 * 1000000)  // 30-min timer wakeup
#define SLEEP_AFTER_MS  45000                    // idle → deep sleep
#define SICK_CHANCE_PCT 5                        // % chance of random sickness per tick

// Stage transitions (age in 30-min ticks): EGG<3, BABY<48, CHILD<144, TEEN<336, ADULT
enum Stage : uint8_t { STAGE_EGG=0, STAGE_BABY, STAGE_CHILD, STAGE_TEEN, STAGE_ADULT };
static const uint32_t STAGE_MIN_TICKS[] = { 0, 3, 48, 144, 336 };
static const char*    STAGE_NAMES[]     = { "EGG", "BABY", "CHILD", "TEEN", "ADULT" };

static const char* PET_NAMES[] = { "KERNEL", "HEXBIT", "DAEMON", "PACKET" };
#define PET_NAME_COUNT 4

enum Action : uint8_t { ACTION_FEED=0, ACTION_PLAY, ACTION_SLEEP, ACTION_MED };
static const char* ACTION_LABELS[] = { "FEED", "PLAY", "SLEEP", "MED " };
#define ACTION_COUNT 4

// ── Pet state ─────────────────────────────────────────────────────────────────
struct PetState {
    uint8_t  hunger;
    uint8_t  happiness;
    uint8_t  energy;
    uint8_t  health;
    uint32_t age_ticks;
    uint8_t  stage;
    uint8_t  name_idx;
    bool     alive;
    bool     sleeping;
};
static PetState g_pet;

// ── App state ─────────────────────────────────────────────────────────────────
static bool    g_needs_redraw    = true;
static uint8_t g_last_btns       = 0;
static int     g_action          = ACTION_FEED;
static uint32_t s_last_activity;
static bool    g_just_hatched    = false;  // show hatch screen on next render
static bool    g_just_slept      = false;  // true only when SLEEP action was pressed this session

// Survive deep sleep
RTC_DATA_ATTR bool rtc_valid        = false;
RTC_DATA_ATTR bool rtc_just_hatched = false;  // set by timer tick, shown on button wake

// ── Helpers ───────────────────────────────────────────────────────────────────
static inline uint8_t cstat(int v) {
    return v < 0 ? 0 : v > MAX_STAT ? MAX_STAT : (uint8_t)v;
}

static uint8_t stage_for(uint32_t ticks) {
    for (int i = 4; i >= 0; i--)
        if (ticks >= STAGE_MIN_TICKS[i]) return (uint8_t)i;
    return STAGE_EGG;
}

// ── NVS ───────────────────────────────────────────────────────────────────────
static void load_pet() {
    Preferences p;
    p.begin("tama", true);
    g_pet.hunger    = p.getUChar("hunger",  MAX_STAT);
    g_pet.happiness = p.getUChar("happy",   MAX_STAT);
    g_pet.energy    = p.getUChar("energy",  MAX_STAT);
    g_pet.health    = p.getUChar("health",  MAX_STAT);
    g_pet.age_ticks = p.getUInt ("age",     0);
    g_pet.name_idx  = p.getUChar("name",    (uint8_t)(esp_random() % PET_NAME_COUNT));
    g_pet.alive     = p.getBool ("alive",   true);
    g_pet.sleeping  = p.getBool ("sleep",   false);
    p.end();
    g_pet.stage = stage_for(g_pet.age_ticks);
}

static void save_pet() {
    Preferences p;
    p.begin("tama", false);
    p.putUChar("hunger", g_pet.hunger);
    p.putUChar("happy",  g_pet.happiness);
    p.putUChar("energy", g_pet.energy);
    p.putUChar("health", g_pet.health);
    p.putUInt ("age",    g_pet.age_ticks);
    p.putUChar("name",   g_pet.name_idx);
    p.putBool ("alive",  g_pet.alive);
    p.putBool ("sleep",  g_pet.sleeping);
    p.end();
}

static void reset_pet() {
    Preferences p;
    p.begin("tama", false);
    p.clear();
    p.end();
    load_pet();  // reloads with fresh defaults
}

// ── Stat tick (runs on every 30-min timer wakeup) ─────────────────────────────
static void tick_stats() {
    if (!g_pet.alive) return;

    uint8_t old_stage = g_pet.stage;
    g_pet.age_ticks++;
    g_pet.stage = stage_for(g_pet.age_ticks);
    if (old_stage == STAGE_EGG && g_pet.stage == STAGE_BABY) rtc_just_hatched = true;

    if (g_pet.sleeping) {
        g_pet.energy    = cstat(g_pet.energy    + 3);
        g_pet.happiness = cstat(g_pet.happiness + 1);
        if (g_pet.energy >= MAX_STAT) g_pet.sleeping = false;
    } else {
        g_pet.hunger = cstat(g_pet.hunger - 1);
        g_pet.energy = cstat(g_pet.energy - 1);
    }

    g_pet.happiness = cstat(g_pet.happiness - 1);

    if (g_pet.hunger    == 0) g_pet.health = cstat(g_pet.health - 2);
    if (g_pet.happiness == 0) g_pet.health = cstat(g_pet.health - 1);

    if ((esp_random() % 100) < SICK_CHANCE_PCT)
        g_pet.health = cstat(g_pet.health - 2);

    if (g_pet.health == 0) g_pet.alive = false;
}

// ── Button read ───────────────────────────────────────────────────────────────
static uint8_t read_buttons() {
    Wire.beginTransmission(TCA9534_ADDR);
    Wire.write(TCA9534_INPUT);
    Wire.endTransmission(false);
    Wire.requestFrom(TCA9534_ADDR, 1);
    return (~Wire.read()) & 0x3F;
}
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

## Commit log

2026-04-07 feat: schematic, pcb design and 3D design for main badge and external modules in panel
    [null-city-badge.kicad_pcb, null-city-badge.kicad_sch]
2026-04-21 feat: improve pinout and remove sdcard and lora module, update design
    [CC1101_MOD.kicad_sch, SOUND_MOD.kicad_sch, bom-list.xlsx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]
2026-05-07 fix sub ghz, epaper and audio module
    [CC1101_MOD.kicad_sch, SOUND_MOD.kicad_sch, bom-list_lanyard.xlsx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]
2026-05-24 docs: add README, hardware/pinout/module docs, and software contribution structure
    Document the NULL City Badge (ESP32-S3-WROOM-1) and set up the repo for
    community software contributions.
    Documentation (docs/):
    - HARDWARE.md: subsystem walkthrough — MCU + strapping pins, CH340C USB/UART
    and auto-reset, peripheral power gate (Q5/GPIO18), I2C bus with TCA9534
    register reference, boot circuit, J4 display socket, PB1-PB6 button matrix,
    ATECC608B secure element, J8/J10 expansion ports, manufacturing outputs.
    - PINOUT.md: markdown mirror of "pcb/null badge.html" — full GPIO/net/
    direction/peripheral map plus a GPIO-sorted cross-reference.
    - MODULES.md: swappable CC1101 / Sound / SD /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
2026-05-24 docs: drop SD Card and LoRa modules — not in final shipped layout
    The SD Card and LoRa modules were removed from the design (see commit
    fcf4da8) and are not populated on shipped badges. The final layout has
    exactly two flexible modules: CC1101 and Sound.
    Remove all SD/LoRa references from README, MODULES, HARDWARE, CONTRIBUTING,
    and the PR template so the docs reflect only what ships. (The NS4168 "SD"
    pin name in the audio docs is the amp's serial-data input, not an SD card.)
    The legacy SDCARD_MOD.kicad_sch / LORA_MOD.kicad_sch schematic files remain
    in pcb/ but are no longer referenced as shipping modules.
2026-05-25 Add tamagotchi mod — virtual pet with onion creature and deep sleep
    Five evolution stages (Egg → Baby → Child → Teen → Adult), four
    stats (Hunger, Happiness, Energy, Health), and a 30-min RTC timer
    wakeup that ticks stats without waking the display. SSD1680 partial-
    window refresh drives a 2-frame dancing animation. CANCEL button
    advances the stage for testing.
2026-05-27 Migrate firmware to ESP-IDF, vendor display libs, add case, rebrand to oniondao-badge
    Build system: move both firmware projects (basic-menu example and tamagotchi
    mod) from PlatformIO to ESP-IDF + arduino-esp32, matching the toolchain the
    hardware is locked to (ESP-IDF 5.5.4 <-> arduino-esp32 3.3.8).
    - Delete platformio.ini; add CMakeLists.txt (root + main/), main/idf_component.yml
    (pulls arduino-esp32 3.3.8 from the component registry), partitions.csv, and
    sdkconfig.defaults per project.
    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
    [SOUND_MOD.kicad_sch, badge.skp, null-city-badge.kicad_pcb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]
2026-05-27 Fix callsign editor truncation and RSSI overwrite bugs
    Callsign editor was null-terminating at cursor position on SELECT,
    chopping everything after the first edited character. Removed the
    truncation — save_callsign() trailing-space trim handles cleanup.
    upsert_peer() was overwriting RSSI with hardcoded -50 on every received
    packet, stomping values set by on_promisc(). RSSI is now only written
    on first peer discovery; on_promisc() owns all subsequent updates.
    [main.cpp]
2026-05-27 Phase 2: PSRAM attendance log — 500 peers, 200 inbox, LOG tab
    - g_peers (10→500) and g_inbox (5→200) allocated from PSRAM via
    heap_caps_malloc; fallback to heap if PSRAM unavailable
    - PeerEntry gains first_seen; InboxEntry gains timestamp
    - Peer table preserved across shutdown_espnow() — functions as
    conference attendance log; inbox still resets per session
    - New LOG tab (4th tab, RIGHT of INBOX) shows all encountered peers
    with callsign, RSSI, first-seen and last-seen relative times;
    UP/DOWN scrolls 4-entry pages
    - INBOX tab gains UP/DOWN scrolling for 200-entry history; page
    counter shown in content area when more than 3 entries exist
    - Tab cycling updated to mod-4 (LEFT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
    [main.cpp]
2026-05-27 Phase 4: CTF Capture the Badge game with ECDSA challenge-response
    - Add MSG_CHALLENGE and MSG_CAP_TOKEN to MsgType enum
    - CaptureRecord struct: mac, name, timestamp, verified flag
    - g_captures[50] allocated from PSRAM; g_capture_count tracks badges
    captured; g_captured_count tracks how many times we were captured
    - PEERS tab TARGET menu grows from 2 to 3 options: PING/MESSAGE/CAPTURE
    - CAPTURE flow:
    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
2026-05-31 badge-ui-cleanup: streamlined menu, no messaging, faster buttons
    Menu (8 items → 2):
    - Removed: Button Test, I2C Scanner, RNG/Crypto, Display Test,
    Hardware Guide, Software Guide
    - System Info now runs I2C scan + generates 16 RNG bytes inline,
    showing chip model, MAC, heap/PSRAM, I2C devices, and random bytes
    on a single screen
    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
2026-05-31 Fix System Info layout + add ping blocking
    System Info:
    - Split into 2 pages (L/R to flip): page 1 = hardware specs,
    page 2 = I2C devices + 16 RNG bytes
    - Use consistent 18px line spacing throughout (eliminates text overlap)
    - RNG generated fresh on screen entry, stored in g_sysinfo_rng[]
    Ping blocking:
    - PeerEntry gains blocked bool field
    - on_recv(): pings from blocked peers are silently dropped (no pong sent)
    - PEERS tab: [B] indicator shown at x=161 for blocked peers
    - Target menu: PING / CAPTURE / BLOCK (or UNBLOCK if already blocked)
    pressing SELECT on BLOCK toggles the flag and returns to PEERS tab
    [main.cpp]
2026-05-31 Ping security: known-peer check, rate limiting, auto-block
    Three-layer protection against malicious ping flooding:
    1. Known-peer filter: pings from MACs that never sent a beacon are
    silently ignored. Attackers must announce themselves first.
    2. Rate limiting: PING_RATE_LIMIT=5 pings per 10-second window tracked
    per peer using ping_count + ping_window_start in PeerEntry. Window
    resets automatically after PING_WINDOW_MS (10 000 ms).
    3. Auto-block: exceeding the rate limit sets peer.blocked=true, same
    as the manual BLOCK option. Badge shows [B] in PEERS tab and
    triggers a redraw. User can still manually unblock via target menu.
    Also includes the fix from the prior commit (une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
    [main.cpp]
2026-05-31 Remove INBOX tab — tabs are now BCN / PEERS / LOG / SCORE
    - Removed InboxEntry struct, MAX_INBOX constant, g_inbox / g_inbox_count
    / g_inbox_cursor globals, inbox PSRAM allocation in setup()
    - Removed inbox ring-buffer push in on_recv()
    - Removed draw_espnow_inbox() and its case from draw_espnow()
    - Tab bar updated: 5 tabs → 4 (BCN PEERS LOG SCORE)
    - Tab cycling updated: % 5 / +4 → % 4 / +3
    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
2026-05-31 Security review fixes (8 findings)
    1. Null-ptr hard fault: add explicit panic loop if g_peers or
    g_captures allocation fails instead of memset(nullptr)
    2. ping_count overflow: uint8_t → uint16_t prevents wrap-to-zero
    after 255 pings that would bypass the auto-block rate limiter
    3. Torn multi-byte struct reads (dual-core race): add portMUX_TYPE
    g_espnow_mux spinlock; protect g_pong_mac, g_challenge_msg/mac,
    and g_pending_verify/ver_mac writes in on_recv with
    portENTER_CRITICAL_ISR; reads in loop() copy to locals under
    portENTER_CRITICAL before doing any slow work (crypto, I2C)
    4. Unterminated name strings from untrusted beacons: force
    name[sizeof(name)-1]='\0' after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
    [main.cpp]
2026-06-02 Fix firmware build under ESP-IDF v5.5.4 / arduino-esp32 3.3.8
    The basic-menu-adjustable-homescreen firmware did not build as committed.
    Three issues, surfaced one after another once each blocker was cleared:
    1. Vendor the SparkFun ATECCX08a Arduino library. main.cpp includes
    <SparkFun_ATECCX08a_Arduino_Library.h> for the ATECC608B secure element,
    but the library was never committed alongside the other vendored Arduino
    libs (GxEPD2, Adafruit_*). Added it under software/components/ following
    the same packaging pattern and added it to the main component's REQUIRES.
    2. Update the ESP-NOW receive callback to the arduino-esp32 3.x signature.
    esp_now_register_recv_cb now expects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
    [main.cpp]
2026-06-03 Add Solana wallet QR code feature
    - Generate Ed25519 keypair using ATECC608B hardware TRNG as entropy
    source (falls back to ESP32 hardware RNG if chip unavailable)
    - Store 32-byte seed in NVS for persistence across reboots — same
    wallet address every boot
    - Base58-encode Ed25519 public key to produce standard Solana address
    - Render wallet address as QR code on e-paper display using
    espressif__qrcode component (version 4, ECC_MED, 2× scaled modules)
    - Show abbreviated address (first 6…last 6 chars) below QR code
    - Add "3. Solana Wallet" menu item; SELECT regenerates wallet (new NVS
    seed), CANCEL returns to menu
    - Link espressif__libsodium, espressif__qrcode, nvs_flash in
    CMake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
    [main.cpp]
2026-06-03 Add MQTT chat and finalize Solana wallet feature
    - Wire MQTT chat feature: added mqtt_client.h include and mqtt_config.h
    with broker URI, WiFi creds, and topic definitions
    - Add STATE_WALLET_SIGN, STATE_MQTT, STATE_MQTT_EDIT app states
    - Add ping-server example firmware for connectivity testing
    - Wallet is persistent (NVS-backed seed, no regeneration path)
    [partitions.csv]
2026-06-03 Add Onion OS badge firmware
    Build a new ESP-IDF Onion OS target for the ESP32-S3 badge with hardcoded CIC Guest WiFi, HTTP/MQTT badge handshake support, link approval, transaction approval, server-pushed Lua script approval, an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
    Implement badge wallet custody with a software Ed25519 Solana key whose seed is wrapped through an ATECC-backed HMAC-derived key, and include ATECC HMAC attestations on link and transaction approvals.
    Add the e-paper UI flow: logo boot splash, home status menu with linked username and Onion balance, script explorer, script sync, profile refresh, and approval screens for profile linking, token tran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
    [badge-v2.skp, badge-v2.stl, badge-v2~.skp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]
2026-06-03 Expand Onion OS Lua and asset support
    Hardcode the badge API base URL to https://oniondao.dev while keeping the runtime API key configurable via the serial api-key command.
    Add manifest-driven bitmap asset downloads for PBM and uncompressed BMP files, store them in SPIFFS, and expose Lua display helpers for clearing the e-paper panel and rendering downloaded bitmaps.
    Expose read-only Lua GPIO helpers for side-port expansion pins with bounded polling and optional input, pull-up, and pull-down modes so downloaded scripts can safely inspect external hardware.
    Keep Lua-rendered display content active until the next button press, document the new script APIs, and update manifest examples for i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
2026-06-03 Hardcode Onion OS MQTT proxy and add script examples
    Hardcode the badge MQTT broker to mqtt://shortline.proxy.rlwy.net:20928 so runtime config can no longer drift from the Railway TCP proxy. Keep MQTT credentials and topic prefix configurable through a new mqtt-auth serial command, while preserving compatibility with the old mqtt command by ignoring a URI-looking first argument.
    Document the fixed MQTT endpoint in the Onion OS README and config example, including the updated serial command usage.
    Add Lua-facing display ownership, bitmap enumeration, button polling, button mask, and bounded sleep helpers needed for interactive image scripts.
    Add a local scripts directory with an image-brow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
    [main.cpp]
2026-06-04 Add secure RNG, HTTP/MQTT, and Sub-GHz/Sound modules to Lua engine
    Expose new capabilities to the onion Lua table:
    - secure_random: ATECC608A hardware RNG
    - http_get/http_post: HTTPS via esp_http_client (root-CA verified)
    - mqtt_*: publish/subscribe/receive over the badge MQTT bridge, with a
    thread-safe inbound queue and wildcard topic matching
    - subghz_*: CC1101 Sub-GHz high-level radio (begin/transmit/receive/
    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
2026-06-05 fix: accepts both scripts_foo.lua and /scripts_foo.lua and normalises them to always have the / prefix, this cause the script not loading in script explorer
    [main.cpp]
2026-06-05 fix: scan failure caused by background reconnect interfering with the scan driver
    [main.cpp]
2026-06-05 fix: every screen update triggers a full-panel e-ink refresh, change it to partial refresh
    [main.cpp]
2026-06-06 fix: bad mqtt json on big payload, adding missing docs in README.md
    [main.cpp]
2026-06-06 Extend Lua engine for real-time streaming voice apps
    Make the onion Lua table capable of supporting walkie-talkie-style
    apps that stream PTT voice between badges over ESP-NOW:
    - sound_mic_begin gains dma_desc/dma_frame options for deep capture
    buffering (~512 ms at 16 kHz vs the ~90 ms driver default),
    discard_ms to drop the PDM startup transient, and ws/ctrl pin
    overrides; capture uses 16x PDM downsampling on the left slot and
    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
2026-06-06 feat: expanded Lua API, battery icon, nav fix
    - Add display_begin/commit/flush for batching Lua draw calls into a
    single e-ink refresh, eliminating per-call partial flashes
    - Add vector drawing primitives: display_circle, display_triangle,
    display_round_rect, display_pixel
    - Add persistent KV storage: kv_set, kv_get, kv_delete, kv_list
    (NVS namespace "luakv"); survives reboots and firmware updates
    - Add timing helpers: millis(), time(), time_synced(); SNTP init
    triggered on first WiFi connect
    - Add battery icon (top-right header): proportional fill when ADC
    is wired, centred dash when PIN_BATTERY_ADC = -1
    - Fix: BTN_RIGHT no longer opens Script Explorer unconditionally
    from the m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
    [main.cpp]
2026-06-06 fix: boot splash, battery cleanup, script delete confirmation
    - Regenerate logo_bitmap.h from updated logo.png — previous bitmap was
    all zeros; new one converts the full logo (onion icon, ONION DAO,
    POWERED BY, Solana Foundation) to crisp 1-bit at 264x176
    - Update logo.png: flatten alpha, convert gray "POWERED BY" text to
    solid black so it renders correctly on e-ink
    - Remove unused batteryStatusText() and drawBatteryIcon() functions and
    their associated globals (PIN_BATTERY_ADC = -1, hardware not wired)
    - Add SCREEN_DELETE_CONFIRM: pressing LEFT on a script in the explorer
    now shows a confirmation screen with CANCEL (default) and DELETE
    buttons; L/R navigates between them, SELE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
    [main.cpp]
2026-06-07 Auto-refresh the Onion balance and fix the displayed field
    The badge's "Onions" total could disagree with the dev portal (e.g.
    badge 1500, portal 2500) for two independent reasons, both fixed here:
    - It never re-synced on its own. Boot and the 30s timer only run
    handshakes, which carry just onionId/status — not the balance. The
    balance moved only on a manual "Refresh Profile" or a fresh link, so
    it went stale as soon as the server total changed. Now setup() fetches
    the profile once at boot, and loop() does a quiet refresh every
    PROFILE_REFRESH_INTERVAL_MS (60s): it stays silent (no status-line
    churn, redraws only when the value changed) and is skipped while
    offline or a WiFi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
    [main.cpp]
2026-06-08 check in beacon
    [partitions.csv]
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
